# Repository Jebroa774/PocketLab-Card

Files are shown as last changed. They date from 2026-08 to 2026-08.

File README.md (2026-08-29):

# PocketLab Card V1

<p align="center">
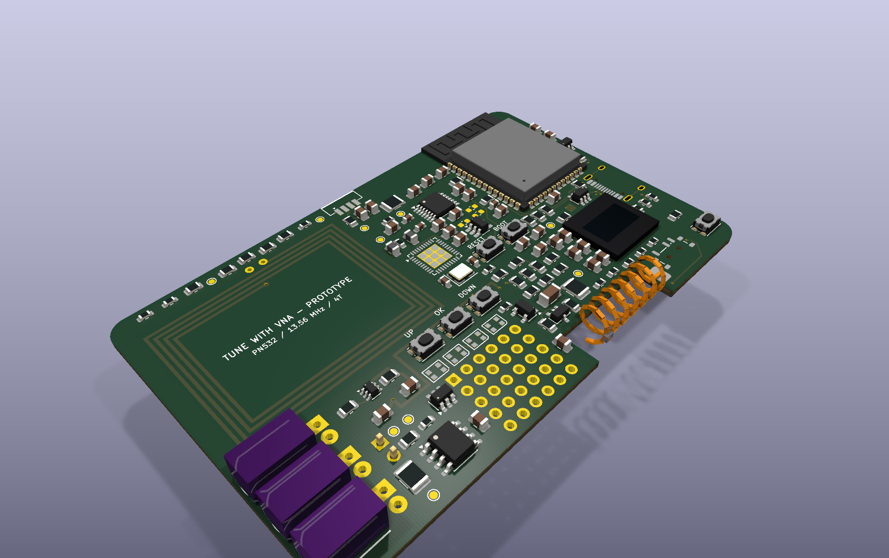
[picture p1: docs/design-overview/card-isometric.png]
PocketLab Card V1 current KiCad isometric view
  
</p>

PocketLab Card V1 is an original, credit-card-outline ESP32-S3 field tool with
Wi-Fi/BLE control, NFC, LF RFID, Sub-GHz, infrared, removable storage and a
small local user interface. The hardware is designed around a four-layer PCB,
a single-cell LiPo supply and parts that can be assembled by JLCPCB or fitted by
hand where practical.

> [!NOTE]
> **Proudly vibe-coded.** The project grows through hands-on experimentation,
> rapid idea-driven iteration and AI-assisted engineering. Here, vibe coding
> does not mean blindly trusting generated output: the hardware remains an
> engineering prototype until its schematic, PCB, DRC/DFM results and physical
> measurements have been independently checked.

> [!WARNING]
> **Engineering prototype — not ready to order.** Placement and electrical
> connectivity are complete: the current routing checkpoint has 0 open
> connection items. It still has 1,164 DRC findings in the saved median run,
> so DRC/DFM cleanup, RF/LF tuning, sourcing review and prototype measurements
> remain required before fabrication.

## Current hardware

| Area | V1 implementation |
|---|---|
| Controller | ESP32-S3-WROOM-1-N8R2 with native USB, Wi-Fi and BLE |
| 13.56 MHz NFC | PN532 with a project-local 35 x 27 mm four-turn PCB antenna |
| 125 kHz LF RFID | HTRC110 front end with a removable, measurable and tuneable coil |
| Sub-GHz | E07-900MM10S/CC1101 module, tuneable pi network and inboard 868 MHz spring antenna |
| Infrared | Three independent high-power 940 nm emitters plus a 38 kHz receiver |
| Storage and security | microSD, ATECC608C secure element and physical PAIR button |
| User interface | Four RGB LEDs, UP/SELECT/DOWN controls and a firmware-configurable AUX button |
| Sensors | Optional 6-axis IMU, barometer, RTC, fuel gauge and board-temperature monitor |
| Power | USB-C, 1-cell LiPo input, charging/power path, regulated 3.3 V and switchable 5 V |
| Expansion | Protected 2.54 mm breakout matrix with eleven direct expansion GPIOs |

The **ESP32-S3 remains the controller for V1**. The newer ESP32-S31 is being
kept as a possible V2 candidate, but its preliminary hardware ecosystem,
larger WROOM module and immature availability do not justify restarting this
layout.

## Current PCB views

The following images were generated from the current KiCad routing checkpoint.
The hand-fitted IR bodies and spring antenna use approximate preview models;
footprints, courtyards and the PCB outline remain the mechanical references.

<table>
  <tr>
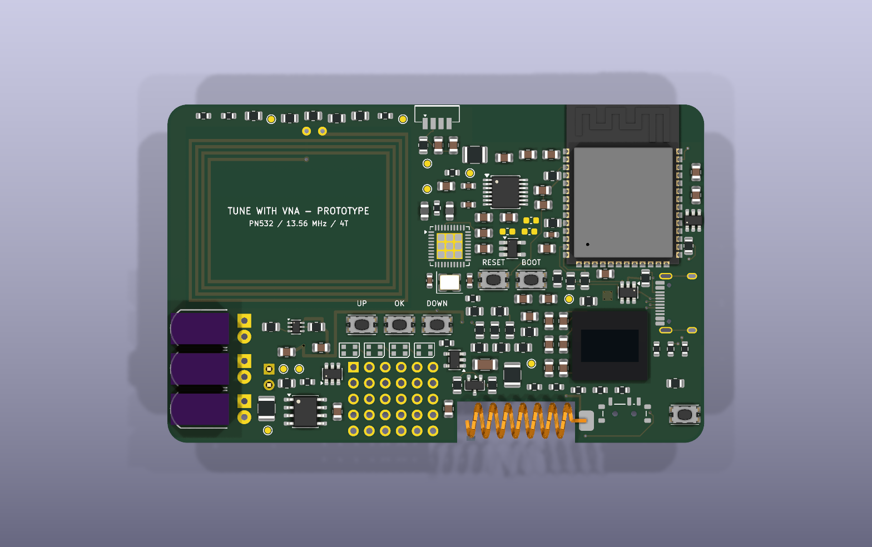
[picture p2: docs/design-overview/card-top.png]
Current PCB top view
    <td align="center"><br><strong>Top</strong></td>
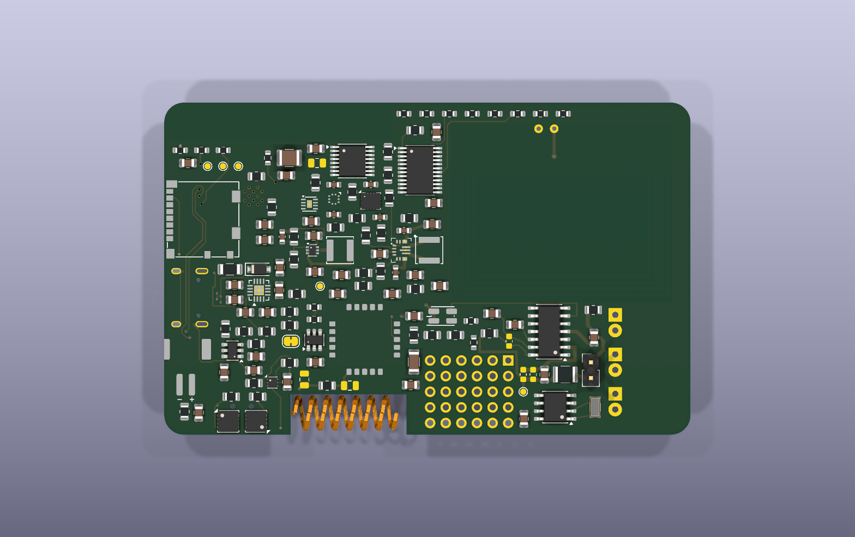
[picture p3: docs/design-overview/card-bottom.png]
Current PCB bottom view
    <td align="center"><br><strong>Bottom</strong></td>
  </tr>
</table>

More layout and enclosure notes are available in the
[design overview](docs/design-overview/README.md).

## Mechanical target

- 85.60 x 53.98 mm credit-card outline with rounded corners
- Four-layer, nominal 1.2 mm FR-4 using the JLC04121H-7628 stack target
- 1 oz outer and 0.5 oz inner copper with ENIG finish
- Components on both sides; approximately 8–9 mm provisional assembled height
- Three inboard edge-facing IR emitters and an inboard spring-antenna pocket
- Compact unpopulated 6 x 5 matrix of 30 holes on 2.54 mm pitch
- Initial bring-up quantity: five assembled prototype boards

This is a credit-card-shaped instrument, not a wallet-thickness card. The final
height and enclosure clearances must be verified against received components.

## Engineering status

| Check | Current result |
|---|---:|
| Schematic symbols | 274 |
| Assigned footprints | 267 |
| Named logical nets | 181 |
| Physical PCB nets | 231 |
| ERC | 0 errors / 0 warnings |
| Placed footprints | 267 / 267 |
| Routed checkpoint | 2843 track segments / 575 vias / 23 zones |
| Remaining connection items | 0 |
| DRC findings (median of three runs) | 1164 |
| Footprint-library comparison findings | 5 |

Completed design work includes the full schematic, mechanical placement,
four-layer stack definition, native USB pair, local converter routes, RTC
crystal routes, the provisional Sub-GHz feed/pi network and the via-free
back-side LF RFID analog island. All logical connection items are now closed;
the active work is reducing the remaining clearance, hole-clearance, short,
crossing, solder-mask and board-edge DRC findings.

### Before the first PCB order

- Confirm the live JLCPCB stack and recalculate USB/Sub-GHz geometry.
- Review the completed LF/NFC and digital routing against the schematic.
- Finish DRC cleanup, ground stitching and plane review.
- Re-run final KiCad DRC/parity checks from a clean checkout.
- Review every footprint, BOM and placement entry against current supplier data.
- Reconfirm PN532 availability because the part is NRND, and qualify an
  alternative before any production revision.
- Inspect the JLCPCB DFM, BOM and CPL previews and obtain an independent review.
- Tune NFC, LF RFID and Sub-GHz on the assembled prototypes with suitable test
  equipment before treating any RF values as production-ready.

The detailed hand-off state is maintained in the
[work checkpoint](docs/work-checkpoint.md).

## Repository layout

```text
PocketLab-Card/
|-- docs/           Architecture, constraints, checkpoints and current renders
|-- hardware/       KiCad source, local libraries, reports and layout helpers
|-- firmware/       ESP32-S3 firmware source and board configuration
`-- manufacturing/  Fabrication/assembly generation tools and future releases
```

Open `hardware/PocketLab-Card.kicad_pro` in KiCad 10 for the complete project.
The tracked `hardware/PocketLab-Card.kicad_pcb` is the current routing-in-progress
board, not a fabrication release.

## Responsible use

RF, RFID/NFC and infrared functions are intended only for devices, systems,
frequencies, antennas, output levels and duty cycles the operator is legally
permitted to use. Prototype RF performance, electromagnetic compatibility and
regulatory compliance have not yet been verified.

The project is original and does not copy SGP branding, artwork, PCB layout or
firmware.

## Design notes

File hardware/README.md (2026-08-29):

# Hardware design source

## Functional blocks

| Logical block | Contents |
|---|---|
| 00_ROOT | Power domains, buses and hierarchical connections |
| 01_USB_POWER | USB-C, ESD, charger, battery, 3.3 V and 5 V conversion |
| 02_MCU | ESP32-S3-WROOM-1 module, boot/reset and native USB |
| 03_NFC | PN532, clock, matching/RX networks and four-turn PCB loop |
| 04_SUBGHZ | E07-900MM10S CC1101 module, tuneable pi network and inboard spring antenna |
| 05_LF_RFID_SD | HTRC110, removable 125 kHz coil, level shifting, ATECC608C, PAIR and microSD |
| 06_IR_UI | IR transmitter/receiver, RGB LEDs and buttons |
| 07_SENSORS_IO | IMU, barometer, RTC, fuel gauge, U9/U18 and headers |

KiCad 10 is installed locally. `PocketLab-Card.kicad_pro` is the project entry
point and the PCB scaffold contains the exact credit-card outline. The current
generated schematic comprises 267 symbols and 176 named logical nets; the
OLED-free PCB candidate contains 260 footprints. `reports/erc-nooled-aux.rpt` reports zero
errors and zero warnings.

The schematic and its machine-readable net description are reproducible with
KiCad's bundled Python:

```powershell
& "$env:LOCALAPPDATA\Programs\KiCad\10.0\bin\python.exe" scripts/generate_schematic.py PocketLab-Card.kicad_sch --design-json design-netlist.json
```

The project-local footprint library includes the manufacturer-derived special
packages and `NFC_Loop_35x27mm_4T_TUNE`. The latter is a four-turn, 0.50/0.50
mm preliminary loop with a 35 x 27 mm copper envelope and a full 36 x 29 mm
all-copper-layer keep-out. Its matching is intentionally not a release value:
measure and tune the populated prototype with the final stack-up, enclosure and
battery using a VNA or suitable NFC fixture.

The tracked `PocketLab-Card.kicad_pcb` remains the authoritative design source.
`PocketLab-Card-routing-working.kicad_pcb` is the explicitly named active routing
checkpoint and is kept only so the verified zero-open state can be resumed without
promoting it prematurely. Other generated placement, plane, autorouter and
routing-progress boards are deliberately not versioned because the scripts below
recreate them from the schematic, mechanical template and current rules.

The current PCB contains the guarded digital autorouter fanout plus reviewed local U6/L6,
U7/L7, converter input/output, U7-feedback, RTC-crystal and complete native USB
data routes; L2 remains the uninterrupted ground plane and L3 retains the
power polygons plus explicitly reviewed low-speed signal crossings. R201/R202 are vertical side-by-side 0805
parts, the MCU-side pair stays via-free, and a staggered five-via bridge joins
J1's alternating A/B data pads. U16 is 0.55 mm farther inboard; front-side
0805 R102 now has its J1-B5 pull-down and local ground return routed. The CC2
protection branch to U16 pin 6 is also complete using two ordinary 0.50/0.30-mm
through vias and outer-layer tracks only. SW3/SW7/SW4 are compact, adjacent UP/OK/DOWN
controls; SELECT uses U9/P07 and the BMP390 remains available by I2C polling.
VSYS is now complete through the charger/converter island; an 0805 zero-ohm
SPI_MOSI crossover preserves the plane-only inner layers. Both J1 VBUS contacts
also reach F1 through reviewed local neckdowns and 0.50/0.60-mm B.Cu copper.
The provisional 868-MHz feed now runs through the correctly oriented pi network
and makes its sole signal-layer transition before the spring pocket; its F.Cu
section remains on the narrow PCB bridge outside the notch. The present
checkpoint has 1889 track segments, 343 vias and 23 zones. Both `+5V_RAW` and
`+5V_AUX` are complete on narrow L3 corridors, the requested 36 dense-plane
clusters are closed, and the reviewed U2.3 GND escape is routed. R405 is
oriented with pad 1 toward U3 and pad 2 toward the antenna. The microSD socket
is now 0.175 mm farther inboard, eliminating its ten copper-to-edge findings.
J5.25 now reaches the complete U25/R732 `SPI_SCK_HDR` protection tree through
a reviewed short L3 crossing. J5.23 reaches U24.1 on `I2C_SDA_HDR`; its separate
R730 branch remains in the ratsnest. A single reviewed `+5V_RAW` stitch via
keeps the power polygon connected around the SCK clearance slot, and L2 remains
ground-only.
The short PN532 `/NFC_TX2_F` matching branch from L302.2 to C309.1 is now
routed via-free on F.Cu through the reviewed 0.25-mm local corridor.
The microSD controller-side `/SD_CS_DEV` leg now reaches J2.2 through one local
via; the adjacent U19.2 GND escape was shifted toward the card edge without
changing its reviewed plane via.
The ESP32 `/SPI_MOSI` pad U1.19 now reaches the existing U21/R129 shared-bus
trunk through eight locked outer-layer segments and one 0.45/0.20-mm via.
R511.1 now joins that same trunk through six locked 0.15-mm L3 segments, one
short F.Cu escape and one 0.45/0.20-mm via. The route preserves the continuous
L2 ground plane and the connectivity of both protected L3 5-V polygons.
The USB-C `/USB_CC1` receptacle pad J1.A5 now reaches its back-side 5.1-kohm
pull-down R101 through one outer-layer transition. U16.4 now joins that same
group through nine locked 0.20-mm F.Cu segments, so the complete CC1 detection
and ESD branch is connected without another via.
The UP-button `/USER_BUTTON_A_N` contact SW3.1 now reaches pull-up R608.1
through one short reviewed L3 crossing and two 0.45/0.20-mm vias; U18.11
remains the explicit second group on that net.
The back-side `/CELL_POS` monitor input U8.3 now reaches local capacitor C120.1
through four short, via-free 0.15-mm B.Cu segments.
The back-side `/CELL_POS` sense input R104.1 now joins the charger/battery
branch through three locked 0.20-mm B.Cu segments, one 0.45/0.20-mm tented via
and five locked 0.20-mm F.Cu segments. The route uses the narrow reviewed gap
between C101 and C117 without cutting any inner-layer power polygon.
The protected `/GPIO43` output R718.2 now reaches expansion-header pad J5.11
through three locked 0.15-mm L3 segments and one 0.45/0.20-mm tented via.
The protected `/SPI_MISO_HDR` branch now joins resistor R734.2 to J5 ESD-array
channel U25.1 through eleven locked 0.15-mm segments, two 0.45/0.20-mm tented
vias and a reviewed L3 corridor; the dedicated L2 GND plane remains untouched.
The PN532 `/NFC_TX1` driver pad U2.4 now reaches matching inductor L301.1
through two short F.Cu escapes, three locked 0.20-mm L3 segments and two
0.45/0.20-mm tented vias. Small reviewed jogs in the neighboring LF clock/data
fanouts preserve their connectivity and keep the dedicated L2 GND plane clean.
The active routing checkpoint contains 2843 track segments, 575 ordinary through
vias and 23 zones. Three fresh KiCad DRC runs report zero open connections and
totals between 1162 and 1166 remaining violations (median 1164). The latest cleanup
reroutes EX4, EX5, CHG_TS_FIXED, GPIO8_MCU and SD_DETECT_N, reassigns CHARGER_CHG_N,
and rehomes the AUX5_FAULT_N and BAT_SENSE vias while preserving connectivity.
The earlier cleanup merges one
redundant same-net NFC_OSCOUT via pair, rehomes two crowded GND vias and eliminates
the remaining hole-to-hole findings (three to zero). A CHG_TS L3 detour reduces the
copper-to-edge findings from five to four. Small conventional-through-via rehomes
also improve CHG_ITERM, NFC_DVDD and IR_TX while preserving the long IR_TX inner
trace; no blind or microvias were introduced. The earlier cleanup removes the PWR
copper sliver and both GPIO8-to-rounded-corner edge findings without introducing a
keepout violation. It also merges redundant BAT_SENSE, NFC_SVDD and SD_SCK via
pairs and makes the local USB_CONN_P join via-free.
The remaining violations still require grouped cleanup; the board is therefore not
an order-ready fabrication release.
The matching machine-readable report is `reports/PocketLab-Card-drc.json`.

The latest PN532 cleanup connects U2.5/U2.8 with a short via-free DVDD escape
and replaces the old west-side U2.3 GND detour with a direct exposed-pad
connection. `scripts/route_nfc_dvdd_escape.py` reproduces that reviewed stage.

The LF_RFID_EN branch now reaches U22.1 through a reviewed L3 signal corridor.
The change reuses the former redundant +3V3 via site, reconnects R109 to the
retained +3V3 fanout and leaves L2 as a ground-only plane.
`scripts/route_lf_enable.py` reproduces and connectivity-checks this stage.

The dense U8/U11 sensor corridor is also reworked. U8 SCL reaches U1.6 through
two standard 0.45/0.20-mm through-vias and a short L3 crossing, while U8 SDA
reaches U11.4 directly on B.Cu. `FG_ALERT_N` and `SPI_MOSI` were rerouted
around the corridor, the local U11 ground branches were restored, and L2
remains ground-only. `scripts/route_i2c_sensor_corridor.py` reproduces and
connectivity-checks all six affected endpoint pairs.

The reproducible routing helpers are:

```powershell
# Regenerate the placement and inner-plane staging boards
& "$env:LOCALAPPDATA\Programs\KiCad\10.0\bin\python.exe" scripts/build_pcb.py
& "$env:LOCALAPPDATA\Programs\KiCad\10.0\bin\python.exe" scripts/add_planes.py

# Export the full routing DSN
& "$env:LOCALAPPDATA\Programs\KiCad\10.0\bin\python.exe" scripts/route_pcb.py --export-only --force

# After a reviewed FreeRouting import, apply the local critical-route checkpoint
& "$env:LOCALAPPDATA\Programs\KiCad\10.0\bin\python.exe" scripts/route_critical.py --force

# Reproduce the reviewed LF_RFID_EN endpoint stage on a candidate board
& "$env:LOCALAPPDATA\Programs\KiCad\10.0\bin\python.exe" scripts/route_lf_enable.py --input PocketLab-Card.kicad_pcb --output PocketLab-Card-lf-enable-candidate.kicad_pcb --force

# Reproduce the reviewed U8/U11 I2C sensor corridor on a candidate board
& "$env:LOCALAPPDATA\Programs\KiCad\10.0\bin\python.exe" scripts/route_i2c_sensor_corridor.py --input PocketLab-Card.kicad_pcb --output PocketLab-Card-i2c-sensor-candidate.kicad_pcb --force

# Reproduce the reviewed via-free PN532 TX2 matching branch
& "$env:LOCALAPPDATA\Programs\KiCad\10.0\bin\python.exe" scripts/route_nfc_tx2_matching.py --input PocketLab-Card.kicad_pcb --output PocketLab-Card-nfc-tx2-matching-candidate.kicad_pcb --force

# Reproduce the reviewed microSD CS socket leg and local U19 GND rehome
& "$env:LOCALAPPDATA\Programs\KiCad\10.0\bin\python.exe" scripts/route_sd_cs_socket.py --input PocketLab-Card.kicad_pcb --output PocketLab-Card-sd-cs-candidate.kicad_pcb --force

# Reproduce the reviewed ESP32-to-shared-trunk SPI-MOSI branch
& "$env:LOCALAPPDATA\Programs\KiCad\10.0\bin\python.exe" scripts/route_spi_mosi_mcu.py --input PocketLab-Card.kicad_pcb --output PocketLab-Card-spi-mosi-mcu-candidate.kicad_pcb --force

# Reproduce the reviewed shared-trunk-to-R511 SPI-MOSI branch
& "$env:LOCALAPPDATA\Programs\KiCad\10.0\bin\python.exe" scripts/route_spi_mosi_sd_resistor.py --input PocketLab-Card.kicad_pcb --output PocketLab-Card-spi-mosi-r511-candidate.kicad_pcb --force

# Reproduce the reviewed U8-to-C120 CELL_POS monitor branch
& "$env:LOCALAPPDATA\Programs\KiCad\10.0\bin\python.exe" scripts/route_cell_pos_monitor.py --input PocketLab-Card.kicad_pcb --output PocketLab-Card-cell-pos-monitor-candidate.kicad_pcb --force

# Reproduce the reviewed R104-to-main CELL_POS sense branch
& "$env:LOCALAPPDATA\Programs\KiCad\10.0\bin\python.exe" scripts/route_cell_pos_sense_branch.py --input PocketLab-Card.kicad_pcb --output PocketLab-Card-cell-pos-sense-candidate.kicad_pcb --force

# Reproduce the reviewed protected GPIO43-to-header branch
& "$env:LOCALAPPDATA\Programs\KiCad\10.0\bin\python.exe" scripts/route_gpio43_header.py --input PocketLab-Card.kicad_pcb --output PocketLab-Card-gpio43-header-candidate.kicad_pcb --force

# Reproduce the reviewed protected SPI-MISO resistor-to-ESD branch
& "$env:LOCALAPPDATA\Programs\KiCad\10.0\bin\python.exe" scripts/route_spi_miso_header_esd.py --input PocketLab-Card.kicad_pcb --output PocketLab-Card-spi-miso-header-esd-candidate.kicad_pcb --force

# Reproduce the reviewed PN532 TX1 driver-to-inductor branch
& "$env:LOCALAPPDATA\Programs\KiCad\10.0\bin\python.exe" scripts/route_nfc_tx1_driver.py --input PocketLab-Card.kicad_pcb --output PocketLab-Card-nfc-tx1-candidate.kicad_pcb --force

# Reproduce the reviewed USB-C CC1 receptacle-to-pull-down path
& "$env:LOCALAPPDATA\Programs\KiCad\10.0\bin\python.exe" scripts/route_usb_cc1_resistor.py --input PocketLab-Card.kicad_pcb --output PocketLab-Card-usb-cc1-resistor-candidate.kicad_pcb --force

# Reproduce the reviewed USB-C CC1 receptacle-to-U16 ESD branch
& "$env:LOCALAPPDATA\Programs\KiCad\10.0\bin\python.exe" scripts/route_usb_cc1_esd_branch.py --input PocketLab-Card.kicad_pcb --output PocketLab-Card-usb-cc1-esd-candidate.kicad_pcb --force

# Reproduce the reviewed UP-button contact-to-pull-up path
& "$env:LOCALAPPDATA\Programs\KiCad\10.0\bin\python.exe" scripts/route_user_button_a_pullup.py --input PocketLab-Card.kicad_pcb --output PocketLab-Card-user-button-a-candidate.kicad_pcb --force

# Reproduce the reviewed J5 SDA/SCK protection checkpoint as a candidate chain
& "$env:LOCALAPPDATA\Programs\KiCad\10.0\bin\python.exe" scripts/route_header_bus_protection.py --input PocketLab-Card.kicad_pcb --output PocketLab-Card-header-protection-candidate.kicad_pcb --force
& "$env:LOCALAPPDATA\Programs\KiCad\10.0\bin\python.exe" scripts/rehome_header_neck_fanouts.py --input PocketLab-Card-header-protection-candidate.kicad_pcb --output PocketLab-Card-header-neck-candidate.kicad_pcb --force
& "$env:LOCALAPPDATA\Programs\KiCad\10.0\bin\python.exe" scripts/route_header_sck_bridge.py --input PocketLab-Card-header-neck-candidate.kicad_pcb --output PocketLab-Card-header-sck-bridge-candidate.kicad_pcb --force
& "$env:LOCALAPPDATA\Programs\KiCad\10.0\bin\python.exe" scripts/bridge_header_sck_power_cut.py --input PocketLab-Card-header-sck-bridge-candidate.kicad_pcb --output PocketLab-Card-header-sck-power-candidate.kicad_pcb --force
```

`route_pcb.py` can also run FreeRouting 2.3 with `--jar` and `--java`. Its
separate autorouter DSN physically removes all 42 protected power, USB, RF,
LF and sensitive nets before routing and the SES importer verifies them again.
All files produced by this staging pipeline are ignored by Git; only a deliberately
reviewed result is promoted to `PocketLab-Card.kicad_pcb`.

## Required layout, sourcing and bring-up checks

- USB-C CC resistors and native USB differential pair protection
- Correct ESP32 boot straps and antenna keep-out
- BQ24074 input/current/thermal programming and LiPo polarity
- Stable 3.3 V and 5 V converter compensation/layout per reference designs
- 5 V header current limiting and output discharge
- PN532 DVDD-derived AVDD/TVDD supplies, RX network and measured antenna tuning
- E07-900MM10S pin map, short 50-ohm feed, tuneable pi network and measured 868 MHz spring match; the present lower-right digital corridors must be rearranged before that RF feed is committed
- 18.8 x 6.58 mm spring pocket, 0.6 mm PCB bridge to the sole electrical antenna pad, and a second nonconductive adhesive anchor at the free end
- HTRC110 5 V sequencing, protected short resonant loop and measured 125 kHz coil tuning
- ATECC608C wake/provisioning flow and physical PAIR-button ownership gate
- microSD pull-ups, 47 uF write-transient bulk capacitance and U19 ESD array
- U24/U25 shunt ESD arrays on all five exposed J5 I2C/SPI bus lines
- 100 ohm series protection on 11 direct GPIOs, the GPIO9 temperature probe,
  and the exposed I2C/SPI buses
- R736/RT701 10-kohm divider on GPIO9 for local power-zone temperature
- 220 ohm series protection on all eight expander GPIOs
- optional external 10-kohm NTC on J5 pins 28/30, selected by cutting SJ1
- SW8/KXT311LHS active-low AUX input on ESP32-S3 GPIO21; firmware enables the internal pull-up
- SW5 low-current main switch on the TPS63070 enable path
- three independent TSAL6200 current-limit branches and fully inboard formed leads/lenses
- VBUS_USB, VBUS_FUSED, VSYS, +3V3, +5V_RAW and +5V_AUX test points

See `docs/assembly-strategy.md` before selecting or placing any footprint.

## PCB stack target

Four-layer, nominal 1.2 mm FR-4, encoded for the JLC04121H-7628 target:

1. L1: components, RF and short high-speed signals
2. L2: uninterrupted ground plane
3. L3: power polygons and reviewed low-speed signal crossings
4. L4: components and low-speed routing

The encoded build uses 35-um outer copper, 15.2-um inner copper, two 0.2104-mm
7628 prepregs and a 0.665-mm core. USB and Sub-GHz impedance geometry remains
provisional; the LF resonant network must be measured with the actual external
coil and final enclosure before its capacitor values are released.

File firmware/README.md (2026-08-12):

# PocketLab Card firmware

Buildable ESP32-S3 bring-up firmware for hardware revision 1. It targets the
ESP32-S3-WROOM-1-N8R2 with Arduino-ESP32 3.x and PlatformIO.

## Implemented baseline

- WPA2 Wi-Fi SoftAP, REST API, read-only WebSocket status and mobile web UI
- microSD mount, listing, download, upload, deletion and remount
- safe boot states for CC1101, microSD, IR, RGB, LF RFID and exposed GPIOs
- read-only CC1101 identity, PN532 presence and both I/O-expander probes
- HTRC110 5 V power sequencing, three-wire command transport, configuration
  readback, phase/sampling setup and antenna-failure diagnosis
- ATECC608C wake/presence probe without changing or locking its configuration
- physical PAIR-button gate for a 60-second pairing window
- bounded NEC IR transmission through the three emitters
- 16-sample GPIO9 board-NTC measurement, web status and 80-degree-C thermal
  shutdown of charging and 5-V loads with 70-degree-C release hysteresis

Tag protocol framing/decoding, secure-element provisioning, persistent owner
keys, the phone app, PN532 transactions, CC1101 receive/decoding, IR decoding,
sensor drivers and battery telemetry remain separate follow-up work. In
particular, an open pairing window is not yet an owner lock.

## Build

```powershell
pio run
pio run -t upload
pio device monitor
```

The 2026-08-11 validation used Arduino-ESP32 3.3.8 and WebSockets 2.7.3. The
release build used 49,568 bytes RAM and 1,113,399 bytes application flash.

At boot, USB CDC prints the generated prototype access point credentials and
`http://192.168.4.1/`. The per-device password and boot-session HTTP token are
for local bring-up; they are not a substitute for the later ATECC-backed app
authentication protocol.

## Safety policy

`platformio.ini` enables only bounded IR transmission. Sub-GHz transmission
and arbitrary GPIO outputs stay compiled out. LF RFID powers up only on an
authenticated local request: the 5 V boost is enabled first, then the HTRC110
rail; shutdown happens in the reverse order. HTRC tag writing is not exposed.
The internal NTC blocks new LF/boost/IR requests at 80 degrees C, disables
charging and existing 5-V loads, and releases only the charger below 70 degrees
C. Loads remain off until the app explicitly requests them again.
An open or shorted divider is treated fail-safe like an overtemperature event.

## HTTP interface

Read-only endpoints include `/healthz`, `/api/config`, `/api/status`,
`/api/hardware`, `/api/gpio`, `/api/files` and `/api/file`.

Mutations require the current `X-PocketLab-Token` header:

| Method | Path | Purpose |
|---|---|---|
| `POST` | `/api/lf/power?enabled=1` | Sequence LF 5 V and run the HTRC self-test |
| `POST` | `/api/lf/diagnose` | Repeat configuration, phase and antenna checks |
| `POST` | `/api/security/pairing-window` | Open 60 s only while PAIR is held and ATECC is present |
| `POST` | `/api/ir/tx?address=0&command=0&repeats=0` | Send one bounded NEC frame |
| `POST` | `/api/sd/remount` | Remount microSD |
| `POST` | `/api/upload?path=/uploads/name` | Upload a file |
| `DELETE` | `/api/file?path=/uploads/name` | Delete a file or empty directory |

## First-board checks

- U9/TCA9535 at `0x20`, U18/TCA9534 at `0x21`, PN532 at `0x24`
- ATECC608C-SSHDA default address `0x60`; keep it unprovisioned until the app
  key format, recovery process and production lock manifest are reviewed
- U18 P4 is `LF_RFID_EN`; boot latch keeps LF 5 V and boost off
- LF pins: GPIO18 SCLK, GPIO21 DOUT, GPIO35 DIN; GPIO38 is active-low PAIR
- GPIO9 is the internal board-temperature ADC and J5 pin 7 is probe-only
- HTRC110 page readback, `ANTFAIL`, measured phase and tuned external coil
- CC1101 identity and shared-SPI chip-select idle levels

`include/board_pins.h` mirrors `docs/pinout.md`.

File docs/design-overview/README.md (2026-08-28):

# PocketLab Card design overview

These KiCad renders show the placement of the current design, not the final
fabrication appearance. Placement is complete, but 138 connection items remain
open. The IR bodies and spring antenna use approximate mechanical preview
models; the footprint courtyards and board outline remain the manufacturing
references. RF stitching, several sensitive routes and final enclosure
clearances are still open.

## Current views

Current isometric view

| Top | Bottom |
|---|---|
| Current top view | Current bottom view |

The ESP32-S3-WROOM-1-N8R2 shown here remains the V1 controller. ESP32-S31 is a
future V2 candidate and is not part of this PCB revision.

## Visible front-side areas

| Area | Current contents | Enclosure / artwork guidance |
|---|---|---|
| Upper-left | 35 x 27 mm NFC loop | Good visual focus for a printed logo or non-metallic graphic. Do not add metal foil, magnets, conductive paint, screws or a battery over the loop. |
| Upper-right | ESP32-S3 module and PCB antenna | Plastic and ordinary non-conductive ink only around the antenna end. No metal bezel, shield, battery or cable directly over it. |
| Top edge | Side-view 38 kHz IR receiver | Keep a small dark IR-transparent window over its optical face. The body and pads remain inside the card outline. |
| Lower-right | AUX/PAIR buttons, main switch and USB area | Provide switch openings and USB access. The battery connector is on the back; the removed OLED area is routing and enclosure reserve. |
| Lower-middle | Four 2-mm RGB LEDs, compact UP/OK/DOWN buttons, and adjacent labeled RESET/BOOT service buttons | Use four small windows or one frosted light bar. A three-position membrane can cover the navigation row; keep RESET/BOOT accessible through small service holes. |
| Left short edge | Three flat TSAL6200 IR emitters | All optical faces sit 0.5 mm inside the edge and the lowest body clears the rounded corner. Each vertical 2.54-mm pad pair gives both leads one common 90-degree bend line. Provide one clear opening across the three lenses. |
| Lower edge | Compact 6 x 5 Dupont hole matrix | All 30 connections retain 2.54 mm pitch. Individual Dupont leads and breakaway strips fit; one monolithic 2 x 15 housing does not. |
| Lower-right pocket | 868 MHz helical spring antenna | The 17.3 mm cylindrical spring lies inside an 18.8 x 6.58 mm recess. Its right end is the only electrical solder point; a small nonconductive epoxy or neutral-cure silicone bridge anchors the free left end to the upper FR4 pocket wall. Never solder or ground that free end. Neither spring nor pad exceeds the original card envelope. |

## Back side

The back carries power conversion, protection, sensors, RTC, I/O expanders,
the two-part board-temperature divider beside the 5-V converter,
the removable 125 kHz coil connector, the via-free HTRC110 analog island and
the Sub-GHz module. It is not a flat cosmetic surface. The large apparently
empty region opposite the NFC loop must also remain free of metal and major
components; it is an RF keepout, not spare battery space.

## Practical styling directions

1. **Exposed technical card:** black solder mask, white silkscreen, visible NFC
   loop and translucent RGB light bar.
2. **Thin two-piece shell:** solid front graphic with windows only for buttons,
   RGB, IR and connectors; the PCB remains serviceable from the back.
3. **Instrument style:** label the four RGB/button positions as modes, use the
   NFC loop as a framed graphic field and use RGB patterns for compact status.

The bare PCB is 85.60 x 53.98 x 1.2 mm. The final assembly is not wallet-flat:
without the optional Dupont header, allow roughly 8-9 mm overall until exact
received-part and enclosure measurements replace this provisional envelope.

## Verification status

The current placement and retained routing pass the scripted component/keepout
audit. Schematic parity and ERC are clean. KiCad DRC reports 16 documented
non-release findings covering native fine-pitch clearances, one J4 edge-mounted
copper item, footprint-library checks and one copper-sliver warning. The 138 unconnected
items are the explicit routing blocker, so this revision
must not be sent to fabrication yet.

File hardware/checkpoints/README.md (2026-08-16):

# Reviewed work-in-progress checkpoints

This directory stores deliberate pause/review snapshots only.  The main
`hardware/PocketLab-Card.kicad_pcb` remains authoritative until a checkpoint
has passed the documented parity, DRC, mechanical and manufacturing reviews.

`PocketLab-Card-pcba-routing-wip.kicad_pcb` is the 2026-08-17 direct-assembly
and routing checkpoint.  Its accompanying JSON report records the last full
project-context DRC result: 46 findings and 158 open connection items.  It is
not order-ready.

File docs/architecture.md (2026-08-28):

# Hardware architecture

## System block diagram

```mermaid
flowchart LR
    USB[USB-C 5 V + USB 2.0] --> CHG[BQ24074 charger and power path]
    BAT[External protected 1S LiPo] <--> CHG
    CHG --> SYS[VSYS 3.0-4.4 V]
    SYS --> REG33[TPS63070 3.3 V buck-boost]
    SYS --> REG5[TPS61023 switchable 5 V boost]

    REG33 --> MCU[ESP32-S3-WROOM-1-N8R2]
    REG33 --> NFC[PN532 + NFC loop]
    REG33 --> SUB[E07-900MM10S CC1101 module + spring antenna]
    REG33 --> SEC[ATECC608C + PAIR button]
    REG33 --> SD[microSD]
    REG33 --> SENS[IMU + barometer + RTC + fuel gauge]
    REG33 --> TEMP[10-k NTC board-temperature divider]
    REG33 --> IOX[TCA9535 status/expansion I/O]
    REG33 --> CTL[TCA9534 internal control I/O]

    REG5 --> RAW[+5V_RAW]
    RAW --> IR[940 nm IR driver]
    RAW --> RGB[RGB LEDs via AHCT data buffer]
    RAW --> LIM[TPS2553 current-limited switch]
    RAW --> LFSW[TPS22919 switched LF_5V]
    LFSW --> LF[HTRC110 + removable 125 kHz coil]
    LIM --> AUX[+5V_AUX expansion output]

    MCU <-->|I2C| NFC
    MCU <-->|I2C| SENS
    MCU <-->|I2C| IOX
    MCU <-->|I2C| CTL
    TEMP -->|GPIO9 ADC| MCU
    AUXBTN[Firmware-configurable AUX button] -->|GPIO21 active low| MCU
    MCU <-->|Shared SPI| SUB
    MCU <-->|Shared SPI| SD
    MCU <-->|3-wire level shifted| LF
    MCU --> WEB[Local Wi-Fi web interface]
```

## Power domains

| Domain | Nominal voltage | Source | Main loads |
|---|---:|---|---|
| VBUS | 5 V | USB-C | Charger input only |
| VBAT | 3.0-4.2 V | External 1S LiPo | Charger/power path |
| VSYS | 3.0-4.4 V | BQ24074 power path | DC/DC inputs |
| +3V3 | 3.3 V | TPS63070 | MCU, radios, storage, sensors |
| +5V_RAW | 5.0 V switchable | TPS61023 | IR driver, RGB LEDs and TPS2553 input |
| +5V_AUX | 5.0 V protected | TPS2553 from +5V_RAW | J5 pin 29 only |
| LF_5V | 5.0 V switched | TPS22919 from +5V_RAW | HTRC110, oscillator and AHCT level shifter |

The 5 V converter is disabled by default. Firmware enables it only for IR,
RGB illumination or an explicitly requested auxiliary load. IR and the RGB
LED supply are connected directly to `+5V_RAW`; only the external `+5V_AUX`
header pin is downstream of the TPS2553
current-limited switch and targeted at 500 mA maximum. Firmware must arbitrate
the combined boost load, while the hardware header current limit remains
independent of firmware.

`RGB_DATA` passes through a 5-V SN74AHCT1G126 before the first LED. The
buffer's active-high output enable is tied to `BOOST5_EN`; the output is
high-impedance whenever the boost is off, avoiding back-power through the LED
data input.

SW5 is the main user power switch, but it does not carry battery or USB charge
current. It switches the TPS63070 enable node between `PWR_SW_ON` and GND;
R735 holds that node low while off. The BQ24074 charger, protection circuit and
USB power path therefore remain available for safe charging while the 3.3-V
system rail and all dependent functions are off.

## Digital buses

| Bus | Devices | Notes |
|---|---|---|
| I2C | PN532, TCA9535, TCA9534, optional BMI270/BMP390, PCF8563, MAX17048 | 3.3 V, one 3.3-kohm pull-up pair, 400 kHz target |
| SPI | E07 CC1101 module, microSD | Shared SCK/MOSI/MISO, dedicated chip selects |
| LF three-wire | HTRC110 | Shared SPI SCK/MOSI/MISO through partial-power-down level shifters; firmware arbitrates LF access |
| USB | ESP32-S3 native USB | Firmware upload, CDC and optional HID |

## RF floorplan rules

1. Put the ESP32 module antenna at a short board edge and respect its
   all-layer keep-out.
2. Keep the HTRC110 resonant bridge, current limiter, RX divider and coil
   connector in one short outer-layer loop; keep switch nodes away from RX.
3. Keep the E07-900MM10S module close to the lower-edge matching network. Pin 6
   feeds the C403/R405/C404 pi network and the hand-soldered T3-868M spring;
   the complete spring lies inside the milled pocket and card envelope.
4. Use a smaller NFC loop around the opposite half of the card instead of a
   full-board loop, avoiding the Wi-Fi and Sub-GHz antenna zones.
5. Provide an NFC matching-network population option on the first prototype.
   The 35 x 27 mm, four-turn loop and its 36 x 29 mm keep-out are preliminary;
   tune the assembled board with a VNA. The E07 module contains its own CC1101
   crystal and internal module-level network, while the external pi remains a
   board/antenna tuning provision.
6. The selected E07-900MM10S is populated for the EU 868 MHz build. A different
   regional variant is a separately reviewed assembly choice, not an automatic
   substitution; antenna, firmware limits and local rules must match it.

## 125 kHz LF antenna configuration

J3 accepts a removable nominal 400-uH coil. C505 isolates the external coil
path, R502 limits fault/current stress, C506 is the 3.9-nF starting resonance
value and C507/C508 are DNP trim sites. R503 provides the protected return and
R504 divides the antenna tap for HTRC110 RX. These values are a bring-up
starting point only: measure actual inductance, Q, phase, coil current and tap
voltage before fitting final values or attempting tag write modes.

## Firmware power arbitration

The following high-load combinations must be limited:

- High-power IR dims the RGB LEDs and blocks concurrent NFC field operation.
- The protected 5 V header is disabled or load-limited by policy while an IR
  burst uses the shared +5V_RAW boost capacity.
- microSD writes are buffered during IR bursts.
- Low-battery mode disables high-power IR and reduces Wi-Fi transmit power.

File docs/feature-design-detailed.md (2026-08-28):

# Detailed feature design baseline

This document is the schematic and layout baseline for the non-power feature
blocks. It is deliberately more specific than the architecture notes, but it
is **not** a fabrication release: NFC tuning, controlled-impedance geometry,
antenna selection, ERC/DRC, and a first-article review remain mandatory.

The current dense layout plan uses two-sided JLCPCB PCBA. Parts with hidden
pads, LGA, fine-pitch FPC, and the microSD connector are factory-only. General passives
remain 0805; 0603 is used only where RF performance or package geometry
requires it.

## Board-wide interface rules

- `+3V3` is the logic rail. No ESP32, TCA9535, sensor, SD, or radio I/O is
  5 V tolerant.
- Fit one shared I2C pull-up pair only. Use 3.3 kOhm to `+3V3` as the default
  because the PN532 reference design uses 3.3 kOhm at 3.3 V. A 4.7 kOhm
  alternative is allowed only if measured SDA/SCL rise time remains below
  300 ns at 400 kHz with the assembled board and expansion header unloaded.
- The shared SPI bus is limited to 8 MHz in the first firmware because the E07
  module is specified to 10 MHz and the microSD branch increases bus loading.
  The captured Sub-GHz and microSD branches use 22-ohm damping resistors.
- Every J5 digital net has a populated series stage: 100 ohm on the 11 direct
  GPIOs, the GPIO9 board-temperature probe and exposed I2C/SPI buses; 220 ohm
  on EX0-EX7. U24/U25 add shunt ESD
  protection to the five shared I2C/SPI header nets. The remaining direct and
  expander GPIO resistors do not replace a connector-side protection device if
  the deployment requires full-port ESD or overvoltage tolerance.
- All RF values below are initial values, not promises of a tuned antenna.
  C0G/NP0 capacitors and high-Q RF inductors are required.

GPIO9/ADC1_CH8 is reserved for R736/RT701, a 10-kohm/10-kohm board-temperature
divider located beside the 5-V converter area. J5 pin 7 reaches the same node
through R714 as a measurement point only; external circuitry must remain
high-impedance and must never drive this pin.

## U2 PN532 NFC controller

The PN532 is retained because it matches the requested feature set and has a
known software ecosystem. NXP marks it **not recommended for new designs** and
recommends PN7160 for new products. Keep the NFC sheet sufficiently isolated
that a future controller revision is possible.

The PN532 I2C address is 0x24 in 7-bit notation (0x48 as the write address byte
used in older NXP documentation).

Official references:

- [PN532/C1 data sheet](https://www.nxp.com/docs/en/nxp/data-sheets/PN532_C1.pdf)
- [PN532 C106 application note](https://www.nxp.com/docs/en/nxp/application-notes/153710.pdf)
- [NXP NFC antenna design hub](https://www.nxp.com/products/rfid-nfc/nfc-hf/nfc-readers/nfc-antenna-design-hub%3ANFC-ANTENNA-DESIGN-TOOL)

### PN532 pin-to-net table (I2C mode)

| Pin | Name | Connection |
|---:|---|---|
| 1 | DVSS | GND |
| 2 | LOADMOD | NC; test pad only if card-emulation experiments require it |
| 3, 7 | TVSS1, TVSS2 | GND with short, separate returns into the local ground area |
| 4, 6 | TX1, TX2 | Symmetrical antenna matching network, then the PCB loop |
| 5 | TVDD | `DVDD`; 4.7 uF + 100 nF locally |
| 8 | AVDD | `DVDD`; 100 nF locally |
| 9 | VMID | C301 100 nF to GND |
| 10 | RX | C318 1 nF from `NFC_RX_AC`; R306 1 kOhm from VMID to RX |
| 11 | AVSS | GND; join local ground at exposed-pad region |
| 12, 13 | AUX1, AUX2 | NC/test pads only |
| 14, 15 | OSCIN, OSCOUT | 27.12 MHz crystal, two 22 pF load footprints; verify actual crystal CL |
| 16 | I0 | `DVDD` (selects I2C together with I1 low) |
| 17 | I1 | GND |
| 18 | TESTEN | GND |
| 19 | P35 | NC; quasi-bidirectional default is high, no external resistor required |
| 20, 21, 22 | NC | NC |
| 23 | PVDD | `+3V3`; 100 nF at pin |
| 24 | P30/UART_RX | NC |
| 25 | P70_IRQ | `NFC_IRQ_N` / ESP GPIO7; optional DNP 10 kOhm pull-up |
| 26 | RSTOUT_N | Test pad, otherwise NC |
| 27 | P50_SCL | `I2C_SCL` |
| 28 | SDA | `I2C_SDA` |
| 29, 30 | MISO/P71, SCK/P72 | NC in I2C mode |
| 31-36 | P31, P32, P33, P34, SIGOUT, SIGIN | NC |
| 37 | SVDD | 100 nF to GND; no external load |
| 38 | RSTPD_N | `NFC_RESET_N` from U18/TCA9534 P3; R302 10 kOhm pulldown |
| 39 | DVDD | Internal LDO output; **do not connect to +3V3**; 10 uF + 100 nF |
| 40 | VBAT | `+3V3`; 4.7 uF + 100 nF |
| EP | exposed pad | GND, paste-windowed, thermal vias into local ground |

`DVDD` is generated by the PN532 internal LDO. In the captured schematic pins
5/TVDD, 8/AVDD and 39/DVDD are directly on `NFC_DVDD`, with separate local
decoupling: C313/C304 at DVDD, C314/C315 at TVDD and C302 at AVDD. DVDD must
never be tied to the external +3V3 input. The two 560 nH inductors are the
TX1/TX2 EMC filter inductors, **not** supply inductors.

The implemented receive branch follows the NXP application diagram topology:
`NFC_LOOP_A -> R305 2.7 kOhm -> NFC_RX_AC -> C318 1 nF -> RX`, while R306
1 kOhm biases RX from VMID. C301 100 nF decouples VMID to GND. These parts must stay
close to U2 and the matching network.

### Antenna and matching implementation

Use the symmetrical NXP starting topology on both TX paths:

- `TX1/TX2 -> L0 -> matching network -> loop`, with `L0 = 560 nH` and
  `C0 = 220 pF` on each side as the initial EMC-filter values.
- R303/R304 are removable 0-ohm links between the EMC network and the loop.
  C310 (differential) and C311/C312 (each side to GND) are DNP C0G tuning
  positions. Their eventual values must be derived from measurements, not from
  the placeholder schematic.
- AE1 pads 1/2 and the removable links provide access for bare-loop and network
  measurements during prototype tuning.

PCB-loop prototype geometry inside the reserved NFC area:

| Parameter | Initial value |
|---|---:|
| Copper envelope | 35.0 x 27.0 mm |
| Full foreign-copper/footprint keep-out | 36.0 x 29.0 mm |
| Turns | 4 |
| Track width | 0.50 mm |
| Gap | 0.50 mm |
| Resulting inner opening | about 28.0 x 20.0 mm |
| Main winding | F.Cu, with one short B.Cu crossover through plated pads |

The project-local `PocketLab_Custom:NFC_Loop_35x27mm_4T_TUNE` footprint embeds
the 36 x 29 mm keep-out for foreign tracks, vias, pads, pours and footprints on
F.Cu, B.Cu, In1.Cu and In2.Cu, with only small relief for its own terminals and
crossover. Do not route planes, switch-node copper, USB, SPI or another RF path
through it. Keep the matching network immediately beside the loop terminals
and use symmetrical, equal-length connections.

Before release, measure loop inductance and Q with the final stackup and
enclosure, tune the complete differential network at 13.56 MHz with a VNA or
NFC tuning fixture, then verify field strength, load modulation, detuning by a
card/phone, and PN532 TVDD current below its 150 mA maximum.

## U3 E07-900MM10S Sub-GHz module

Official references:

- [E07-900MM10S product page](https://www.ebyte.com/product/1959.html)

The module is 10 x 10 mm, uses 1.27 mm castellated-pad pitch, operates from
2.5 V to 3.6 V, and contains the CC1101 crystal and internal RF network.

| Pin(s) | Function | Connection |
|---:|---|---|
| 1 | VCC | `+3V3`; local 4.7 uF + 100 nF |
| 2, 7, 16 | GND | GND with short stitching vias |
| 3-5, 8-11, 17, 19 | NC | Leave unconnected as specified |
| 6 | ANT | `SUBGHZ_RF_MOD` into C403/R405/C404 and A1 |
| 12 | MISO/GDO1 | `SUB_MISO`, then R403 22 ohm to `SPI_MISO` |
| 13 | MOSI | `SPI_MOSI` through R129 0 ohm crossover and R402 22 ohm |
| 14 | CSN | `SUB_CS_N`; R404 22 ohm and R406 100-kohm pull-up |
| 15 | SCK | `SPI_SCK` through R401 22 ohm |
| 18 | GDO0 | `SUBGHZ_GDO0` / GPIO15 |
| 20 | GDO2 | `SUBGHZ_GDO2` / GPIO16 |

Pin 6 reaches the antenna through a tuneable pi network: C403 and C404 are DNP
shunt sites and R405 is the initial 0-ohm series element. A1 is a hand-soldered
T3-868M spring. Its 17.3-mm body lies in an 18.8 x 6.58 mm open-bottom pocket;
a 0.6-mm PCB bridge provides the required copper-to-edge clearance before the
adjacent pad. That right-hand pad is the only electrical connection. After
soldering and inspection, bond the free left end to the upper FR4 pocket wall
with a small amount of nonconductive epoxy or neutral-cure silicone. This gives
two-point mechanical support without shorting the monopole or deliberately
adding a capacitive second copper pad. Perform final S11 tuning after the bond
has cured and with the enclosure and battery fitted.

Keep a solid GND reference below the module and up to the controlled RF launch,
then keep copper, vias, fast digital routes, switch nodes, the battery and
enclosure metal out of the spring volume. The external match is a prototype
starting point: measure S11 with the final PCB stack, enclosure and battery,
then populate C403/R405/C404 from measured evidence.
Frequency, power, antenna, and duty cycle must be configured for the legal regional band;
the 868 MHz build is not a universal-frequency transmitter, and successful
prototype operation is not proof of regulatory compliance.

## U4 HTRC110 125 kHz LF-RFID and secure pairing

Official references:

- [NXP HTRC110 data sheet](https://www.nxp.com/docs/en/data-sheet/037031.pdf)
- [NXP AN98080 HTRC110 application note](https://www.nxp.com/docs/en/application-note/AN98080.pdf)
- [Microchip ATECC608C product page](https://www.microchip.com/en-us/product/atecc608c)

U4 is powered from switched `LF_5V`; U17/TPS22919 is enabled by U18 P4 only
after the 5-V boost is stable. Y501 supplies the permitted 4-MHz CMOS clock.
GPIO18 SCLK and GPIO35 DIN pass through U21/SN74AHCT125 for valid 5-V logic;
U4 DOUT returns through U22/SN74LVC1G126 to the shared SPI MISO line. MODE is grounded for the
normal short local serial interface.

### Resonant path

J3 is a 2.54-mm two-pin connector for a removable nominal 400-uH coil. C505
provides coil-path isolation, R502 is a 47-ohm pulse-rated starting current
limit and C506 is the fitted 3.9-nF C0G starting resonance value. C507/C508 are
100-pF/220-pF C0G DNP trim pads. R503 provides a 1-kohm protected return and
R504 is the 150-kohm RX divider; C509 is an optional DNP RX EMI trim.

Route `LF_TX1`, `LF_TX2`, `LF_ANT_A`, `LF_ANT_B` and `LF_TAP` as one short,
wide, via-free outer-layer loop. Keep `LF_RX`, `LF_QGND` and `LF_CEXT` short
and away from switching nodes. The 3.9-nF/400-uH combination is not an order
value: measure coil inductance and Q, phase, peak current, tap voltage and
HTRC110 `ANTFAIL` on the assembled prototype before final capacitor selection.

### Secure element and PAIR button

U23 is the hand-reworkable SOIC-8 ATECC608C-SSHDA-T on the shared I2C bus.
SW6 pulls `PAIR_N`/GPIO38 low. Development boards ship with the secure element
unprovisioned; locking its zones and enabling ESP32 secure-boot/flash-encryption
eFuses are irreversible production steps requiring a reviewed key manifest,
recovery procedure and app protocol. Firmware may open a short pairing window
only while SW6 is physically held, but this alone is not persistent ownership.

## J2 microSD (Molex 104031-0811)

Official references:

- [Molex 104031 series](https://www.molex.com/en-us/products/series-chart/104031)
- [SD Association simplified specifications](https://www.sdcard.org/downloads/pls/)

The selected connector is the Molex 104031-0811 push-pull, 1.42 mm-high socket
with card-detect switch. It occupies about 11.91 x 11.4 mm; the KiCad official
footprint courtyard is approximately 13.68 x 13.05 mm. Preserve a clear card
insertion/removal corridor to the board edge.

| microSD pin | Native name | SPI-mode connection |
|---:|---|---|
| 1 | DAT2 | 47 kOhm pull-up to +3V3, otherwise unused |
| 2 | CD/DAT3 | `SD_CS_N` / GPIO17 through R510 22 ohm; R515 47-kohm pull-up |
| 3 | CMD | `SPI_MOSI` through R511 22 ohm; R516 47-kohm pull-up |
| 4 | VDD | `+3V3`; 100 nF + 10 uF + 47 uF low-ESR near socket |
| 5 | CLK | `SPI_SCK` through R512 22 ohm |
| 6 | VSS | GND |
| 7 | DAT0 | `SPI_MISO` through R513 22 ohm; R517 47-kohm pull-up |
| 8 | DAT1 | 47 kOhm pull-up, otherwise unused |
| 9/10 | detect switch | One side GND, other `SD_DETECT_N` + 10 kOhm pull-up |
| shell | shield | GND with multiple short vias |

The detect switch is isolated and its two contacts are electrically
interchangeable, but pad numbering still has to match the Molex drawing and
official KiCad footprint. U19 (`SRV05-4MR6T1G`) clamps CS, MOSI, SCK and MISO;
place it at the socket side of R510-R513. C510 100 nF, C511 10 uF and C512
47 uF/6.3 V low-ESR provide local write-transient decoupling. Keep the SD
branch short and star-connected; do not daisy-chain through the E07 module.

## Infrared transmit and receive

Official references:

- [TSOP753..W receiver data sheet](https://www.vishay.com/docs/82497/tsop753w.pdf)
- [TSAL6200 emitter data sheet](https://www.vishay.com/docs/81010/tsal6200.pdf)

### U13 TSOP75338WTR receiver

| Pin | Function | Connection |
|---:|---|---|
| 1, 4 | GND | GND |
| 2 | VS | `+3V3` through 100 Ohm; 100 nF + 4.7 uF at receiver |
| 3 | OUT | `IR_RX` / GPIO37; optional DNP 10 kOhm pull-up to +3V3 |

The official W package is 6.8 mm wide, 3.0 mm high, and 2.35 mm deep. Put its
optical face at the PCB edge. Keep the +/-75 degree field of view clear and
shield it optically from D1 with enclosure plastic, an opaque divider, or
placement on a different edge. Supply filtering and physical separation from
the boost converter are more important than a short GPIO trace.

### D1 TSAL6200 transmitter

Use the 5 mm THT emitter at the edge so the difficult SMT parts remain factory
assembled and the user can hand-fit/bend the LED after bring-up:

`+5V_RAW -> 39 Ohm / 1 W (2512) -> TSAL6200 anode; cathode -> AO3400A drain;
AO3400A source -> GND; gate <- GPIO36 through 100 Ohm; 100 kOhm gate pulldown`.

The 39 Ohm default limits the worst-case current to about 100 mA at a high 5 V
rail and low LED forward voltage. This is already a strong narrow-beam remote
signal; Vishay specifies 16 m typical receiver range with only 50 mA in its
TSOP test circuit. A lower resistor is a controlled prototype option only
after checking the emitter pulse-current derating graph, actual protocol burst
length, resistor pulse rating, and optical safety.

One TSAL6200 must **never** be driven at the old 800 mA project-budget value.
Its 200 mA rating applies only to short, low-duty pulses under the data-sheet
condition, not arbitrary IR protocol bursts. Firmware must keep the 5 V boost
off by default, enforce burst/envelope duty limits, prevent a stuck-on output,
and block simultaneous unrestricted 5 V header load. Perform an IEC 62471
optical safety review and do not view the emitter directly at close range.

SW3, SW7 and SW4 are the adjacent `UP`, `OK` and `DOWN` navigation controls.
All three use the same C&K KMR221GLFS footprint as the RESET/BOOT service
buttons. R608, R607 and R609 provide the respective 10-kohm pull-ups. SELECT
uses U9/P07; it does not share the dedicated PAIR security input.

SW8 is a compact C&K KXT311LHS AUX input on ESP32-S3 GPIO21. It is active low
to GND and deliberately has no external pull-up; firmware must enable GPIO21's
internal pull-up before using it. Its action is intentionally left configurable.

## U9/U18 I/O expanders

Official references: [TI TCA9535 data sheet](https://www.ti.com/lit/ds/symlink/tca9535.pdf)
and [TI TCA9534 data sheet](https://www.ti.com/lit/ds/symlink/tca9534.pdf).

The design separates monitoring/expansion from internal control. Both devices
share `IOEXP_INT_N` and the I2C bus. R703 is the 10-kohm interrupt pull-up, and
R701/R702 are the only board-wide 3.3-kohm SDA/SCL pull-ups. Neither expander
has internal GPIO pull resistors; all ports power up as inputs.

U9 is a TCA9535PWR at 7-bit address `0x20` (A0/A1/A2 low):

| Port | Connection |
|---|---|
| P00 | `SD_DETECT_N` |
| P01 | `CHARGER_CHG_N` |
| P02 | `CHARGER_PGOOD_N` |
| P03 | `AUX5_FAULT_N` |
| P04 | `FG_ALERT_N` |
| P05 | `BMI_INT1` |
| P06 | `BMI_INT2` |
| P07 | `USER_BUTTON_SELECT_N`, active-low OK/SELECT input |
| P10-P17 | `EX0_INT`-`EX7_INT`; R722-R729 220 ohm to J5 EX0-EX7 |

U18 is a TCA9534PWR at 7-bit address `0x21` (A0 high, A1/A2 low):

| Port | Connection / role |
|---|---|
| P0 | `BQ_EN1`, charger input-mode control |
| P1 | `CHG_DISABLE`, active-high charge disable |
| P2 | `AUX5_EN`, protected header-output enable |
| P3 | `NFC_RESET_N` |
| P4 | `LF_RFID_EN` |
| P5 | `BOOST5_EN` |
| P6 | `USER_BUTTON_A_N`, active-low UP input |
| P7 | `USER_BUTTON_B_N`, active-low DOWN input |

External pull resistors hold charger, LF RFID, NFC and 5-V controls in their safe
states until firmware has discovered and configured U18. Firmware must never
assume the expanders retained their direction/output registers across a reset.

## Optional motion and pressure sensors

### U10 BMI270

Official reference: [Bosch BMI270 data sheet](https://www.bosch-sensortec.com/media/boschsensortec/downloads/datasheets/bst-bmi270-ds000.pdf)

| Pin | Name | I2C configuration |
|---:|---|---|
| 1 | SDO/SA0 | GND for address 0x68; +3V3 would select 0x69 |
| 2 | ASDX | NC (VDDIO also allowed; never GND) |
| 3 | ASCX | NC (VDDIO also allowed; never GND) |
| 4 | INT1 | `BMI_INT1` to U9/P05 |
| 5 | VDDIO | +3V3, 100 nF at pin |
| 6 | GNDIO | GND |
| 7 | GND | GND |
| 8 | VDD | +3V3, 100 nF at pin |
| 9 | INT2 | `BMI_INT2` to U9/P06 |
| 10 | OCSB | NC |
| 11 | OSDO | NC |
| 12 | CSB | +3V3 directly or through 0 Ohm |
| 13 | SCX | `I2C_SCL` |
| 14 | SDX | `I2C_SDA` |

Place the IMU in a mechanically quiet region near the card center, away from
mounting holes, edge connectors, switch openings, and board-flex hotspots. Add a
clear X/Y axis marker to silkscreen. It is factory-assembled only.

### U11 BMP390

Official reference: [Bosch BMP390 data sheet](https://www.bosch-sensortec.com/media/boschsensortec/downloads/datasheets/bst-bmp390-ds002.pdf)

| Pin | Name | I2C configuration |
|---:|---|---|
| 1 | VDDIO | +3V3, 100 nF at pin |
| 2 | SCK | `I2C_SCL` |
| 3, 8, 9 | VSS | GND |
| 4 | SDI | `I2C_SDA` |
| 5 | SDO/SA0 | GND for address 0x76; +3V3 selects 0x77; never float |
| 6 | CSB | +3V3/0 Ohm; optional 10 kOhm pull-up footprint |
| 7 | INT | NC; pressure is read by I2C polling so U9/P07 can serve SELECT |
| 10 | VDD | +3V3, 100 nF at pin |

Do not put copper, via holes, paste, adhesive, conformal coating, or cleaning
residue under the central pressure port. Keep it away from heat sources,
boost/buck inductors, direct airflow, switch openings, and flexible edges. The
enclosure needs a protected pressure vent and at least 0.1 mm lid clearance.
This LGA is factory-assembled only.

## U12 PCF8563 RTC

Official reference: [NXP PCF8563 data sheet](https://www.nxp.com/docs/en/data-sheet/PCF8563.pdf)

| Pin | Name | Connection |
|---:|---|---|
| 1, 2 | OSCI, OSCO | Y701 32.768 kHz, CL = 7 pF, Rs <= 100 kOhm |
| 3 | INT | NC/test pad; open-drain if later used |
| 4 | VSS | GND |
| 5, 6 | SDA, SCL | Shared I2C |
| 7 | CLKOUT | Test pad; open-drain, disabled by firmware when unused |
| 8 | VDD | `+3V3` or an explicitly defined always-on 3.3 V rail; 100 nF |

The 7-bit address is 0x51. Y701 is a non-polar 3215 two-pad crystal with CL = 7 pF
and preferably Rs below 70 kOhm. No two external load capacitors are required
because PCF8563 integrates its oscillator capacitor; retain only the data-sheet
Ctrim position (5 pF to 25 pF on OSCI) as DNP if calibration is planned. Keep
crystal traces extremely short, symmetric, and free of test pads; no fast
traces or copper pours directly below them. CLKOUT starts enabled at 32.768 kHz,
so firmware should disable it early when unused. If the RTC remains powered
while the ESP/I2C rail is off, pull SDA/SCL to the same always-on domain or add
isolation so the bus cannot back-power other devices.

## Project-local package footprints and exact geometry

All non-stock packages used by the schematic are in
`hardware/PocketLab_Custom.pretty` and are registered by `fp-lib-table`.
This includes BMP390, TSOP75338WTR, TPS63070, both power inductors, the E07
module and the NFC loop. These land patterns still require independent drawing,
pin-one and assembler-preview review before release.

BMP390 footprint geometry follows the Bosch bottom view/landing-pattern rule:

- Body 2.00 x 2.00 mm, typical height 0.75 mm.
- Side pads (3, 4, 5, 8, 9, 10): 0.275 x 0.250 mm at x = +/-0.7625 mm and
  y = -0.50, 0, +0.50 mm.
- Top/bottom pads (1, 2, 6, 7): 0.250 x 0.275 mm at x = +/-0.25 mm and
  y = +/-0.7625 mm.
- Coordinates in the supplied manufacturer-top-view orientation are:
  P1 `(0.25,-0.7625)`, P2 `(-0.25,-0.7625)`, P3..P5 on x `-0.7625`,
  P6 `(-0.25,0.7625)`, P7 `(0.25,0.7625)`, and P8..P10 on x `+0.7625`.
  Pin 1 is therefore in the top-right quadrant exactly as in the Bosch top
  view; rotate the complete footprint on the PCB rather than mirroring it.
- The central pressure port is marked on fabrication/user layers. No via or
  copper is allowed under the body except the ten land pads.

TSOP75338WTR footprint geometry follows Vishay's proposed component-side pad
layout:

- Body 6.8 x 2.35 mm, height 3.0 mm.
- Four pads 0.8 x 1.8 mm on 1.27 mm pitch (3 x 1.27 = 3.81 mm span).
- In the supplied footprint, body center is `(0,0)`, the optical face is the
  long edge at y `-1.175`, and rear lead-land centers are at y `+1.55` with
  x = `-1.905, -0.635, +0.635, +1.905` for pins 1 through 4.
- Optical-face direction, pin 1, and the edge-facing installation direction
  are explicitly marked.

The E07 custom footprint already present in `PocketLab_Custom.pretty` uses the
official 20 x 14 mm body, 1.27 mm pitch, and 0.8 x 1.8 mm castellated lands.
HTRC110 and ATECC608C deliberately use standard SOIC packages so both remain
inspectable and hand-reworkable after factory assembly.

AE1 uses `NFC_Loop_35x27mm_4T_TUNE`: 35 x 27 mm copper, four turns,
0.50/0.50 mm track/spacing, and a short plated B.Cu crossover. The footprint is
excluded from BOM/CPL and embeds the 36 x 29 mm all-layer keep-out. Its roughly
1.0-1.4 uH first-order estimate is only a placement aid, never a measured value.

## Prototype and release blockers

Before exporting an engineering-prototype Gerber/BOM/CPL set:

1. Independently review all project-local and stock footprints, pin-one
   orientation, polarity and JLC/LCSC component previews.
2. Finish physical placement and routing, preserving ESP32, NFC, LF RFID and
   Sub-GHz keep-outs and return paths; close DRC with no unexplained items.
3. Calculate 90-ohm USB and 50-ohm Sub-GHz geometry from the actually ordered
   stack-up; validate LF coil resonance, current, voltage and DNP tune sites.
4. Confirm microSD connector and U19 availability plus exact 104031-0811
   pad/detect orientation before BOM lock.
5. Verify the approximately 100-mA IR design and fitted 39-ohm/1-W part, enforce
   firmware duty limits and complete the optical-safety review.
6. Repeat ERC/DRC and perform schematic, footprint, polarity,
   antenna-clearance, both-side assembly and manufacturing-output peer review.

The first cards remain engineering prototypes. Before any volume release,
measure loop inductance/Q and tune the complete NFC match on the assembled card
with a VNA or NFC fixture. Also verify LF resonance/range, Sub-GHz radiated
behavior, power/thermal margins and applicable RF/regulatory limits using the
actual antennas, enclosure and battery.

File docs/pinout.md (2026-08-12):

# ESP32-S3 pin allocation

This is the schematic-capture baseline. Changes must be reflected here and in
`firmware/include/board_pins.h`.

## Dedicated and reserved pins

| GPIO | Net / function | Direction | Notes |
|---:|---|---|---|
| 0 | BOOT_N | Input | Boot strap and physical boot button; not on expansion header |
| 3 | JTAG_STRAP_TP | Reserved | Test pad only; boot/JTAG strap |
| 5 | I2C_SDA | Bidirectional | Shared system I2C and expansion header |
| 6 | I2C_SCL | Bidirectional | Shared system I2C and expansion header |
| 7 | NFC_IRQ_N | Input | PN532 interrupt |
| 9 | BOARD_TEMP_ADC | Analog input | Internal R736/RT701 divider; J5 pin 7 is probe-only |
| 10 | RGB_DATA | Output | Four chained addressable LEDs |
| 11 | SPI_MOSI | Output | CC1101, microSD and expansion header |
| 12 | SPI_SCK | Output | CC1101, microSD and expansion header |
| 13 | SPI_MISO | Input | CC1101, microSD and expansion header |
| 14 | SUBGHZ_CS_N | Output | CC1101 chip select |
| 15 | SUBGHZ_GDO0 | Bidirectional | CC1101 packet/timing signal |
| 16 | SUBGHZ_GDO2 | Bidirectional | CC1101 carrier/timing signal |
| 17 | SD_CS_N | Output | microSD chip select |
| 18 | LF_SCLK_3V3 | Output | HTRC110 serial clock through AHCT level shifter |
| 19 | USB_D_N | USB | Native USB; never use as expansion GPIO |
| 20 | USB_D_P | USB | Native USB; never use as expansion GPIO |
| 21 | LF_DOUT_3V3 | Input | HTRC110 data output through 5-V-tolerant LVC buffer |
| 35 | LF_DIN_3V3 | Output | HTRC110 serial/data input through AHCT level shifter |
| 36 | IR_TX | Output | RMT carrier to IR MOSFET driver |
| 37 | IR_RX | Input | Demodulated IR receiver output |
| 38 | PAIR_N | Input | Dedicated active-low physical app-pairing button; not exposed on J5 |
| 39 | IOEXP_INT_N | Input | Shared U9/U18 open-drain interrupt |
| 45 | STRAP_VDD_SPI | Reserved | Test pad only; boot strap |
| 46 | STRAP_BOOT | Reserved | Test pad only; boot strap |

## Direct free GPIOs

Eleven free pins reach J5 through fixed 100-ohm series resistors. R714 is the
twelfth branch but carries the reserved GPIO9 board-temperature node to a
probe-only header pad. GPIO38 is reserved for the dedicated PAIR button through
R606. GPIO43/44 can be used
as a normal UART pair; native USB CDC is
the default debug console.

| GPIO | Useful hardware capability |
|---:|---|
| 1 | ADC1 channel 0, touch, digital, PWM |
| 2 | ADC1 channel 1, touch, digital, PWM |
| 4 | ADC1 channel 3, touch, digital, PWM |
| 8 | ADC1 channel 7, touch, digital, PWM |
| 40 | Digital, PWM, interrupt |
| 41 | Digital, PWM, interrupt |
| 42 | Digital, PWM, interrupt |
| 43 | Digital, PWM, UART TX candidate |
| 44 | Digital, PWM, UART RX candidate |
| 47 | Digital, PWM, interrupt |
| 48 | Digital, PWM, interrupt |

All direct GPIOs are 3.3 V only and are not 5 V tolerant. The series resistors
limit edge rate and fault current but do not add level shifting or full ESD/
overvoltage protection. U24/U25 protect the five exposed I2C/SPI header nets;
the direct GPIO and EX0-EX7 pins remain series-protected only.

## U9 TCA9535 status and expansion allocation

U9 uses address `0x20` (A0/A1/A2 low). Its first eight ports monitor on-board
status/interrupt signals. Its second eight ports feed EX0-EX7 through 220-ohm
resistors R722-R729. All ports power up as inputs and U9 has no internal GPIO
pull resistors.

| Expander pin | Function |
|---|---|
| P00 | `SD_DETECT_N` |
| P01 | `CHARGER_CHG_N` |
| P02 | `CHARGER_PGOOD_N` |
| P03 | `AUX5_FAULT_N` |
| P04 | `FG_ALERT_N` |
| P05 | `BMI_INT1` |
| P06 | `BMI_INT2` |
| P07 | `USER_BUTTON_SELECT_N` (OK/SELECT) |
| P10-P17 | `EX0_INT`-`EX7_INT`, then 220 ohm to EX0-EX7 on J5 |

## U18 TCA9534 internal control allocation

U18 uses address `0x21` (A0 high, A1/A2 low). Its interrupt output shares
`IOEXP_INT_N` with U9. Hardware pull resistors define safe states before the
firmware configures the ports.

| Expander pin | Function |
|---|---|
| P0 | `BQ_EN1` |
| P1 | `CHG_DISABLE` |
| P2 | `AUX5_EN` |
| P3 | `NFC_RESET_N` |
| P4 | `LF_RFID_EN` |
| P5 | `BOOST5_EN` |
| P6 | `USER_BUTTON_A_N` (UP) |
| P7 | `USER_BUTTON_B_N` (DOWN) |

EX0-EX7 are 3.3 V digital I/O intended for switches, enables and other
low-speed signals. They do not provide ADC, accurate PWM, RMT or high-speed
protocol timing.

## J5: 6 x 5, 2.54 mm Dupont matrix

Use 1.0 mm finished plated holes. The matrix ships unpopulated and accepts
individual Dupont leads or short breakaway strips. A monolithic 2 x 15 housing
does not fit. Pad numbering is row-major as viewed from the front:

| Physical row | Pads and nets from left to right |
|---:|---|
| 1 | 1 `+3V3`, 2 `GND`, 3 `GPIO1/ADC`, 4 `GPIO2/ADC`, 5 `GPIO4/ADC`, 6 `GPIO8/ADC` |
| 2 | 7 `BOARD_TEMP probe`, 8 `GPIO40`, 9 `GPIO41`, 10 `GPIO42`, 11 `GPIO43/UART TX`, 12 `GPIO44/UART RX` |
| 3 | 13 `GPIO47`, 14 `GPIO48`, 15 `EX0`, 16 `EX1`, 17 `EX2`, 18 `EX3` |
| 4 | 19 `EX4`, 20 `EX5`, 21 `EX6`, 22 `EX7`, 23 `I2C_SDA`, 24 `I2C_SCL` |
| 5 | 25 `SPI_SCK`, 26 `SPI_MOSI`, 27 `SPI_MISO`, 28 `CHG_TS`, 29 `+5V_AUX`, 30 `GND` |

Any direct free GPIO may be used as chip select for an external SPI device.
J5 pin 7 is not a free GPIO: it is connected through R714 to the internal NTC
divider and must only be measured with a high-impedance 3.3-V-safe input.
External I2C and SPI wiring shares the buses with onboard devices. R730/R731
add 100 ohm in series to the exposed I2C header pair, and R732-R734 do the same
for SPI SCK/MOSI/MISO. U24 and U25 add 3.3-V-referenced shunt ESD protection on
the connector side of those five resistors. The single board-wide I2C pull-up
pair is 3.3 kohm.
For an external 10-kohm battery NTC, cut SJ1 and connect the NTC between J5
pins 28 and 30. Do not connect a raw cell directly to pin 28.

## Connector labeling

Silkscreen must clearly distinguish:

- `LF COIL` beside J3 and `868 ANT` beside the spring pad
- `BAT +` and `BAT -` with explicit battery polarity
- `3V3 ONLY` beside direct GPIOs
- `5V AUX 500mA MAX` beside J5 pin 29
- `PAIR` beside SW6

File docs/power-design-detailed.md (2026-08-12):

# Detaillierter Entwurf: USB-C, Akku und Stromversorgung

Stand: 2026-08-09. Dieses Dokument erklärt Auslegung und Prüfkriterien für den
Power-Block. Für Referenzbezeichner, Netznamen und tatsächlich bestückte
Optionen ist der aktuell erzeugte KiCad-Schaltplan maßgeblich. Es ist noch
**kein Freigabenachweis für ein Serienprodukt**. LiPo-Sicherheit, thermische
Grenzen, USB-Konformität und alle Stromgrenzen müssen am ersten Prototyp
verifiziert werden.

## 1. Festgelegte Architektur

```text
USB-C VBUS
  -> F1 1206L075/13.2
  -> VBUS_FUSED (TVS + 4.7 uF)
  -> BQ24074 IN

2-pin 1S LiPo
  CELL_POS -------------------------> BQ24074 BAT
  CELL_NEG -> BQ29700 + 2x MOSFET --> GND/PACK_NEG

BQ24074 OUT = VSYS (normal ca. 2.9 ... 4.5 V; nahe Akku-Cutoff ggf. tiefer)
  -> TPS63070 -> +3V3
  -> TPS61023 -> +5V_RAW
                    -> IR-Stufe
                    -> TPS2553 -> +5V_AUX

MAX17048 misst CELL_POS gegen System-GND.
```

Die Netzbezeichnungen sind absichtlich eindeutig:

| Netz | Bedeutung |
|---|---|
| `VBUS_USB` | USB-VBUS direkt am Stecker, vor F1 |
| `VBUS_FUSED` | Geschützter USB-Eingang nach F1 |
| `CELL_POS` | Akku-Plus und BQ24074-BAT |
| `CELL_NEG` | Akku-Minus vor den Schutz-MOSFETs; kein System-GND |
| `BAT_FET_MID` | Gemeinsame Drains der Schutz-MOSFETs |
| `GND` | `PACK_NEG`, Systemmasse nach den Schutz-MOSFETs |
| `VSYS` | BQ24074-OUT, Eingang der beiden DC/DC-Wandler |
| `+3V3` | Dauerhafte digitale 3,3-V-Schiene |
| `+5V_RAW` | Schaltbare 5-V-Schiene direkt vom TPS61023 |
| `+5V_AUX` | Separat strombegrenzte 5-V-Schiene am Header |

Die beiden Wandler-Nennwerte dürfen nicht gleichzeitig als Dauerlast
ausgenutzt werden. Schon `3.3 V * 1.5 A + 5 V * 1.0 A = 9.95 W` Ausgangsleistung
erfordern bei je 90 % Wirkungsgrad rund 11.1 W beziehungsweise 3.35 A aus
einem auf 3.3 V abgesunkenen Akku. Das überschreitet das 2-A-Dauerziel und
das 3-A-Pulsziel. Firmware muss IR, Header, NFC, RGB und Funklasten weiterhin
gegeneinander verriegeln. Bei USB500 ohne Akku stehen insgesamt höchstens
etwa 2.5 W vor Verlusten zur Verfügung; hohe Lasten benötigen den Akku als
Puffer.

## 2. USB-C-Sink und USB 2.0

### 2.1 Stecker J1

Bauteil: HRO `TYPE-C-31-M-12`, KiCad-Footprint
`Connector_USB:USB_C_Receptacle_HRO_TYPE-C-31-M-12`.

| Kontakt(e) | Netz / Beschaltung |
|---|---|
| A4, A9, B4, B9 | gemeinsam `VBUS_USB` |
| A1, A12, B1, B12 | `GND` |
| A6, B6 | gemeinsam `USB_CONN_P` |
| A7, B7 | gemeinsam `USB_CONN_N` |
| A5 / CC1 | `USB_CC1`; eigener 5.1-kOhm-Widerstand nach GND |
| B5 / CC2 | `USB_CC2`; eigener 5.1-kOhm-Widerstand nach GND |
| A8 / SBU1, B8 / SBU2 | unbeschaltet |
| Shield-Pads | gemeinsam `USB_SHIELD`; R103 1 MOhm und C101 4.7 nF parallel nach GND |

CC1 und CC2 dürfen **nicht** miteinander verbunden werden. Je ein
`5.1 kOhm, 1 %, 0805` nach GND kennzeichnet das Board als reinen 5-V-Sink.
Es gibt kein USB-PD und ohne CC-Controller auch keine Auswertung einer
1.5-A-/3-A-Ankündigung. Die Schaltung bleibt deshalb bei höchstens USB-500.

Der Steckerschirm ist in diesem Prototyp nicht direkt mit System-GND
kurzgeschlossen. Seine Pads bilden eine kurze, zusammenhängende
`USB_SHIELD`-Kupferinsel; R103/C101 koppeln diese Insel DC-/HF-definiert an
GND. Ob für das reale Gehäuse und die EMV-Prüfung stattdessen eine direkte
Verbindung erforderlich ist, muss gemessen und dann als eigene Revision
festgelegt werden.

### 2.2 VBUS-Schutz

| Ref | Wert / Teil | Footprint | Verbindung |
|---|---|---|---|
| F1 | Littelfuse `1206L075/13.2`, 0.75 A hold, 1.5 A trip | `Fuse:Fuse_1206_3216Metric` | `VBUS_USB` -> `VBUS_FUSED` |
| D101 | Littelfuse `SMF5.0A`, unidirektional | `Diode_SMD:D_SOD-123F` | Kathode `VBUS_FUSED`, Anode GND |
| C103 | 4.7 uF, 16 V, X7R, 0805 | 0805 | `VBUS_FUSED` nach GND; zugleich U5-IN-Bypass |
| C106 | 100 nF, 16 V, X7R, 0805 | 0805 | `VBUS_FUSED` nach GND; zugleich U5-IN-Bypass |

Der 1206L075 hat bei 20 Grad C 0.75 A Haltestrom, 1.5 A Auslösestrom und
bis zu 0.35 Ohm nach Auslösung/Rückstellung laut Herstellerdaten. Bei hoher
Umgebungstemperatur ist der Haltestrom reduziert; F1 daher nicht direkt neben
dem Lade-IC platzieren. Die gesamte direkt an VBUS sichtbare Kapazität bleibt
mit 4.8 uF nominal unter 10 uF. Diese Kondensatoren dürfen an U5 nicht ein
zweites Mal bestückt werden. Die große Systemkapazität liegt hinter dem
strombegrenzenden BQ24074-Power-Path.

### 2.3 ESD und Datenleitungen

U16: ST `USBLC6-4SC6Y`, SOT-23-6L / JEDEC MO-178AB,
KiCad `Package_TO_SOT_SMD:SOT-23-6`.

| Pin | Funktion | Netz |
|---:|---|---|
| 1 | I/O1 | `USB_CONN_P` |
| 2 | GND | GND |
| 3 | I/O2 | `USB_CONN_N` |
| 4 | I/O3 | `USB_CC1` |
| 5 | VBUS | `VBUS_FUSED` |
| 6 | I/O4 | `USB_CC2` |

Das ESD-Array ist eine Abzweigklemme, kein serielles Durchgangsbauteil. Es
muss direkt hinter dem Stecker mit extrem kurzen Leitungen nach GND und
`VBUS_FUSED` sitzen. Danach folgen je `22 Ohm, 1 %, 0805` seriell in D+ und D-
zu `USB_D_P` beziehungsweise `USB_D_N` am ESP32-S3. D+ und D- werden als
90-Ohm-Differenzpaar mit durchgehender Referenzfläche, gleicher Via-Anzahl und
ohne bestückte Shunt-Kondensatoren geführt.

## 3. BQ24074 Ladegerät und Power-Path

U5: Texas Instruments `BQ24074RGTR`, RGT0016B, VQFN-16 mit Exposed Pad,
3.0 x 3.0 mm, 0.5-mm-Pitch. Verifizierter KiCad-10-Footprint:
`Package_DFN_QFN:VQFN-16-1EP_3x3mm_P0.5mm_EP1.6x1.6mm_ThermalVias`.
Das Exposed Pad ist in KiCad Pad 17 und muss an GND liegen.

### 3.1 Pin-zu-Netz-Tabelle

| Pin | Name | Netz / Bauteil |
|---:|---|---|
| 1 | TS | `CHG_TS`; 10.0 kOhm nach GND oder externer 10-k-NTC |
| 2, 3 | BAT | `CELL_POS`; 22 uF + 100 nF nach GND |
| 4 | CE | `CHG_DISABLE`; 100 kOhm Pulldown nach GND; High sperrt Laden |
| 5 | EN2 | `BQ_EN2`; 100 kOhm Pulldown nach GND |
| 6 | EN1 | `BQ_EN1`; 100 kOhm Pulldown nach GND, MCU darf auf High schalten |
| 7 | PGOOD | `CHARGER_PGOOD_N`; 100 kOhm Pull-up nach +3V3 |
| 8 | VSS | GND |
| 9 | CHG | `CHARGER_CHG_N`; 100 kOhm Pull-up nach +3V3 |
| 10, 11 | OUT | `VSYS`; 4.7 uF + 100 nF unmittelbar nach GND |
| 12 | ILIM | 3.48 kOhm, 1 %, nach GND |
| 13 | IN | `VBUS_FUSED`; gemeinsamer C103 4.7 uF + C106 100 nF nach GND |
| 14 | TMR | 68.1 kOhm, 1 %, nach GND |
| 15 | ITERM | 3.01 kOhm, 1 %, nach GND |
| 16 | ISET | 1.78 kOhm, 1 %, nach GND |
| EP / 17 | Thermal pad | GND mit Thermal-Vias |

`PGOOD` und `CHG` sind Open-Drain-Ausgänge. Die 100-kOhm-Pull-ups sparen
Ruhestrom; falls lange Leitungen oder hohe Störlast Probleme machen, dürfen
sie ohne Schaltungsänderung auf 47 kOhm reduziert werden.

Die BQ24074-Empfehlung für die gesamte an OUT sichtbare Keramikkapazität ist
4.7 bis 47 uF. Daher werden direkt an U5 nur 4.7 uF bestückt. Am
TPS63070-Eingang werden standardmäßig nur `C108` und `C123` mit je
10 uF bestückt; `C109` bleibt DNP. Zusammen mit 10 uF am
TPS61023-Eingang entstehen damit etwa 34.7 uF nominal auf `VSYS`. Das gibt
Reserve für positive Bauteiltoleranzen und weitere unvermeidbare
Abblockkondensatoren. `C109` darf erst nach einem Stabilitäts- und
Lastsprungtest bestückt werden; dann liegen 44.7 uF nominal an `VSYS` und die
47-uF-Grenze muss einschließlich Toleranzen erneut bewertet werden.

### 3.2 Einstellwerte und Rechnungen

Ladestrom, typischer TI-Faktor `K_ISET = 890 A*Ohm`:

```text
I_CHG = K_ISET / R_ISET
      = 890 / 1780
      = 0.500 A typisch
```

Der Datenblattfaktor streut von 797 bis 975 A*Ohm. Der USB-Eingangslimiter
begrenzt den realen Ladestrom zusätzlich; 500 mA ist trotzdem nur für Zellen
zulässig, deren Hersteller mindestens diesen Ladestrom erlaubt.

Terminierungsstrom im USB500- oder ISET-Modus:

```text
I_TERM = K_ITERM * R_ITERM / R_ISET
       = 0.030 A * 3010 / 1780
       = 50.7 mA typisch
```

Safety Timer:

```text
t_MAXCHG = 10 * R_TMR * K_TMR
         = 10 * 68.1 kOhm * 48 s/kOhm
         = 32,688 s = 9.08 h typisch
```

Der Timer kann wegen `K_TMR = 36 ... 60 s/kOhm` etwa 6.81 bis 11.35 h
betragen. Die Vorladedauer ist ein Zehntel davon, typisch rund 54.5 min.
Diese längere Einstellung ist bewusst gewählt: Ein 2000-mAh-Pack benötigt
bei 500 mA bereits mindestens vier Stunden Konstantstrom plus CV-Taper; ein
6-h-Timer könnte am unteren Toleranzrand zu früh auslösen.

Der programmierbare ILIM-Ersatzmodus wird konservativ dimensioniert:

```text
R_ILIM = 3.48 kOhm, 1 %
I_LIM_typ = 1525 / 3480 = 438 mA
I_LIM_max = 1720 / (3480 * 0.99) = 499 mA
```

Damit überschreitet auch der optionale Widerstandsmodus rechnerisch 500 mA
nicht. Im normalen USB-Betrieb bestimmt jedoch EN1/EN2 den Eingangsstrom.

### 3.3 Verbindliche EN-Logik

| EN2 | EN1 | Zustand |
|---:|---:|---|
| 0 | 0 | USB100; Default nach Reset |
| 0 | 1 | USB500; erst nach erfolgreicher USB-Enumeration |
| 1 | 0 | Widerstandsmodus, hier max. ca. 499 mA |
| 1 | 1 | Standby |

Produktionsdefault ist `EN2=0`, `EN1=0`. Die aktuelle sichere Firmware lässt
EN1 dauerhaft Low und bleibt damit im USB100-Modus; eine spätere Umschaltung
auf USB500 ist nur nach einer verlässlichen Erkennung der zulässigen
Quellenstromstärke erlaubt. Im 100-mA-Startzustand müssen PN532, 5-V-Boost,
LF-RFID-Versorgung, RGB-LEDs und externe Lasten sicher ausgeschaltet
bleiben. Falls der ESP32 unter 100 mA nicht zuverlässig startet, ist für den
Prototyp ein Akku erforderlich.

### 3.4 Akku-Temperatur

Der gewählte 2-polige JST-Stecker hat keinen Temperaturkontakt. Daher:

- R108 (`10 kOhm TS fixed`, 0805) und den gebrückten Lötjumper SJ1
  standardmäßig bestücken.
- J5 stellt an Pin 28 `CHG_TS` und an Pin 30 GND im 2.54-mm-Raster für einen
  optionalen externen NTC bereit.
- Bei Verwendung eines echten 10-kOhm-NTC SJ1 auftrennen. Dadurch wird R108
  von `CHG_TS` getrennt; R108 muss nicht ausgelötet werden.

Ein Festwiderstand hält TS elektrisch im gültigen Bereich, misst aber **keine
Zellentemperatur**. Für ein endgültiges Produkt ist ein Akku mit drittem
NTC-Kontakt die bevorzugte Lösung. Nur Standard-LiPo/Li-Ion mit 4.20-V-
Ladeschlussspannung verwenden, keine 4.35-V-LiHV-Zelle.

#### 3.4.1 Interne Platinentemperatur

R736 (10 kOhm, 1 %) liegt von +3V3 nach `BOARD_TEMP_ADC`; RT701 (10-kOhm-NTC,
B3950) liegt vom Messknoten nach GND. GPIO9/ADC1_CH8 misst dadurch bei 25 Grad C
ungefähr 1.65 V. Der NTC sitzt auf der Rückseite neben der 5-V-Leistungszone und
ist ein Schutz-/Diagnosewert, kein Ersatz für einen NTC direkt an der Zelle.
J5 Pin 7 erreicht denselben Knoten nur über R714 und darf ausschließlich
hochohmig gemessen werden.

Die Bring-up-Firmware mittelt 16 ADC-Messungen. Ab 80 Grad C sperrt sie neue
IR/LF/Boost-Anforderungen und schaltet Ladefreigabe sowie vorhandene 5-V-Lasten
ab. Unter 70 Grad C wird nur die Ladefreigabe automatisch zurückgenommen; die
Lasten bleiben aus, bis die App sie erneut einschaltet. Diese Schwellen müssen
am bestückten Prototyp gegen eine externe Temperaturmessung kalibriert werden.
Ein offener oder kurzgeschlossener Teiler wird ausfallsicher wie Übertemperatur
behandelt.

### 3.5 Verlustleistung

Ungünstiger linearer Ladefall bei 5 V Eingang, etwa 3 V Akku und 0.5 A:

```text
P_U5 ~= (5.0 - 3.0) * 0.5 = 1.0 W
Delta_T ~= 1.0 W * 44.5 K/W = 44.5 K
```

Das ist nur eine JEDEC-Abschätzung. Der BQ24074 beginnt typischerweise bei
125 Grad C Sperrschichttemperatur thermisch zurückzuregeln. EP, Ground-Pour
und Vias sind deshalb funktional nötig. Im Prototyp Ladestrom und Temperatur
bei leerem Akku und gleichzeitigem Systembetrieb messen.

## 4. 1S-LiPo-Schutz

Dieser Schutz ergänzt einen geschützten Akku, ersetzt aber keine geprüfte
Schutzschaltung im Pack. Er schützt nicht gegen einen verpolten Akkustecker.
Die Kabelpolarität muss vor dem ersten Einstecken geprüft und auf dem
Silkscreen groß markiert werden.

### 4.1 Stecker

J4: JST `S2B-PH-SM4-TB`, PH-Serie, 2.0-mm-Raster, Side-Entry. Pin 1 wird
im Projekt als `CELL_POS`, Pin 2 als `CELL_NEG` festgelegt. Das ist eine
Boarddefinition; fertig konfektionierte JST-Akkukabel haben keine universell
garantierte Polarität.

J4 wird auf der Rückseite bestückt und gegenüber der früheren Vorderansicht um
90 Grad nach links gedreht. Der Kabelabgang sowie `BAT +`/`BAT -` müssen in der
Unterseitenansicht des Bestückers geprüft werden.

### 4.2 Schutz-IC U14

U14: TI `BQ29700DSER`, DSE WSON-6, 1.5 x 1.5 x 0.75 mm, 0.5-mm-Pitch.
KiCad: `Package_SON:WSON-6_1.5x1.5mm_P0.5mm`. JLCPCB-Bestückung zwingend.

| Pin | Name | Netz / Beschaltung |
|---:|---|---|
| 1 | NC | wirklich unverbunden |
| 2 | COUT | Gate Q3; zusätzlich R107 5.1 MOhm Gate-Source |
| 3 | DOUT | Gate Q2; zusätzlich R106 5.1 MOhm Gate-Source |
| 4 | VSS | `CELL_NEG` |
| 5 | BAT | über 330 Ohm von `CELL_POS`; 100 nF von Pin 5 nach `CELL_NEG` |
| 6 | V- | über 2.2 kOhm von GND / `PACK_NEG` |

Fest programmierte Schwellen des BQ29700:

| Schutz | Schwelle | Verzögerung |
|---|---:|---:|
| Überspannung | 4.275 V | 1.25 s |
| Unterspannung | 2.800 V | 144 ms |
| Lade-Überstrom | -100 mV | 8 ms |
| Entlade-Überstrom | +100 mV | 20 ms |
| Kurzschluss | +500 mV | 250 us |

### 4.3 Schutz-MOSFETs

Q2 und Q3: je TI `CSD16406Q3`, DQG / VSON-CLIP,
3.3 x 3.3 mm, 0.65-mm-Pitch. KiCad:
`Package_SON:VSON-8_3.3x3.3mm_P0.65mm_NexFET`.

Physische Anschlüsse laut TI:

| Physischer Pin | Funktion |
|---:|---|
| 1, 2, 3 | Source |
| 4 | Gate |
| 5, 6, 7, 8 | Drain |

Der KiCad-Footprint fasst die physische Drainfläche 5 bis 8 absichtlich als
einen großen Pad mit Nummer 5 zusammen. Symbol und Footprint müssen deshalb
gezielt aufeinander geprüft werden; ein generisches SO-8-MOSFET-Footprint ist
falsch.

Back-to-back, Common-Drain:

| FET | Source | Drain | Gate | Gate-Source-Widerstand |
|---|---|---|---|---|
| Q2 (discharge) | `CELL_NEG` | `BAT_FET_MID` | U14 DOUT | R106 5.1 MOhm nach `CELL_NEG` |
| Q3 (charge) | GND / `PACK_NEG` | `BAT_FET_MID` | U14 COUT | R107 5.1 MOhm nach GND |

Das maximale RDS(on) eines FETs beträgt laut TI 7.4 mOhm bei VGS=4.5 V.
Nur als grobe Raumtemperatur-Abschätzung:

```text
R_pair,max ~= 2 * 7.4 mOhm = 14.8 mOhm
P_pair at 2 A ~= 2^2 * 14.8 mOhm = 59 mW
I_OCD,approx ~= 100 mV / 14.8 mOhm = 6.8 A
```

Bei niedrigem Zellpegel und hoher Temperatur steigt RDS(on) deutlich. Der
Schutz ist damit ein Fehler-/Kurzschlussschutz und **keine präzise 2-A-
Strombegrenzung**. 2 A dauerhaft und 3 A kurz müssen mit realem Pack,
Leiterbahnen, Steckverbinder und Temperatur geprüft werden. Der JST-PH-
Stecker ist mit 2 A der offensichtliche Dauerstrom-Flaschenhals. Insbesondere
kann ein längerer Fehlerstrom von etwa 3 bis 5 A unterhalb der BQ29700-
Auslöseschwelle liegen und den Stecker trotzdem überlasten. Falls nicht
bereits der gewählte Akku-Pack nachweislich in diesem Bereich abschaltet,
muss vor Serienfreigabe eine zusätzliche Sicherung oder passend ausgelegte
Hardware-Strombegrenzung in den Akkupfad aufgenommen werden.

Testpunkte TP101 (`CELL_POS`), TP102 (`CELL_NEG`), TP103 (`BAT_FET_MID`) und
TP104 (`GND`) sind
zwingend. `CELL_NEG` darf nicht auf normalen Erweiterungssteckern erscheinen,
weil das die Schutz-FETs umgehen würde. Nach Schutzabschaltung kann zum
Aufwecken das Anlegen des Ladegeräts erforderlich sein.

## 5. MAX17048 Fuel Gauge

U8: Analog Devices / Maxim `MAX17048G+T10`, TDFN-8-EP, 2.0 x 2.0 mm,
0.5-mm-Pitch. KiCad:
`Package_DFN_QFN:TDFN-8-1EP_2x2mm_P0.5mm_EP0.8x1.2mm`; EP ist Pad 9.

| Pin | Name | Netz / Beschaltung |
|---:|---|---|
| 1 | CTG | GND |
| 2 | CELL | NC; beim MAX17048 intern nicht verbunden |
| 3 | VDD | `CELL_POS`; 100 nF direkt nach GND |
| 4 | GND | GND |
| 5 | ALRT | `FG_ALERT_N`; 10 kOhm Pull-up nach +3V3 |
| 6 | QSTRT | GND, weil Hardware-Quickstart unbenutzt |
| 7 | SCL | `I2C_SCL` |
| 8 | SDA | `I2C_SDA` |
| EP / 9 | EP | GND |

Die zentralen I2C-Pull-ups R701/R702 sind einmalig `3.3 kOhm` nach +3V3. Keine zweiten
Pull-ups auf diesem Blatt bestücken. Adresse: `0x36` (7 Bit), Bus bis 400 kHz.

Die Masse des Gauge liegt auf der Systemseite der Schutz-FETs. Dadurch
überbrückt U8 die Schutzschaltung nicht; bei geöffneten FETs verliert der
Gauge seinen Rückleiter. Typische Stromaufnahme: 23 uA aktiv, 3 uA Hibernate.
Für gute SOC-Genauigkeit muss die Firmware RCOMP mit einer gemessenen
Temperatur korrigieren; ohne Akku-NTC ist die Boardtemperatur nur ein Ersatz.

## 6. +3V3 mit TPS63070

U6: TI `TPS63070RNMR`, RNM0015A, VQFN-HR-15, nominal 3.0 x 2.5 mm,
maximal 1.0 mm hoch. Das Gehäuse besitzt ein asymmetrisches Power-Landpattern.
Es darf **kein generisches QFN** verwendet werden. Projekt-Footprint:
`PocketLab_Custom:TPS63070_RNM0015A`.

### 6.1 Pin-zu-Netz-Tabelle

| Pin | Name | Netz / Beschaltung |
|---:|---|---|
| 1 | PS/SYNC | gemeinsam mit EN hinter 10 kOhm nach `VSYS`; Power-Save/PFM aktiv |
| 2 | PG | `PWR_3V3_PG`; 10 kOhm Pull-up nach +3V3 |
| 3 | VAUX | nur 100 nF nach GND; keine externe Last |
| 4 | GND | ruhige Signalmasse |
| 5 | FB | Mittelpunkt 470 kOhm / 150 kOhm |
| 6 | FB2 | offen; laut TI alternativ GND zulässig |
| 7, 8 | VOUT | `+3V3` |
| 9 | L2 | L6 Anschluss 2 |
| 10 | PGND | Leistungsmassenfläche |
| 11 | L1 | L6 Anschluss 1 |
| 12, 13 | VIN | `VSYS` |
| 14 | EN | gemeinsam mit PS/SYNC auf `U6_PS_SYNC`, hinter R116 10 kOhm nach `VSYS` |
| 15 | VSEL | GND |

Feedback:

```text
V_OUT = 0.8 * (1 + 470k / 150k)
      = 3.3067 V
```

Das ist zugleich die von TI angegebene Standardkombination für 3.3 V.

### 6.2 Leistungsteile

| Ref | Hersteller / Teil | Wert / Eckdaten | Package |
|---|---|---|---|
| L6 | Coilcraft `XFL4020-152MEC` | 1.5 uH, Isat 4.6 A bei 30 % Abfall, DCR typ. 14.4 mOhm | 4.0 x 4.0 x 2.1 mm |
| C108 | Murata `GRM21BC71E106ME11L` | 10 uF, 25 V, X7S | 0805 |
| C109 | Murata `GRM21BC71E106ME11L` | 10 uF, 25 V, X7S; **DNP ab Werk** | 0805 |
| C123 | Taiyo Yuden `TMK107BBJ106MA-T` | 10 uF, 25 V, X5R; direkt an VIN/PGND | 0603 |
| C110/C111/C112 | Murata `GRM21BC81C226ME44L` | je 22 uF, 16 V, X6S | 0805 |
| C124 | Taiyo Yuden `TMK107BBJ106MA-T` | 10 uF, 25 V, X5R; direkt an VOUT/PGND | 0603 |
| C107 | beliebig qualifiziert | 100 nF, X7R | 0805 |
| R117 | 470 kOhm, 1 % | +3V3 nach FB | 0805 |
| R118 | 150 kOhm, 1 % | FB nach GND | 0805 |

Die Kondensator-MPNs sind aus der TI-Typapplikation. Die beiden 0603-Bypässe
gehören direkt an die IC-Pins und reduzieren die Schaltspitzen. Alternativen sind nur
nach Prüfung der **effektiven** Kapazität bei DC-Bias zulässig. Für den
einstellbaren TPS63070 fordert TI `COUT_eff [uF] >= 10 * L_eff [uH]`; bei
1.5 uH sind das mindestens 15 uF effektiv. Die 3 x 22 uF plus 10 uF nominal
geben Reserve für Bias, Toleranz und schnelle ESP32-Lastsprünge.

Konservative Boost-Abschätzung bei `VIN=3.0 V`, `VOUT=3.3 V`, `IOUT=2 A`,
`eta=90 %`, `f=2.4 MHz`, `L=1.5 uH`:

```text
I_IN,avg = 3.3 * 2 / (3.0 * 0.90) = 2.44 A
D ~= 1 - (3.0 * 0.90 / 3.3) = 0.182
Delta_I ~= VIN * D / (L * f) = 0.152 A_pp
I_peak ~= 2.44 + 0.152/2 = 2.52 A
```

Der TPS63070 spezifiziert ein **durchschnittliches** positives
Eingangsstromlimit von mindestens 3.05 A. Der korrekte Vergleich ist daher
`I_IN,avg = 2.44 A < 3.05 A`; `I_peak = 2.52 A` dient hier nur zur Prüfung
von Induktor und Schaltstromform. Das ist kein thermischer Nachweis. 1.5 A
ist der Dauerzielwert, 2.0 A ein kurzer Peak.

Beim Kaltstart gilt eine zusätzliche Grenze: Solange VOUT noch unter 3.0 V
liegt, garantiert TI den Start erst ab `VIN = 3.0 V`. Nach erfolgreichem
Start darf der Wandler bis 2.0 V weiterarbeiten. Ein nur 2.8 bis 3.0 V starker
Akku kann die Karte deshalb nach Einstecken eventuell nicht starten; USB
hebt `VSYS` zum Wiederanlauf an. Dieses Verhalten muss im Prototyp gezielt
getestet werden und ist als dokumentierte Unterspannungs-Wake-Bedingung zu
behandeln.

### 6.3 RNM0015A-Footprint

Verbindliche Quelle ist TI Package Drawing `MPQF446A`, Drawing 4222000 Rev. B.
Die TI-Landpattern-Seite nennt unter anderem:

- acht NSMD-Randpads 1 bis 6, 14 und 15 mit je 0.25 x 0.60 mm;
- die SMD-Powerpads 7 bis 13 sind zusammengesetzte Kupferformen, unter
  anderem mit vier 0.25-x-0.60-mm-Randfingern sowie 0.25-, 0.525-, 0.75- und
  1.35-mm-Abmessungen gemäß Zeichnung;
- 0.5-mm-Pitch; die Referenzmaße 2.8, 1.7, 1.15 und 0.6 mm müssen in ihrer
  gezeichneten Achse übernommen und dürfen nicht als Bounding-Box gelesen werden;
- Pads 1 bis 6, 14 und 15 non-solder-mask-defined;
- Pads 7 bis 13 solder-mask-defined;
- 0.125-mm-Schablone und 85 % Paste-Coverage für die exponierten Pads 9 bis 11.

Der Custom-Footprint muss vollständig gegen Seite 2 und 3 dieser Zeichnung
geprüft werden. Automatische Erzeugung als gleichförmiges 15-Pad-QFN ist
verboten. Vor Bestellung sind 1:1-PDF, Courtyard, Paste, Mask und Pin-1-
Kennzeichnung manuell zu kontrollieren.

Layout: L6 direkt zwischen L1 und L2, Eingangskondensatoren unmittelbar an
VIN/PGND, Ausgangskondensatoren unmittelbar an VOUT/PGND. FB-Teiler an Pin 5,
weit weg von L1/L2 und Induktor; GND-Seite des Teilers an ruhige GND-Zone.
TI fordert außerdem einen Serienwiderstand, wenn EN oder PS/SYNC fest an VIN
gebunden werden. R116 ist deshalb der gemeinsame 10-kOhm-Widerstand für beide
Pins; eine direkte beziehungsweise 0-Ohm-Verbindung von EN nach VSYS ist nicht
zulässig.

## 7. Schaltbare +5V mit TPS61023

U7: TI `TPS61023DRLR`, DRL / SOT-563-6. KiCad:
`Package_TO_SOT_SMD:SOT-563`. JLCPCB-Bestückung zwingend.

| Pin | Name | Netz / Beschaltung |
|---:|---|---|
| 1 | FB | Mittelpunkt 732 kOhm / 100 kOhm |
| 2 | EN | `BOOST5_EN`; 100 kOhm Pulldown, Steuerung über U18/P5 |
| 3 | VIN | `VSYS` |
| 4 | GND | GND |
| 5 | SW | L7 Anschluss 2 |
| 6 | VOUT | `+5V_RAW` |

| Ref | Teil / Wert | Package |
|---|---|---|
| L7 | Cyntec `HBME042A-1R0MS-99`, 1.0 uH, DCR 11.5 mOhm, Isat 7 A | 4.1 x 4.1 x 2.1 mm |
| C114 | 10 uF, >=10 V, X5R/X7R | 0805 |
| C115/C116 | je 22 uF, >=10 V, X5R/X7R | 0805 |
| R120 | 732 kOhm, 1 % | 0805 |
| R121 | 100 kOhm, 1 % | 0805 |
| C113 | 220 pF, C0G, parallel zu R120 | 0603 oder 0805 |

```text
V_OUT,typ = 0.595 * (1 + 732k / 100k) = 4.950 V
f_zero = 1 / (2*pi*732k*220pF) = 989 Hz
```

TI empfiehlt den Feed-forward-Kondensator bei mehr als 40 uF nominaler
Ausgangskapazität. Die 44 uF nominal müssen unter 5-V-DC-Bias noch genügend
effektive Kapazität liefern.

Worst-case-Abschätzung bei `VIN=3.0 V`, `VOUT=5.0 V`, `IOUT=1.5 A`,
`eta=90 %`, `f=1 MHz`, `L=1 uH`:

```text
I_IN,avg = 5.0 * 1.5 / (3.0 * 0.90) = 2.78 A
D ~= 1 - (3.0 * 0.90 / 5.0) = 0.46
Delta_I ~= 3.0 * 0.46 / (1uH * 1MHz) = 1.38 A_pp
I_valley ~= 2.78 - 1.38/2 = 2.09 A
I_peak ~= 2.78 + 1.38/2 = 3.47 A
```

Der TPS61023 begrenzt den **Valley-Strom**; `I_valley = 2.09 A` liegt unter
dem garantierten Mindestlimit von 2.7 A. `I_peak` ist dagegen gegen die
Induktorsättigung zu prüfen. Der 7-A-Induktor hat ausreichend Reserve. Der
reale Dauerzielwert der gesamten 5-V-Schiene ist 1.0 A, 1.5 A nur kurz. Die
Schiene ist nach Reset aus. `+5V_RAW` versorgt IR und den Eingang des
Header-Load-Switch; Firmware muss beide Lasten gemeinsam budgetieren.

Zur Regelschleife gehören nicht nur die beiden 22-uF-Kondensatoren direkt an
U7: Auch 10 uF + 100 nF am Eingang von U15 liegen permanent an `+5V_RAW`.
Damit sind bereits rund 54.1 uF nominal angeschlossen, zuzüglich lokaler
IR-Abblockung. Diese Gesamtkapazität bleibt weit innerhalb des von TI
erlaubten Bereichs von 4 bis 1000 uF effektiv, muss aber beim Enable-Start,
Lastsprungtest und bei der Feed-forward-Kompensation gemeinsam betrachtet
werden.

Optionaler Diagnose-ADC: 100 kOhm von `+5V_RAW` auf `ADC_5V_MON`, 33 kOhm von
dort nach GND und 10 nF nach GND. Bei 5 V entstehen ca. 1.24 V.

Die IR-Stufe erhält zusätzlich direkt am lokalen Pulsstromkreis C607 mit
22 uF/10 V X5R im handfreundlichen 1206-Gehäuse und C608 mit 100 nF im
0805-Gehäuse. Beide liegen von `+5V_RAW` nach GND und gehören räumlich zu
R601/D1/Q1, nicht zum entfernten U7-Ausgangskondensatorbank.

## 8. 500-mA-Load-Switch für den Header

U15: TI `TPS2553DBVR`, ausdrücklich **ohne `-1`**. DBV / SOT-23-6,
KiCad `Package_TO_SOT_SMD:SOT-23-6`. TPS2553 ist active-high und bleibt bei
Überlast zunächst im Konstantstrombetrieb; bei zu hoher Verlustleistung
kann er thermisch aus- und wieder einschalten. Nach Entfernen der Überlast
kehrt er selbstständig zum Normalbetrieb zurück. Die `-1`-Variante würde
dagegen verriegeln.

| Pin | Name | Netz / Beschaltung |
|---:|---|---|
| 1 | IN | `+5V_RAW`; 100 nF + 10 uF nach GND |
| 2 | GND | GND |
| 3 | EN | `AUX5_EN`; 100 kOhm Pulldown nach GND |
| 4 | FAULT | `AUX5_FAULT_N`; 100 kOhm Pull-up nach +3V3 |
| 5 | ILIM | 60.4 kOhm, 1 %, nach GND |
| 6 | OUT | `+5V_AUX`; 100 nF + 10 uF nach GND |

Mit den TI-Grenzgleichungen:

```text
R_nom = 60.4 kOhm, R_low = 59.796 kOhm, R_high = 61.004 kOhm
I_OS,max = 22980 / R_low^0.94 = 491 mA
I_OS,nom = 23950 / R_nom^0.977 = 436 mA
I_OS,min = 25230 / R_high^1.016 = 387 mA
```

Diese Dimensionierung garantiert rechnerisch weniger als 500 mA, liefert
aber typisch nur rund 436 mA. Falls stattdessen "500 mA nominal" gewünscht
wird, wären etwa 52.3 kOhm nötig; dann kann die obere Stromgrenze ungefähr
562 mA erreichen. Für den als 500-mA-Maximum beschrifteten Header bleibt
60.4 kOhm die festgelegte Variante.

Die +5-V-Ausgabe liegt nur auf einem Header-Pin. Daneben mindestens zwei
GND-Pins vorsehen. Auf dem Silkscreen: `5V OUT, <=0.5A, NOT INPUT`.

## 9. Fertigungs- und Footprint-Matrix

| Ref | Bestellteil | Gehäuse | KiCad / Footprint-Quelle | Bestückung |
|---|---|---|---|---|
| J1 | HRO TYPE-C-31-M-12 | Hybrid SMD/THT | stock HRO footprint | JLC oder Hand |
| U16 | USBLC6-4SC6Y | SOT-23-6L | SOT-23-6 | JLC, Hand-Rework möglich |
| U5 | BQ24074RGTR | RGT VQFN-16-EP 3x3 P0.5 | stock ThermalVias footprint | JLC only |
| U14 | BQ29700DSER | DSE WSON-6 1.5x1.5 P0.5 | stock WSON-6 | JLC only |
| Q2/Q3 | CSD16406Q3 | DQG VSON-CLIP 3.3x3.3 | stock NexFET footprint | JLC only |
| U8 | MAX17048G+T10 | TDFN-8-EP 2x2 P0.5 | stock TDFN footprint | JLC only |
| U6 | TPS63070RNMR | RNM VQFN-HR-15 3x2.5 | **custom nach MPQF446A** | JLC only |
| U7 | TPS61023DRLR | DRL SOT-563-6 | stock SOT-563 | JLC only |
| U15 | TPS2553DBVR | DBV SOT-23-6 | stock SOT-23-6 | JLC, Hand-Rework möglich |
| L6 | XFL4020-152MEC | 4.0x4.0x2.1 | `PocketLab_Custom:Coilcraft_XFL4020` | JLC |
| L7 | HBME042A-1R0MS-99 | 4.1x4.1x2.1 | `PocketLab_Custom:Cyntec_HBME042A` | JLC |

Allgemeine Widerstände und Kondensatoren bleiben 0805. Nur die beiden von TI
vorgesehenen TPS63070-HF-Bypässe C123/C124 und C113 dürfen 0603 sein; C113 kann auch
0805 werden, wenn ein geeignetes C0G-Teil verfügbar ist. Polaritätsmarkierungen für D101, J4, U5, U6, U7, U8 und U14 müssen
auf Fab und Silkscreen sichtbar sein. Der Akku-Plus-Pin erhält zusätzlich ein
großes `+` im Silkscreen.

## 10. Layoutregeln

1. Power-Pfad `CELL_POS -> BQ24074 BAT` und `CELL_NEG -> FETs -> GND` breit
   und kurz führen; keine Thermals an den Hochstrompads.
2. BQ29700, RC-Filter und beide MOSFETs bilden eine kompakte Insel direkt am
   Akkustecker. V- als Kelvin-Sense nach `PACK_NEG` führen.
3. Die vier Schaltknoten L1/L2 des TPS63070 und SW des TPS61023 so klein wie
   möglich halten; keine Signale oder Kupferflächen direkt darunter.
4. Beide Wandler erhalten eigene lokale Eingangskeramiken und eine kurze,
   niederinduktive PGND-Rückführung.
5. FB-Leitungen nicht unter Induktoren oder an Schaltknoten entlangführen.
6. BQ24074-EP an zusammenhängende GND-Fläche mit Thermal-Vias; keine
   Plane-Splits unter dem IC.
7. U16 und D101 direkt am Stecker platzieren. ESD-Rückweg darf
   nicht durch die digitale Masseinsel laufen.
8. Bestückte Testpunkte: TP101 `CELL_POS`, TP102 `CELL_NEG`, TP103
   `BAT_FET_MID`, TP104 GND, TP105 `VBUS_USB`, TP106 `VBUS_FUSED`, TP107
   `VSYS`, TP108 `+3V3`, TP109 `+5V_RAW` und TP110 `+5V_AUX`.
9. TP104 ist der gemeinsame GND-Testpunkt; lokale Masse-Probe-Pads dürfen beim
   Layout nahe kritischer Rails ergänzt werden, sofern der Platz reicht.
10. Schaltwandler und Induktoren maximal weit vom LF-RX-Eingang,
    NFC-Matching und Sub-GHz-RF-Pfad entfernt platzieren.

## 11. Bring-up und Abnahmekriterien

Vor Anschluss eines LiPos zuerst mit strombegrenztem Netzteil prüfen.
Der Zellensimulator muss gegenüber USB und Oszilloskopmasse potentialfrei
sein. Ein geerdeter Tastkopf gleichzeitig an `CELL_NEG` und System-GND würde
die Schutz-MOSFETs überbrücken und den Test ungültig beziehungsweise gefährlich
machen.

1. Widerstands-/Diodentest bei unbestücktem Akku: kein Kurzschluss zwischen
   `CELL_POS`, GND, 3V3 und 5V.
2. Labornetzteil als Zelle, 3.7 V und 100 mA Limit: korrekte Polarität,
   Ruhestrom und `VSYS` prüfen.
3. Unterspannungsabschaltung langsam durch 2.8 V fahren; Schutzereignis und
   Wiederanlauf dokumentieren. TPS63070-Kaltstart getrennt bei 2.8, 2.9 und
   3.0 V testen; unter 3.0 V ist der Start nicht garantiert.
4. USB bei abgestecktem Akku: Default USB100 messen. Per Firmware erst danach
   USB500 aktivieren.
5. Ladekennlinie bei 3.0-V-Zellensimulator prüfen: Vorladung, 500-mA-Ziel,
   CV-Regelung, etwa 51-mA-Terminierung und Timer.
6. U5-Thermografie im ungünstigsten linearen Ladefall durchführen.
7. 3V3 mit 0, 0.5, 1.0, 1.5 A sowie 2-A-Puls testen; Ripple, Start und
   Übergang bei VSYS 2.9 bis 4.5 V messen.
8. 5V mit 0, 0.5, 1.0 A sowie 1.5-A-Puls testen; Start/Stop und Überschwingen
   prüfen.
9. Headerlast langsam erhöhen: Mit 60.4 kOhm muss TPS2553 ungefähr zwischen
   0.387 und 0.491 A limitieren und `AUX5_FAULT_N` Low melden. Eine Messung
   außerhalb dieses Fensters deutet auf Bestückungs- oder Layoutfehler.
10. USB-Daten mit HS-Eye/Packet-Fehlerrate soweit verfügbar prüfen; mindestens
    Flash, CDC und längerer Datentransfer mit beiden Steckerorientierungen.
11. RF-Rauschvergleich mit allen Wandlerzuständen durchführen, besonders
    LF-RFID-Reichweite/Phase, Sub-GHz-Empfang und NFC-Lesereichweite.
12. Erst nach diesen Tests einen realen, geschützten 4.2-V-LiPo anschließen.

## 12. Offizielle Quellen

- TI BQ24074 Datenblatt: <https://www.ti.com/lit/ds/symlink/bq24074.pdf>
- TI TPS63070 Datenblatt: <https://www.ti.com/lit/ds/symlink/tps63070.pdf>
- TI RNM0015A Package Drawing: <https://www.ti.com/lit/ml/mpqf446a/mpqf446a.pdf>
- TI TPS61023 Datenblatt: <https://www.ti.com/lit/ds/symlink/tps61023.pdf>
- TI TPS61023EVM-052 User Guide: <https://www.ti.com/lit/ug/slvubp5/slvubp5.pdf>
- TI TPS2553 Datenblatt: <https://www.ti.com/lit/ds/symlink/tps2553.pdf>
- TI BQ2970-Familie: <https://www.ti.com/lit/ds/symlink/bq2970.pdf>
- TI BQ29700 EVM: <https://www.ti.com/lit/ug/sluuaz3/sluuaz3.pdf>
- TI CSD16406Q3 Datenblatt: <https://www.ti.com/lit/ds/symlink/csd16406q3.pdf>
- Analog Devices MAX17048/MAX17049: <https://www.analog.com/media/en/technical-documentation/data-sheets/max17048-max17049.pdf>
- ST USBLC6-4SC6Y: <https://www.st.com/resource/en/datasheet/usblc6-4sc6y.pdf>
- TI USB Type-C Engineer's Guide: <https://www.ti.com/lit/eb/slyy228/slyy228.pdf>
- USB-IF Type-C Cable and Connector Specification: <https://www.usb.org/usb-type-cr-cable-and-connector-specification>
- Littelfuse 1206L-Serie: <https://www.littelfuse.com/assetdocs/littelfuse-ptc-1206l-datasheet>
- Littelfuse SMF-Serie: <https://www.littelfuse.com/~/media/electronics/datasheets/tvs_diodes/littelfuse_tvs_diode_smf_datasheet.pdf.pdf>
- HRO TYPE-C-31-M-12: <https://en.krhro.com/Product-Details/726.html>
- JST PH-Serie: <https://www.jst.com/wp-content/uploads/2025/06/ePH.pdf>
- Espressif ESP32-S3 Hardware Design Guidelines: <https://docs.espressif.com/projects/esp-hardware-design-guidelines/en/latest/esp32s3/schematic-checklist.html>
- Coilcraft XFL4020 Datenblatt: <https://www.coilcraft.com/getmedia/50632d43-da1b-4cdb-8ab4-3029cab51df3/xfl4020.pdf>

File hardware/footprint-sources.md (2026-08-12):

# Footprint sources and status

The generated board uses stock KiCad 10 footprints where the exact package is
available. Every schematic symbol with a footprint is loaded and pad-audited by
`scripts/build_pcb.py`; the build stops if a required pin is absent or an
unexpected electrical pad is present.

Project-local footprints:

| Footprint | Basis | Release note |
|---|---|---|
| `PocketLab_Card:ESP32-S3-WROOM-1_PhysicalCourtyard` | KiCad 10 `RF_Module:ESP32-S3-WROOM-1`; only the oversized antenna-inclusive courtyard was replaced by an 18.70 x 26.10 mm physical-body courtyard, 0.25 mm beyond the stock F.Fab body outline | The stock 48 x 21 mm multilayer antenna keepout, pads, Fab, Silk and 3D model remain unchanged; U1 is assigned this variant by the schematic generator |
| `E07-900MM10S` | Ebyte's official 10 x 10 mm, 20-pad mechanical drawing and pin table | Verify the received castellated module, pin-1 orientation and pin-6 antenna escape before assembly |
| `T3-868M_Edge_Solder` | DreamLNK T3-868M 17 x 5.5 mm cylindrical spring envelope plus one electrical feed pad and a marked nonconductive free-end anchor | Hand fit only; never solder the free end, tune with the final board/enclosure, and keep the 18.8 x 6.58 mm pocket free of copper and enclosure metal |
| `TSAL6200_LayFlat_Inboard` | Vishay TSAL6200 body envelope with project-defined 90-degree formed leads | Use a forming jig; confirm polarity and keep all three optical bodies inside the rounded card outline |
| `Dupont_Grid_6x5_P2.54mm` | Project-defined row-major 30-pad matrix using 1.0 mm drills | Individual leads/short strips only; compare pad numbering with `docs/pinout.md` before wiring |
| `TPS63070_RNM0015A` | TI MPQF446A / drawing 4222000 Rev. B | Asymmetric power lands and split paste require 1:1 fabrication review |
| `BMP390_LGA-10_2x2mm` | Bosch BST-BMP390-DS002-07 | Manufacturer bottom view was mirrored to the component-side land pattern; inspect pin 1 in the assembler viewer |
| `TSOP75338WTR_HeimdallW_SideView` | Vishay drawing 6.550-5300.01-4 | Keep the optical face at the board edge and verify reel orientation |
| `Coilcraft_XFL4020` | Coilcraft XFL4020 drawing 745-3 | Used by L6; verify selected inductor suffix and height |
| `Cyntec_HBME042A-1R0MS` | TI part callout plus Cyntec HBLE042A official land drawing | Used by L7; verify the orderable suffix and received geometry |
| `NFC_Loop_35x27mm_4T_TUNE` | Original four-turn 0.50/0.50-mm PCB geometry | Prototype only; final matching must be measured on the assembled card with a VNA |
| `CSD16406Q3_VSON-8_3.3x3.3mm_P0.65mm_JLC` | KiCad 10 NexFET VSON footprint and TI CSD16406Q3 DQG package; signal lands 1-4 narrowed by 0.01 mm | Keeps the minimum different-net pad gap at JLCPCB's 0.15 mm limit; verify the exact DQG land/stencil pattern in the assembler viewer |
| `EastRising_ER-OLED0.42-1W_SolderFPC` | EastRising ER-OLED0.42-1 mechanical drawing: 12 x 11 mm glass and 16 contacts at 0.65 mm pitch; local WRL is only a dimensioned 3D preview | Manual fine-pitch operation: solder the FPC first, inspect every joint, then fold and bond the glass; verify pin 1 and contact side against the received panel before assembly |

Primary source links are embedded in each `.kicad_mod` description so they
remain visible in KiCad's footprint properties. The NFC footprint also embeds
a 36 x 29 mm all-copper-layer foreign-copper and component keepout, including
its inner opening. None of these files is a substitute for the final 1:1 PDF,
paste/mask, pin-1 and JLCPCB assembly-viewer sign-off before ordering.

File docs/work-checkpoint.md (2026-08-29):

# Work checkpoint — 2026-08-30

## Routing/DRC continuation — 2026-08-30

- The active board is `hardware/PocketLab-Card-routing-working.kicad_pcb`.
  It contains 2,843 track segments, 575 conventional through-vias and 23
  zones. KiCad connectivity reports 0 open connection items.
- This continuation reassigned ten reviewed long signal segments between the
  two inner copper layers. Every accepted change was tested separately and in
  combination; no track coordinates, footprints, vias or net assignments were
  changed.
- One additional USER_BUTTON_A_N diagonal was replaced by a four-segment,
  obstacle-aware path on the same inner layer. This reduced its local median
  from 20 to 18 findings without adding a via or an open connection.
- The latest continuation rerouted EX4, EX5, CHG_TS_FIXED, GPIO8_MCU and
  SD_DETECT_N, moved AUX5_FAULT_N and BAT_SENSE vias with layer-matched
  fanouts, and reassigned CHARGER_CHG_N from L2 to L3. All accepted edits
  retain 0 open connection items and use only conventional through-vias.
- Three final full-board DRC runs reported 1,162, 1,164 and 1,166 findings.
  The saved median report has 502 clearance, 4 copper-edge, 201 hole-clearance,
  199 shorting, 106 solder-mask bridge and 147 crossing findings. Crossing
  counts are not fully deterministic between
  otherwise identical KiCad CLI runs, so local repeated checks are used when
  accepting a routing-layer change.
- The stale AE1 NFC-loop library rule now matches the intentional board
  keepout and no longer causes a footprint mismatch. The remaining comparison
  findings include project-specific board geometry on U1/U3 plus current
  KiCad standard-library differences; they are documented rather than
  overwritten blindly.
- This is a saved engineering checkpoint, not an order-ready fabrication
  release.

## Active PCB routing state — 2026-08-21

- Work has resumed on the PCB only; firmware and app work remain deferred.
- The 2026-08-16 continuation corrected the physical internal-contact
  semantics of the six KMR2 switches and the continuous J1/J2 shell contacts.
  This removed one false ratsnest item without adding copper. J2 was also
  shifted 0.175 mm inward; all ten microSD copper-to-edge findings are gone
  while the adjacent B.Cu ground track retains exactly 0.20 mm clearance.
- U2.5 and U2.8 now share a short, via-free 0.15-mm NFC_DVDD escape on F.Cu.
  The former long U2.3 ground branch was folded directly into the exposed GND
  pad, one redundant west-side GND via was removed, and the retained plane via
  moved 0.20 mm right / 0.10 mm up into a clearance-clean site. U2.3, U2.7 and U2.41 remain
  explicitly connectivity-checked to GND.
- Current local checkpoint saved on 2026-08-21 Europe/Berlin; the
  authoritative PCB, DRC/ERC reports and progress documentation are in sync.
  No commit or remote push was requested in this continuation.
- LF RFID shares the existing SPI SCK/MOSI/MISO bus. U21 remains the
  partial-power-down-safe SN74LV125ATPWR (LCSC C2675655), and U22 remains the
  LF_RFID_EN-controlled SN74LVC1G126DBVR (LCSC C7834). U21 channels 2 and 4
  translate SCK and MOSI; the unused channel input/OE pairs are grounded and
  their outputs are NC. This avoids back-powering or driving an unpowered LF
  domain while giving all seven U21 GND pads short inner-plane connections.
- Six global LF/shared-SPI data paths are routed and connectivity-checked:
  SPI_SCK, SPI_MOSI, SPI_MISO, LF_SCLK_5V, LF_DIN_5V and LF_DOUT_5V.
  The LF_RFID_EN U22 enable endpoint is now complete. A redundant +3V3 fanout
  via in the dense PN532/U22 field was removed, R109 now joins the retained
  +3V3 branch directly, and U22.1 reaches the existing LF-enable trunk through
  a 0.45/0.20-mm via and a reviewed 0.20-mm L3 route. L2 remains plane-only;
  `scripts/route_lf_enable.py` reproduces and connectivity-checks this stage.
  The low-current LF_5V branch from the existing distribution via C515 to U21
  is also complete, with a reviewed 0.39-mm TSSOP neckdown.
- The dense U8/U11 sensor corridor is now reworked. U8 SCL reaches U1.6
  through two standard 0.45/0.20-mm through-vias and a short L3 crossing;
  U8 SDA reaches U11.4 directly on B.Cu. `FG_ALERT_N` and `SPI_MOSI` were
  rerouted around the corridor, and the local U11.3/U11.5 ground branches were
  restored. `scripts/route_i2c_sensor_corridor.py` reproduces and checks all
  six affected endpoint pairs while L2 remains ground-only.
- The dense-plane cleanup is complete. All GND and +3V3 islands are now
  closed, including the difficult U2.40, C704 and microSD J2.4 fanouts. U2.40
  uses a reviewed local reroute of LF_SCLK_5V/LF_DIN_5V; C704 is connected on
  B.Cu without a via below U21, and J2.4 reaches the L3 +3V3 plane through a
  clearance-checked 0.45/0.20-mm via.
- The accepted charger and battery-protection power stages are complete.
  VBUS_FUSED now joins F1, D101,
  C106, C103, U5.13 and U16.5 with 0.50/0.60-mm copper and one ordinary
  0.80/0.40-mm via. Both U5 CELL_POS pins join C121/C104 through short local
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

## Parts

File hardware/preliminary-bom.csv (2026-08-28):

Ref | Manufacturer | MPN | LCSC_or_gap | Package_or_footprint | Function | Assembly_class | Status_or_note
U1 | Espressif | ESP32-S3-WROOM-1-N8R2 | C2913204 | RF_Module:ESP32-S3-WROOM-1 | Wi-Fi/BLE MCU | PCBA_FACTORY | Selected; preserve module antenna keepout
U2 | NXP | PN5321A3HN/C106 | C880904 | HVQFN-40-EP_6x6mm | NFC controller | PCBA_FACTORY | Selected NRND part; prototype and sourcing review required
AE1 | PCB | etched_loop | N/A | PocketLab_Custom:NFC_Loop_35x27mm_4T_TUNE | NFC antenna | PCB_FEATURE | VNA tuning mandatory on fabricated board
U3 | Ebyte | E07-900MM10S | C5844212 | PocketLab_Custom:E07-900MM10S | 855-925MHz CC1101 module with direct 50ohm antenna pad | PCBA_FACTORY | Selected 10x10mm module; 3.3V only; EU 868MHz configuration required
A1 | DreamLNK | T3-868M | C381193 | PocketLab_Custom:T3-868M_Edge_Solder | 868MHz 50ohm spring antenna | MANUAL_EDGE_SOLDER | Hand-solder horizontally into the 18.8x6.58mm inboard pocket across the 0.6mm PCB bridge to the adjacent pad and add nonconductive strain relief; complete antenna remains inside card outline
U4 | NXP | HTRC11001T/03EE,11 | C501317 | SOIC-14_3.9x8.7mm_P1.27mm | 125kHz LF-RFID analogue front end | PCBA_FACTORY_OR_HAND | Use current /03EE revision; tune only with the actual external coil
U5 | Texas Instruments | BQ24074RGTR | C54313 | VQFN-16-EP_3x3mm | 1-cell charger and power path | PCBA_FACTORY | Selected; thermal-pad placement
U6 | Texas Instruments | TPS63070RNMR | C109322 | PocketLab_Custom:TPS63070_RNM0015A | 3.3V buck-boost | PCBA_FACTORY | Selected; custom asymmetric power footprint
U7 | Texas Instruments | TPS61023DRLR | C919459 | SOT-563 | Switchable 5V boost | PCBA_FACTORY | Selected; factory placement only
U8 | Analog Devices | MAX17048G+T10 | C2682616 | TDFN-8-EP_2x2mm | LiPo fuel gauge | PCBA_FACTORY | Selected
U9 | Texas Instruments | TCA9535PWR | C130204 | TSSOP-24 | Header GPIO expander | PCBA_FACTORY | Selected
U10 | Bosch | BMI270 | C2836813 | LGA-14_3x2.5mm | 6-axis IMU | PCBA_FACTORY | Full prototype variant
U11 | Bosch | BMP390 | C5124834 | PocketLab_Custom:BMP390_LGA-10_2x2mm | Barometric sensor | PCBA_FACTORY | Full prototype variant
U12 | NXP | PCF8563T/5,518 | C7440 | SOIC-8 | Low-power RTC | PCBA_FACTORY | Selected hand-reworkable package
U13 | Vishay | TSOP75338WTR | PROCUREMENT_GAP | PocketLab_Custom:TSOP75338WTR_HeimdallW_SideView | 38kHz IR receiver | PCBA_FACTORY | Exact optical orientation must be reviewed
U14 | Texas Instruments | BQ29700DSER | PROCUREMENT_GAP | WSON-6_1.5x1.5mm | 1-cell protection controller | PCBA_FACTORY | Selected; complements but does not replace protected pack
Q2/Q3 | Texas Instruments | CSD16406Q3 | PROCUREMENT_GAP | VSON-8_3.3x3.3mm_NexFET | Back-to-back battery protection FETs | PCBA_FACTORY | Common-drain orientation must be visually checked
U15 | Texas Instruments | TPS2553DBVR | PROCUREMENT_GAP | SOT-23-6 | 500mA auxiliary output limiter | PCBA_FACTORY | Selected non-latching variant
U16 | STMicroelectronics | USBLC6-4SC6Y | PROCUREMENT_GAP | SOT-23-6 | USB and CC ESD array | PCBA_FACTORY | Place directly at J1
U17 | Texas Instruments | TPS22919DCKR | C2149796 | SC-70-6 | LF 5V load switch | PCBA_FACTORY | Selected; controlled by U18 P4
U18 | Texas Instruments | TCA9534PWR | PROCUREMENT_GAP | TSSOP-16 | Internal control expander | PCBA_FACTORY | Selected
U19/U24/U25 | onsemi | SRV05-4MR6T1G | PROCUREMENT_GAP | SOT-23-6 | microSD plus J5 I2C/SPI ESD arrays | PCBA_FACTORY | Selected; U24/U25 protect only the five shared header bus lines
U20 | Texas Instruments | SN74AHCT1G126DBVR | C163712 | SOT-23-5 | 3.3V-to-5V RGB data buffer | PCBA_FACTORY_OR_HAND | Active-high OE follows BOOST5_EN; output is high-impedance while 5V is off
C601/C603-C606/C609 | Yageo | CC0805KRX7R9BB104 | C49678 | 0805 | 100nF local IR/RGB decoupling | PCBA_FACTORY_OR_HAND | Hand-reworkable X7R source; C609 must sit directly at U20
C602 | Samsung Electro-Mechanics | CL21A475KAQNNNE | C1779 | 0805 | 4.7uF IR receiver supply filter | PCBA_FACTORY_OR_HAND | Hand-reworkable X5R source
R604 | Yageo | RC0805FR-07100RL | C105577 | 0805 | IR receiver supply filter resistor | PCBA_FACTORY_OR_HAND | 100R 1 percent
R605 | Yageo | RC0603FR-0768RL | PROCUREMENT_GAP | 0603 | RGB data source termination | PCBA_FACTORY_OR_HAND | 68R 1 percent; place at U20 pin 4
D101 | Littelfuse | SMF5.0A | PROCUREMENT_GAP | SOD-123F | USB VBUS TVS | PCBA_FACTORY | Unidirectional polarity is critical
F1 | Littelfuse | 1206L075/13.2 | PROCUREMENT_GAP | 1206 | USB resettable fuse | PCBA_FACTORY | Exact voltage and hold-current grade
L6 | Coilcraft | XFL4020-152MEC | PROCUREMENT_GAP | PocketLab_Custom:Coilcraft_XFL4020 | TPS63070 inductor | PCBA_FACTORY | Footprint and height review required
L7 | Cyntec | HBME042A-1R0MS-99 | PROCUREMENT_GAP | PocketLab_Custom:Cyntec_HBME042A-1R0MS | TPS61023 inductor | PCBA_FACTORY | Footprint and height review required
Y301 | TBD | 27.12MHz_CL7pF | PROCUREMENT_GAP | Crystal_SMD_3225-4Pin | NFC crystal | PCBA_FACTORY | Exact load capacitance and ESR must be frozen
Y701 | Abracon | ABS07-32.768KHZ-7-T | PROCUREMENT_GAP | Crystal_SMD_3215-2Pin | RTC crystal | PCBA_FACTORY | Selected CL=7pF
J1 | HRO | TYPE-C-31-M-12 | C165948 | USB_C_Hybrid_THT | USB-C data and power | PCBA_FACTORY_OR_HAND | Through-hole shell adds mechanical strength
J2 | Molex | 104031-0811 | PROCUREMENT_GAP | Connector_Card:microSD_HC_Molex_104031-0811 | microSD socket | PCBA_FACTORY | Exact connector footprint selected
J3 | Generic | 1x02_P2.54mm | N/A | PinHeader_1x02_P2.54mm_Vertical | Removable 400uH LF antenna coil | MANUAL_THT | Fit only after measuring coil inductance and selecting C506/C507/C508
J4 | JST | S2B-PH-SM4-TB | PROCUREMENT_GAP | JST_PH_side_entry | Protected 1S LiPo connector | PCBA_FACTORY_OR_HAND | Back-side mounted and rotated 90deg left from prior front view; verify cable exit and polarity before connection
J5 | Generic | 30pin_6x5_P2.54mm | N/A | PocketLab_Custom:Dupont_Grid_6x5_P2.54mm | Dupont expansion and optional NTC on pins 28/30 | MANUAL_THT | Ships unpopulated; accepts individual Dupont leads or breakaway strips but not one monolithic 2x15 housing; cut SJ1 before external NTC use
U21 | Texas Instruments | SN74AHCT125PWR | C36365 | TSSOP-14 | LF SCLK and DIN 3.3V-to-5V translation | PCBA_FACTORY | Two unused channels disabled
U22 | Texas Instruments | SN74LVC1G17DBVR | C7836 | SOT-23-5_HandSoldering | LF DOUT 5V-to-3.3V Schmitt buffer | PCBA_FACTORY_OR_HAND | 5.5V-tolerant input
U23 | Microchip | ATECC608C-SSHDA-T | C28975195 | SOIC-8_3.9x4.9mm_P1.27mm | Secure identity and future owner keys | PCBA_FACTORY_OR_HAND | Ship unprovisioned; zone locking is a separate irreversible release step
RT701 | KUU | KNTC0603/10KF3950 | C2892547 | 0603 | 10k B3950 board-temperature NTC | PCBA_FACTORY_OR_HAND | Selected 1 percent B3950 part; place beside 5V converter area
R736 | UNI-ROYAL | 0603WAF1002T5E | C25804 | 0603 | Board-temperature divider bias | PCBA_FACTORY_OR_HAND | 10k 1 percent; pair with RT701
Y501 | YXC | 4MHz_5V_CMOS | C42448900 | Oscillator_SMD_3.2x2.5mm | HTRC110 external clock | PCBA_FACTORY | Verify 40-60 percent duty cycle
SW6 | C&K | KMR221GLFS | C72443 | SW_Push_1P1T_NO_CK_KMR2 | Dedicated physical PAIR button | PCBA_FACTORY | Active low on GPIO38
SW3/SW4/SW7 | C&K | KMR221GLFS | C72443 | SW_Push_1P1T_NO_CK_KMR2 | UP DOWN and SELECT navigation buttons | PCBA_FACTORY | Three adjacent labeled 4.6x2.8mm switches; SELECT uses U9 P07 and does not share PAIR
SW8 | C&K | KXT311LHS | PROCUREMENT_GAP | Button_Switch_SMD:SW_SPST_CK_KXT3 | Firmware-configurable AUX button on GPIO21 | PCBA_FACTORY | Active low; firmware must enable the ESP32-S3 GPIO21 internal pull-up
C503/C504 | Qualified_sources | 100nF_X7R | PROCUREMENT_GAP | 0805 | HTRC CEXT and QGND bypass | PCBA_FACTORY_OR_HAND | Keep local to U4
C505-C508 | Qualified_sources | C0G_LF_tuning | PROCUREMENT_GAP | 0805_plus_0603 | Protected LF resonance network | PCBA_FACTORY_OR_HAND | C506 3.9nF starting value; C507/C508 DNP until measured tuning
R502 | Qualified_sources | 47R_0.5W_pulse | PROCUREMENT_GAP | 1210 | LF antenna current limiter | PCBA_FACTORY_OR_HAND | Validate current and temperature with final coil
R503/R504 | Qualified_sources | 1k_plus_150k_1percent | PROCUREMENT_GAP | 0805 | LF EMI return and protected RX divider | PCBA_FACTORY_OR_HAND | Keep inside the short resonant loop
SW1/SW2 | C&K | KMR221GLFS | C72443 | SW_Push_1P1T_NO_CK_KMR2 | Reset and boot service buttons | PCBA_FACTORY | Adjacent labeled 4.6x2.8mm service switches; keep separate from navigation row
SW5 | SHOUHAN | MSK12C02 | C431540 | SW_SPDT_Shouhan_MSK12C02 | Low-current main power enable switch | PCBA_FACTORY_OR_HAND | Switches TPS63070 EN only; does not interrupt charger or full battery current
D1-D3 | Vishay | TSAL6200 | C55528 | PocketLab_Custom:TSAL6200_LayFlat_Inboard | Three 940nm IR emitters | MANUAL_THT | Use one forming jig across each transverse 2.54mm lead pair; bend both pins 90 degrees on the same line and lay the body flat with its optical face 0.5mm inside the short edge
R601/R610/R611 | Qualified_sources | 39R_0.5W_1percent | PROCUREMENT_GAP | 1210 | Independent IR LED current limit resistors | PCBA_FACTORY_OR_HAND | One resistor per emitter; hand-solderable 1210 size is pulse-rated for the bounded IR burst duty; do not bridge or replace with one shared resistor
C607/C617/C608 | Qualified_sources | 2x22uF_10V_X5R_plus_100nF | PROCUREMENT_GAP | 1206_plus_0805 | Local 5V IR pulse buffer | PCBA_FACTORY_OR_HAND | Place directly at the three LED branches and Q1 hot loop; verify effective capacitance at 5V
LED1-LED4 | Worldsemi | WS2812B-2020 | C965555 | LED_2020 | Compact 5V addressable RGB LEDs | PCBA_FACTORY | 2.0mm package is not intended for routine hand placement; pin-1 and JLC assembly-view review required
R/C_general | Qualified_sources | 1percent_X7R_X5R | PROCUREMENT_GAP | 0805 | General passives | PCBA_FACTORY | Exact MPN and LCSC population remains release-gated
RF_passives | Qualified_sources | C0G_high_Q | PROCUREMENT_GAP | 0603 | NFC and RF matching | PCBA_FACTORY | C310-C312 remain DNP until measurement

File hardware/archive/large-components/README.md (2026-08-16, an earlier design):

# PocketLab Card – Großbauteil-Layout

Dieser Ordner bewahrt den bisherigen PCB-Stand mit den größeren und teilweise
manuell zu montierenden Bauteilen. Er wurde am 17. August 2026 vor einer
möglichen späteren Ablösung des Hauptlayouts archiviert.

Enthalten sind:

- `PocketLab-Card-large-components.kicad_pcb` – unveränderte Kopie des
  bisherigen Hauptboards aus `hardware/PocketLab-Card.kicad_pcb`
- `PocketLab-Card-large-components.kicad_pro` – zugehörige KiCad-Projekteinstellungen
- `PocketLab-Card-large-components.kicad_dru` – zugehörige Designregeln
- `PocketLab-Card-large-components-drc.json` – Prüfstand mit 16 DRC-Meldungen
  und 159 noch offenen Verbindungen

Kennzeichnend für diese Variante sind unter anderem die drei liegenden
TSAL6200-THT-IR-LEDs, KMR2-Taster sowie größere 0805-, 1206- und
1210-Bauteile. Das Layout ist ein Routing-Zwischenstand und nicht
produktionsfertig.

Die Schaltplandatei wurde nicht dupliziert, weil ihr aktueller Stand bereits
von diesem archivierten PCB-Zwischenstand abweichen kann. Für eine Fortsetzung
dieser Variante sollte zuerst die Netzlisten-/Schaltplanparität geprüft werden.

Archivquelle: Commit `644adf24fc94ed19b25fa6ac94114e8d47135f6a`.

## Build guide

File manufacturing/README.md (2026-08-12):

# PocketLab Card manufacturing handoff

This directory contains the reproducible KiCad 10 export pipeline. Generated
files are intentionally ignored by Git; reviewed release archives are created
as `manufacturing/PocketLab-Card-<release>.zip`.

> **Current status:** `hardware/PocketLab-Card.kicad_pcb` is still marked as a
> placement/routing draft. It is not order-ready. The exporter runs ERC and DRC
> and will currently stop before creating Gerbers. Do not upload the old board
> merely because KiCad can display it.

## Run the checks and export

Run from the repository root with KiCad 10 installed:

```powershell
# Reports and release gates only
powershell -ExecutionPolicy Bypass -File .\manufacturing\scripts\export_release.ps1 `
  -ReleaseName v1-proto -ChecksOnly -Force

# Complete fabrication handoff after every release gate passes
powershell -ExecutionPolicy Bypass -File .\manufacturing\scripts\export_release.ps1 `
  -ReleaseName v1-proto -Force

# PCBA handoff: additionally require Manufacturer, MPN and LCSC for every CPL row
powershell -ExecutionPolicy Bypass -File .\manufacturing\scripts\export_release.ps1 `
  -ReleaseName v1-proto -RequireCompleteProcurement -Force
```

If `kicad-cli` is not on `PATH`, the script finds the normal KiCad 10 Windows
installation. A nonstandard installation can be supplied with
`-KiCadCli 'C:\path\to\kicad-cli.exe'`. Releases must be made from a clean Git
working tree. `-AllowDirty` exists only for local draft checks and must not be
used for an ordered revision.

The pipeline performs these steps in order:

1. KiCad ERC, including all severities in `reports/erc.json`.
2. KiCad DRC with zone refill in memory and schematic/PCB parity checking.
3. A release gate that rejects ERC/DRC errors, every schematic-parity mismatch,
   a dirty source tree, and the explicit placement-draft marker.
4. Master and JLCPCB BOMs, JLCPCB-format CPL, manual-assembly list and a separate
   procurement-gap report.
5. Four copper Gerbers, masks, paste, silkscreen and `Edge.Cuts`; separate PTH/
   NPTH Excellon drills and a drill map.
6. IPC-D-356 netlist, board statistics, source snapshots, SHA-256 manifest and a
   release ZIP plus its checksum.

Warnings remain visible in the JSON reports but do not automatically disappear
or become approvals. Review every warning before ordering. PCB/schematic parity
is deliberately stricter: any mismatch blocks the archive even if KiCad labels
it a warning.

## DNP and assembly data

The exporter builds one effective do-not-populate list from every truthy `DNP`
field in the raw KiCad schematic BOM plus a safety-default list. Truthy values
include `true`, `yes`, `1`, `dnp` and `x`. It enforces the resulting list
independently of PCB-footprint DNP flags, so a missing board flag cannot put an
optional part back into either the JLC BOM or CPL.

The safety defaults are:

- `C109`: optional VSYS bulk capacitor; populate only after a stability and
  transient test shows it is required and safe.
- `C310`, `C311`, `C312`: NFC matching options; leave open until the real PCB
  antenna has been measured and matching values have been selected.
- `C403`, `C404`: Sub-GHz pi-match shunt options; leave open until the assembled
  RF path and spring antenna have been measured.
- `C507`, `C508`, `C509`: LF resonance/RX trim options; leave open until the
  actual external coil has been measured and the receive path checked.

They are marked in `bom-master.csv` and removed from both `bom-jlcpcb.csv` and
`cpl-jlcpcb.csv`. Any additional schematic part carrying a truthy `DNP` field is
handled the same way. The effective list is recorded in `release-check.txt` and
`release-info.json`. The master BOM always contains the columns `Manufacturer`,
`MPN` and `LCSC`; empty fields are not silently invented. For an assembled order,
use `-RequireCompleteProcurement`; the command blocks while any CPL part lacks
one of those three identifiers.

`bom-jlcpcb.csv` contains only designators also present in the generated SMT
position file. Through-hole, mixed-pad and explicitly manual parts are listed in
`bom-manual-or-review.csv`. The file `hardware/assembly-variants.csv` is a design
planning aid, not yet a complete variant definition for every dependent passive.
Do not create a cost-down variant simply by deleting its main IC from the BOM.

JLCPCB rotations are not universal library data. Review **every** pin-1,
polarized, connector, LED, diode, QFN/LGA and module orientation in JLCPCB's 2D
assembly viewer against KiCad before accepting the order. The generated CPL is a
coordinate export, not that visual sign-off.

## Suggested JLCPCB prototype settings

These are ordering targets, not a substitute for matching the final KiCad board
stack-up and design rules:

| Setting | Prototype target |
| --- | --- |
| Base material | FR-4 |
| Layer count | 4 |
| Board thickness | 1.2 mm |
| Finished outline | 85.60 x 53.98 mm, including the specified corner radii |
| Copper weight | JLC04121H-7628 target: 1 oz outer, 0.5 oz inner |
| Surface finish | ENIG recommended for the fine-pitch/QFN/LGA prototype |
| Solder mask | Both sides; color is optional |
| Silkscreen | Both sides if present in the reviewed Gerbers |
| Via treatment | Tented by default; explicitly review RF, thermal and test vias |
| Impedance | Do not select a generic value blindly; use the chosen JLC 4-layer stack-up and recalculate RF traces |
| Assembly side | Two-sided PCBA required by the dense card layout; review both CPL sides and the added setup cost |
| Quantity | Five boards is a sensible first characterization batch |

Select the exact `JLC04121H-7628` structure in the quote, then compare
JLCPCB's live stack-up table with the board file before the
final RF routing. Enter its dielectric heights and copper thicknesses in KiCad,
then recalculate the 50-ohm Sub-GHz feed geometry. The
E07-900MM10S pin-6 antenna path uses a tuneable pi network and the inboard
T3-868M spring; both require measurement with the assembled mechanical stack.
If the final stack-up is
not represented in the board file, the fabrication ZIP must not be released.

Keep the credit-card outline free of factory tooling holes. If panel rails,
fiducials or tooling holes are needed, request them on removable rails and check
USB, optical and antenna edge clearances in the DFM viewer. Do not allow an
automatic outline change without comparing the returned production file.

## Mandatory prototype validation

Passing ERC/DRC only proves consistency against the encoded rules. It does not
prove electrical, RF, thermal or battery safety. Before a larger build:

- Power the first board from a current-limited supply without a LiPo. Validate
  shorts, USB inrush, charger/power-path behavior, 3.3 V stability, 5 V enable/
  disable and load transients. Fit `C109` only from measured evidence.
- Verify LiPo polarity, protection cutoffs, charge current, temperature behavior
  and no back-powering through USB, headers or peripherals before unattended
  charging.
- Characterize the NFC loop on the finished board with suitable RF/VNA or NFC
  measurement equipment. Select `C310`-`C312` and the main matching network from
  measurements, then re-run ERC/DRC and issue a new revision.
- Validate the Sub-GHz antenna/feed/connector with the enclosure and intended
  antenna. Regulatory limits, permitted bands and transmit power depend on the
  country and use case.
- Validate the external LF coil only after measuring its inductance and fitting
  reviewed values for `C506`-`C509`. Check HTRC phase, current, resonant voltage,
  ANTFAIL behavior and read range before extended operation.
- Inspect all fine-pitch and exposed-pad devices, then exercise USB, microSD,
  LF RFID, IR, NFC, sensors and every expansion voltage under load.

Only after those results are recorded should the project lose its
`prototype_only` status. The exporter intentionally writes
`production_approved: false` and `rf_and_nfc_tuning_required: true` into every
release metadata file; a ZIP by itself is never approval to mass-produce.

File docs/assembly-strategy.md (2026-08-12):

# Assembly and footprint strategy

V1 is a hybrid build. JLCPCB places the small or thermally critical SMT parts;
the owner installs the mechanically large or configurable parts after delivery.
The goal is easy repair and experimentation without compromising power, RF or
LiPo safety.

## Footprint rules

- Default resistors and capacitors: 0805, non-polar where possible.
- RF/NFC matching and dense low-power GPIO/data protection only: 0603. No
  0402 or 0201 parts in V1.
- No BGA or WLCSP packages.
- QFN, DFN, LGA, SOT-563 and microSD are always
  factory assembled.
- Prefer SOIC, TSSOP, SOT-23 and castellated modules for all replaceable parts.
- The current dense placement is deliberately two-sided. Keep hand-reworkable
  parts accessible and verify bottom-side height, reflow and PCBA cost during
  DFM; do not infer side assignment from this document before placement lock.
- Keep ordinary component bodies at least 2.5 mm from the final board edge.
  Edge connectors need process rails and explicit assembler DFM approval.
- Provide 1.0 mm finished holes for the 2.54 mm Dupont-compatible header.
- Use enlarged 0805 hand pads where the layout permits; keep RF reference pads
  compliant with the component datasheet.

## Assembly classes

| Class | Parts | Who installs them |
|---|---|---|
| `JLC_ONLY` | PN532, charger, DC/DCs, fuel gauge and microSD | JLCPCB |
| `JLC_SMT` | IR receiver/driver, USB-C, battery connector and small level shifters | JLCPCB preferred, side set by final placement |
| `JLC_OR_HAND` | ESP32 module, HTRC110, ATECC608C, TSSOP expanders and SOIC RTC | JLCPCB or careful hand rework |
| `HAND_OR_JLC_SOURCE` | Ebyte Sub-GHz module | Hand install by default |
| `HAND_THT` | 2.54 mm headers and 5 mm IR LED | Owner after delivery |
| `JLC_STANDARD_OPTION` | BMI270 and BMP390 | JLCPCB FULL variant only |

`CORE-ECO` omits U10/U11; `FULL` populates them. Because current placement uses
both PCB sides, neither variant is assumed to qualify for a top-only Economic
PCBA service. Their empty sensor footprints do not make the core board unusable:
LF RFID, NFC, Sub-GHz, IR and microSD remain available.

## Orientation safeguards

- Pin 1 receives both a large silkscreen dot and a copper/fabrication marker.
- Diodes, LEDs, polarized capacitors and battery pins receive `+`, `-`, `A` and
  `K` labels as appropriate; never rely on a footprint outline alone.
- Module outlines include the antenna/keep-out end and the readable part name.
- J3 is labeled `LF COIL`. U3 pin 6 reaches the lower-edge spring through the
  pi network; the adjacent right-hand pad labeled `868 ANT`
  is the spring's only electrical connection. After soldering and inspection,
  bond the free left end to the upper FR4 pocket wall with a small
  nonconductive epoxy or neutral-cure silicone bridge. Do not solder, ground,
  or add copper at that second mechanical anchor. Perform the final RF tuning
  only after the adhesive has cured and with the enclosure and battery fitted.
- The battery connector is labeled from the wire side as well as the PCB side.
- JLCPCB CPL rotations must be checked visually in its 2D assembly viewer.

## Ordering workflow

1. Recheck every JLC/LCSC part number and stock immediately before ordering.
2. Generate Gerber/drill, BOM and CPL from the tagged KiCad release.
3. Add break-off process rails so tooling holes/fiducials are not drilled into
   the finished card outline.
4. Review both-side BOM/CPL placement in the assembler viewer, then order five
   boards with all `HAND_*` parts DNP.
5. Inspect USB power, 3.3 V, charger and shorts before connecting a LiPo.
6. Install headers and IR LED only after the assembled board passes bring-up.

JLCPCB's library status and assembly class can change. Supplier identifiers in
the preliminary BOM are selection aids, not permission to skip the final BOM
and footprint audit.

Useful current supplier rules:

- [JLCPCB assembly capabilities](https://jlcpcb.com/capabilities/pcb-assembly-capabilities)
- [JLCPCB assembly terms and 2.5 mm edge rule](https://jlcpcb.com/help/article/terms-and-conditions-of-jlcpcb-assembly-service)
- [JLCPCB tooling-hole guidance](https://jlcpcb.com/help/article/how-to-add-tooling-holes-for-pcb-assembly-order)

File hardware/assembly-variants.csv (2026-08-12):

Variant | U1_ESP32 | U2_PN532 | U3_SUBGHZ | U4_LF_RFID | U23_SECURE | U8_FUEL | U10_IMU | U11_BARO | U12_RTC | D1_D3_IR | J3_LF_COIL | J5_EXT | C109 | C310_C312 | C507_C509 | PCBA
FULL-PROTOTYPE | Fit | Fit | Fit | Fit | Fit_unprovisioned | Fit | Fit | Fit | Fit | Hand_after | Hand_after_tuning | Hand_after | DNP | DNP | DNP | Two_sided_standard_review
CORE-NOSENSORS | Fit | Fit | Fit | Fit | Fit_unprovisioned | Fit | DNP | DNP | Fit | Hand_after | Hand_after_tuning | Hand_after | DNP | DNP | DNP | Two_sided_standard_review
CORE-NORADIO | Fit | Fit | DNP | Fit | Fit_unprovisioned | Fit | DNP | DNP | Fit | Hand_after | Hand_after_tuning | Hand_after | DNP | DNP | DNP | Two_sided_standard_review

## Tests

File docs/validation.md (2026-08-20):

# Design validation log

## Architecture checks

- ESP32-S3-WROOM-1-N8R2; no duplicate dedicated GPIO allocations.
- Eleven direct J5 GPIOs remain: 1, 2, 4, 8, 40, 41, 42, 43, 44, 47, 48.
- GPIO9 is reserved for the internal board NTC; J5 pin 7 is a protected
  high-impedance measurement point, not a general-purpose output.
- GPIO38 is dedicated to active-low PAIR. U9 adds eight low-speed EX inputs;
  U18 controls charger, AUX 5 V, NFC reset, LF 5 V and the 5-V boost.
- J5 contains 30 plated positions at 2.54-mm pitch.
- LF serial logic is translated in both directions; HTRC110 and its clock use
  switched 5 V, while the ESP32 and ATECC608C remain on 3.3 V.
- ATECC608C is present in SOIC-8 but intentionally unprovisioned.

## 2026-08-17 generated design

- KiCad 10 schematic: 274 symbols, 267 footprints, 181 logical/231 PCB nets.
- ERC: 0 errors, 0 warnings.
- Placement builder: 131 front and 136 back footprints; scripted courtyard, board,
  NFC, ESP and spring-pocket keepout audit passes.
- The authoritative routed checkpoint contains 130 front and 137 back
  footprints. Its one-part-per-side difference from the regenerated donor is
  limited to a generic unrouted packing slot; all 267 references remain present.
- Inner-plane staging regenerates with L2 GND and L3 +3V3 plus switcher cutouts.
- Stack-up audit: nominal 1.2-mm `JLC04121H-7628`, four copper layers,
  0.665-mm core, two 0.2104-mm 7628 prepregs and ENIG are serialized in the
  template and authoritative main board. The placement builder repeats this
  audit whenever the untracked staging boards are regenerated.
- Routing checkpoint: guarded digital fanout plus DRC-clean U6_L1, U6_L2,
  U7_SW, RTC_OSCI/RTC_OSCO, U6/U7 local power and U7 feedback routes. The two
  U7 power-pin neckdowns and the 5-V Kelvin branch are confined by named rule
  areas. R405 orientation was corrected before RF routing. The provisional
  Sub-GHz feed is now retained DRC-clean: C404 is perpendicular to the line,
  the module-side section stays on B.Cu, and one 0.60/0.30-mm via moves the
  antenna-side section to F.Cu outside the spring-notch edge clearance.
- The HTRC110 analog island is now coherent on B.Cu. All nine sensitive LF
  nets (`LF_TX1`, `LF_TX2`, `LF_ANT_A`, `LF_ANT_B`, `LF_TAP`, `LF_RX`,
  `LF_CEXT`, `LF_QGND`, `LF_CLK_4M`) are completely routed without a via.
  The straight C506/C507/C508 tuning bank preserves two DNP tuning sites.
- U17 and the LF support parts form a separate front-side island. The local
  `LF_5V` route to U4, Y501 and C513 uses three standard tented vias and a
  named, package-local 0.20-mm SOT-23 escape rule. A generator-owned reserve
  protects this routing corridor during future placement regeneration.
- PN532 pins U2.5/U2.8 now share a short via-free F.Cu DVDD escape. The U2.3
  GND branch terminates directly in the exposed pad, while the retained
  0.45/0.20-mm west GND via keeps U2.3/U2.7/U2.41 tied to the solid plane.
- R201/R202 were moved to a validated vertical side-by-side placement. Native
  D+/D- is complete from the ESP32 through the two series resistors and U16 to
  all four J1 data pads. The MCU side has no vias. A staggered five-via J1
  bridge passes pad, hole, copper and filled-plane DRC; its 0.15-mm clearance
  rule is limited to the fine-pitch connector bridge area.
- U16 is 0.55 mm farther inboard. R102 is fixed as a front-side 0805; its J1-B5
  pull-down path, ground return and U16 pin-6 protection branch are complete.
  CC2 uses two standard 0.50/0.30-mm through vias, outer-layer tracks only and
  a local 0.20-mm clearance rule limited to its C103/C104 centre-gap escape.
  R101 is fixed on B.
- VSYS is complete between U5, both converters and the local bulk capacitors.
  R129 is a hand-friendly 0805 zero-ohm series crossover that keeps SPI_MOSI
  on outer copper while VSYS passes through the constrained charger corridor.
  The two J1 VBUS contacts now join F1 using 0.30-mm front escapes around the
  connector holes, two 0.70/0.35-mm vias and a short reviewed 0.20-mm B.Cu
  shield-corridor neck that widens immediately to 0.50/0.60 mm.
- Three compact KMR221GLFS switches now provide UP/OK/DOWN. SELECT uses
  U9/P07 with R607; BMP390 pin 7 is NC and the sensor remains usable by I2C.
  RESET, BOOT and PAIR retain their dedicated functions.
- Conflicting SPI_SCK/SPI_MOSI/SPI_MISO, I2C_SCL, GPIO44_MCU, NFC_DVDD,
  user-button, IR_LED_A1, IR_LED_K, GPIO43, NFC_LOADMOD, NFC_RESET_N,
  I2C_SDA, PAIR_N, SPI_MOSI_HDR, SPI_SCK_HDR, LF_DOUT_5V and OLED_VCC autorouter copper
  was removed as complete nets, avoiding dangling stubs while those nets wait
  for reviewed routes around USB, the new button strip and the LF island.
- `+5V_RAW` and `+5V_AUX` are fully connected through two narrow L3
  distribution corridors while L2 remains the continuous GND plane. The 36
  requested GND/+3V3 clusters and the reviewed U2.3 GND escape are complete.
- The U8/U11 sensor corridor now carries I2C_SCL from U1.6 to U8.7 through a
  short L3 crossing and I2C_SDA from U8.8 to U11.4 directly on B.Cu. The
  displaced `FG_ALERT_N` and `SPI_MOSI` paths and both local U11 ground
  branches were restored and explicitly connectivity-checked; L2 still has
  no non-GND signal tracks.
- The J5 protection checkpoint connects J5.25 to the complete U25/R732
  `SPI_SCK_HDR` tree and J5.23 to U24.1 on `I2C_SDA_HDR`; the separate R730 SDA
  clamp branch remains open. The two reviewed low-speed L3 crossings preserve
  the ground-only L2 plane. One added `+5V_RAW` stitch via restores the power
  polygon across the SCK clearance slot, and explicit endpoint checks pass for
  both header routes and the two locally rehomed fanouts.
- The PN532 `/NFC_TX2_F` branch now connects L302.2 to C309.1 with five locked
  0.15-mm F.Cu segments, no via and the full reviewed 0.25-mm local clearance.
- The microSD `/SD_CS_DEV` branch now connects U19.1 to J2.2 through one local
  0.45/0.20-mm via. U19.2 retains a complete GND connection through its
  existing plane via after the front escape was shifted toward the card edge.
- The ESP32 `/SPI_MOSI` branch now joins U1.19 to the routed U21/R129 bus group
  with eight locked 0.15-mm outer-layer segments and one 0.45/0.20-mm via.
- The microSD resistor-side `/SPI_MOSI` branch now joins R511.1 to that bus
  group through six locked 0.15-mm L3 segments, one short F.Cu escape and one
  0.45/0.20-mm via. L2 remains ground-only and all critical power groups remain
  connected after the L3 plane refill.
- The USB-C `/USB_CC1` path now joins J1.A5 to 5.1-kohm pull-down R101.1 with
  ten locked outer-layer segments and one 0.45/0.20-mm via. Nine additional
  locked 0.20-mm F.Cu segments join U16.4 to J1.A5 without another via, so all
  three CC1 pads form one connected group.
- The UP-button `/USER_BUTTON_A_N` path now joins SW3.1 to pull-up R608.1
  with ten locked 0.15-mm segments and two 0.45/0.20-mm vias. Its short L3
  crossing clears the dense LF/RGB fanouts; U18.11 remains the second group.
- The back-side `/CELL_POS` monitor branch now joins U8.3 to C120.1 with four
  locked 0.15-mm B.Cu segments and no via.
- The protected `/GPIO43` output R718.2 now reaches expansion-header pad J5.11
  through three locked 0.15-mm L3 segments and one 0.45/0.20-mm tented via.
- The protected `/SPI_MISO_HDR` branch now joins R734.2 to J5 ESD-array pad
  U25.1 with eleven locked 0.15-mm segments, two 0.45/0.20-mm tented vias and
  a reviewed L3 corridor. L2 remains ground-only.
- The PN532 `/NFC_TX1` driver output U2.4 now joins matching inductor L301.1
  through two F.Cu escapes, three locked 0.20-mm L3 segments and two ordinary
  0.45/0.20-mm vias. Reviewed local LF clock/data jogs free the via corridor
  without changing either neighboring net's connectivity; L2 remains GND-only.
- The OLED `/OLED_VCC` supply now joins C615/C616 to J8.16 through one
  0.45/0.20-mm via and a short reviewed L3 crossing. `/OLED_C1P` remains
  connected at the 0.15-mm project minimum, and the local `+5V_AUX` L3 bridge
  retains a single five-pad power group.
- The board currently contains 1881 track segments, 342 vias and 23 zones.
- J2 is 0.175 mm farther inboard than the prior checkpoint. Its signal and
  shell pads now meet the configured 0.50-mm board-edge clearance without
  reducing the adjacent B.Cu ground-track clearance below 0.20 mm.
- DRC: 16 documented non-release findings remain, with no track-width, via,
  drill, short, dangling-track or new routing-clearance finding. Schematic
  parity and ERC are clean; 142 unconnected items remain. GND, +3V3,
  +5V_RAW and +5V_AUX are fully connected.
- The PCB is therefore not order-ready.

## Firmware checkpoint

The three-button PCB change is intentionally hardware-only for now; the
firmware below is the preceding two-button checkpoint and has not been changed.

- PlatformIO/Arduino-ESP32 3.3.8 build succeeds for ESP32-S3 N8R2.
- RAM: 49,568 / 327,680 bytes; application flash: 1,113,399 / 3,342,336 bytes.
- LF power sequencing, HTRC configuration/phase/ANTFAIL diagnosis, ATECC wake
  probe, physical pairing window, web UI, microSD, bounded NEC IR and the
  board-temperature safety policy compile.
- Tag decoding, app authentication, ATECC provisioning and owner recovery are
  not implemented or claimed.

## Outstanding before an order

1. Route the remaining 142 signal connection items, especially the PN532
   supply/matching network and the dense MCU, sensor and microSD corridors.
   Refill planes after each batch and close DRC with no unexplained item.
2. Independently review every footprint, polarity and custom land pattern.
3. Recheck live JLC/LCSC stock, assembly side/class, BOM and CPL rotations.
4. Measure/tune the NFC loop and Sub-GHz network on assembled prototypes.
5. Measure the actual LF coil and select resonance values from phase, current,
   voltage, temperature and range data.
6. Current-limit first power-up and verify charger, protection and all rails
   before connecting an unprotected cell or external equipment.
7. Define and review the phone-app key protocol, reset/recovery flow and ATECC
   slot/lock manifest before irreversible provisioning.

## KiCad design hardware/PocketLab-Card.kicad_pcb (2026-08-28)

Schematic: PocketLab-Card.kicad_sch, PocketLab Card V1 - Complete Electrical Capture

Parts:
A1: T3-868M SPRING ANTENNA; T3-868M_Edge_Solder; MPN T3-868M; LCSC C381193
AE1: PCB NFC LOOP - TUNE ON V1; NFC_Loop_35x27mm_4T_TUNE
C101: 4.7nF 1kV; C_0805_2012Metric; MPN C0805C472KDRAC7800; LCSC C5565742
C102, C106, C107, C118, C120, C121, C122, C203, C301, C304, C305, C401, C510, C601, C603, C604, C605, C606, C701, C702, C703, C704, C705, C706, C707: 100nF; C_0402_1005Metric; MPN CL05B104KO5NNNC; LCSC C1525
C103, C105: 4.7uF 10V; C_0603_1608Metric; MPN CL10A475KO8NNNC; LCSC C19666
C104: 22uF 10V; C_0805_2012Metric; MPN TCC0805X5R226K100FT; LCSC C380336
C108, C114, C117, C119: 10uF; C_0805_2012Metric; MPN CL21A106KAYNNNE; LCSC C15850
C109: 10uF DNP - populate only after VSYS stability test; C_0805_2012Metric; MPN CL21A106KAYNNNE; LCSC C15850; not fitted
C110, C111, C112, C115, C116: 22uF; C_0805_2012Metric; MPN TCC0805X5R226K100FT; LCSC C380336
C113, C308, C309: 220pF C0G; C_0603_1608Metric; MPN CL10C221JB8NNNC; LCSC C27675
C123, C124: 10uF 25V X5R HF; C_0805_2012Metric; MPN CL21A106KAYNNNE; LCSC C15850
C201: 1uF; C_0402_1005Metric; MPN CL05A105KA5NQNC; LCSC C52923
C202, C511: 10uF; C_0603_1608Metric; MPN CL10A106KP8NNNC; LCSC C19702
C302: 100nF AVDD; C_0402_1005Metric; MPN CL05B104KO5NNNC; LCSC C1525
C303: 4.7uF VBAT bulk; C_0603_1608Metric; MPN CL10A475KO8NNNC; LCSC C19666
C306, C307: 22pF C0G; C_0603_1608Metric; MPN CL10C220JB8NNNC; LCSC C1653
C310, C311, C312: DNP MATCH; C_0603_1608Metric; not fitted
C313: 10uF DVDD bulk; C_0603_1608Metric; MPN CL10A106KP8NNNC; LCSC C19702
C314: 100nF TVDD; C_0402_1005Metric; MPN CL05B104KO5NNNC; LCSC C1525
C315: 4.7uF TVDD bulk; C_0603_1608Metric; MPN CL10A475KO8NNNC; LCSC C19666
C316: 100nF PVDD; C_0402_1005Metric; MPN CL05B104KO5NNNC; LCSC C1525
C317: 100nF VBAT; C_0402_1005Metric; MPN CL05B104KO5NNNC; LCSC C1525
C318: 1nF C0G RX COUPLING; C_0603_1608Metric; MPN CL10C102JB8NNNC; LCSC C163508
C402, C602: 4.7uF; C_0603_1608Metric; MPN CL10A475KO8NNNC; LCSC C19666
C403, C404: DNP SUBGHZ MATCH; C_0603_1608Metric; not fitted
C501: 100nF HTRC supply; C_0402_1005Metric; MPN CL05B104KO5NNNC; LCSC C1525
C502: 10uF HTRC pulse reservoir; C_0805_2012Metric; MPN CL21A106KAYNNNE; LCSC C15850
C503: 100nF CEXT; C_0402_1005Metric; MPN CL05B104KO5NNNC; LCSC C1525
C504: 100nF QGND; C_0402_1005Metric; MPN CL05B104KO5NNNC; LCSC C1525
C505: 100nF C0G COIL ISOLATION; C_1206_3216Metric; MPN 1206CG104J500NT; LCSC C46348
C506: 3.9nF C0G LF RESONANCE; C_0805_2012Metric; MPN CL21C392JBFNNNE; LCSC C307553
C507: 100pF C0G DNP LF TUNE; C_0603_1608Metric; MPN CL10C101JB8NNNC; LCSC C14858; not fitted
C508: 220pF C0G DNP LF TUNE; C_0603_1608Metric; MPN CL10C221JB8NNNC; LCSC C27675; not fitted
C509: 10pF C0G DNP RX EMI; C_0603_1608Metric; MPN CL10C100JB8NNNC; LCSC C1634; not fitted
C512: 47uF 6.3V LOW-ESR; C_1206_3216Metric; MPN CC1206MKX5R5BB476; LCSC C110047
C513: 100nF OSC supply; C_0402_1005Metric; MPN CL05B104KO5NNNC; LCSC C1525
C515: 100nF LV-AT supply; C_0402_1005Metric; MPN CL05B104KO5NNNC; LCSC C1525
C516: 100nF LVC supply; C_0402_1005Metric; MPN CL05B104KO5NNNC; LCSC C1525
C517: 100nF secure element; C_0402_1005Metric; MPN CL05B104KO5NNNC; LCSC C1525
C607, C617: 22uF 10V X5R IR BUFFER; C_1206_3216Metric; MPN TCC1206X5R226K100HT; LCSC C7393980
C608: 100nF IR HF; C_0402_1005Metric; MPN CL05B104KO5NNNC; LCSC C1525
C609: 100nF X7R; C_0402_1005Metric; MPN CL05B104KO5NNNC; LCSC C1525
D1, D2, D3: VSMY14940 940nm side-view; LED_Vishay_VSMY14940_SideView; MPN VSMY14940; LCSC C511069
D101: SMF5.0A; D_SOD-123F; MPN SMF5.0A; LCSC C151296
F1: Littelfuse 1206L075/13.2; Fuse_1206_3216Metric; MPN 1206L075/13.2WR; LCSC C207036
J1: USB-C DATA/POWER; USB_C_Receptacle_HRO_TYPE-C-31-M-12; MPN TYPE-C-31-M-12; LCSC C165948
J2: microSD; microSD_HC_Molex_104031-0811; MPN 104031-0811; LCSC C585350
J3: EXTERNAL 400uH LF COIL; PinHeader_1x02_P2.54mm_Vertical
J4: PROTECTED 1S LiPo 3.7V; JST_PH_S2B-PH-SM4-TB_1x02-1MP_P2.00mm_Horizontal; MPN S2B-PH-SM4-TB(LF)(SN); LCSC C295747
J5: 30-PIN 2.54mm DUPONT GRID; Dupont_Grid_6x5_P2.54mm
L6: 1.5uH 5.2A SMHT4020; ShunXiangNuo_SMHT4020; MPN SMHT4020-1R5MT; LCSC C46469583
L7: 1uH 4.15A SLW4030S; Sunltech_SLW4030S; MPN SLW4030S1R0NST; LCSC C206354
L301, L302: 560nH C0G/Q; L_0805_2012Metric; MPN FHW0805UFR56JST; LCSC C304279
LED1, LED2, LED3, LED4: WS2812B-2020; LED_WS2812B-2020_PLCC4_2.0x2.0mm; MPN WS2812B-2020; LCSC C965555
Q1: AO3400A IR DRIVER; SOT-23; MPN AO3400A; LCSC C20917
Q2: CSD16406Q3 DISCHARGE; CSD16406Q3_VSON-8_3.3x3.3mm_P0.65mm_JLC; MPN CSD16406Q3; LCSC C2861720
Q3: CSD16406Q3 CHARGE; CSD16406Q3_VSON-8_3.3x3.3mm_P0.65mm_JLC; MPN CSD16406Q3; LCSC C2861720
R101, R102: 5.1k 1%; R_0402_1005Metric; MPN 0402WGF5101TCE; LCSC C25905
R103: 1M; R_0402_1005Metric; MPN 0402WGF1004TCE; LCSC C26083
R104: 330R; R_0402_1005Metric; MPN 0402WGF3300TCE; LCSC C25104
R105: 2.2k; R_0805_2012Metric; MPN 0805W8F2201T5E; LCSC C17520
R106, R107: 5.1M; R_0402_1005Metric; MPN 0402WGF5104TCE; LCSC C270595
R108: 10k TS fixed; R_0805_2012Metric; MPN 0805W8F1002T5E; LCSC C17414
R109, R110, R115, R122, R124, R126, R127, R128, R603: 100k; R_0402_1005Metric; MPN 0402WGF1003TCE; LCSC C25741
R111: 3.48k 1%; R_0402_1005Metric; MPN 0402WGF3481TCE; LCSC C22065
R112: 3.01k 1%; R_0402_1005Metric; MPN 0402WGF3011TCE; LCSC C25889
R113: 1.78k 1%; R_0402_1005Metric; MPN 0402WGF1781TCE; LCSC C113478
R114: 68.1k 1%; R_0402_1005Metric; MPN 0402WGF6812TCE; LCSC C11537
R116, R125, R203, R204, R301, R519, R607, R608, R609, R703: 10k; R_0402_1005Metric; MPN 0402WGF1002TCE; LCSC C25744
R117: 470k 1%; R_0402_1005Metric; MPN 0402WGF4703TCE; LCSC C25790
R118: 150k 1%; R_0402_1005Metric; MPN 0402WGF1503TCE; LCSC C25755
R119: 10k; R_0805_2012Metric; MPN 0805W8F1002T5E; LCSC C17414
R120: 732k 1%; R_0402_1005Metric; MPN 0402WGF7323TCE; LCSC C27016
R121: 100k 1%; R_0402_1005Metric; MPN 0402WGF1003TCE; LCSC C25741
R123: 60.4k 1%; R_0402_1005Metric; MPN 0402WGF6042TCE; LCSC C25911
R129: 0R SPI CROSSOVER; R_0805_2012Metric; MPN 0805W8F0000T5E; LCSC C17477
R201, R202: 22R; R_0805_2012Metric; MPN 0805W8F220JT5E; LCSC C17561
R302: 10k RESET default asserted; R_0402_1005Metric; MPN 0402WGF1002TCE; LCSC C25744
R303, R304: 0R MATCH; R_0603_1608Metric; MPN 0603WAF0000T5E; LCSC C21189
R305: 2.7k RX TAP; R_0603_1608Metric; MPN 0603WAF2701T5E; LCSC C13167
R306: 1k VMID BIAS; R_0603_1608Metric; MPN 0603WAF1001T5E; LCSC C21190
R401, R402, R403, R404, R510, R511, R512, R513: 22R; R_0402_1005Metric; MPN 0402WGF220JTCE; LCSC C25092
R405: 0R SUBGHZ MATCH; R_0603_1608Metric; MPN 0603WAF0000T5E; LCSC C21189
R406: 100k CS SAFE-HIGH; R_0402_1005Metric; MPN 0402WGF1003TCE; LCSC C25741
R501: 100R QOD discharge; R_0402_1005Metric; MPN 0402WGF1000TCE; LCSC C25076
R502: 47R 0.5W ANTENNA CURRENT LIMIT; R_1210_3225Metric; MPN 1210W2F470JT5E; LCSC C474213
R503: 1k LF EMI RETURN; R_0402_1005Metric; MPN 0402WGF1001TCE; LCSC C11702
R504: 150k 1% RX DIVIDER; R_0402_1005Metric; MPN 0402WGF1503TCE; LCSC C25755
R506: 100k SAFE-OFF; R_0402_1005Metric; MPN 0402WGF1003TCE; LCSC C25741
R509: 10k PAIR pull-up; R_0402_1005Metric; MPN 0402WGF1002TCE; LCSC C25744
R514, R515, R516, R517, R518: 47k; R_0402_1005Metric; MPN 0402WGF4702TCE; LCSC C25792
R601, R610, R611: 68R 0.25W anti-surge; R_0603_1608Metric; MPN AS03W4J0680T5E; LCSC C966162
R602, R604, R710, R711, R712, R713, R715, R716, R717, R718, R719, R720, R721, R730, R731, R732, R733, R734: 100R; R_0402_1005Metric; MPN 0402WGF1000TCE; LCSC C25076
R605: 68R; R_0402_1005Metric; MPN 0402WGF680JTCE; LCSC C25131
R606: 100R PAIR GPIO PROTECTION; R_0402_1005Metric; MPN 0402WGF1000TCE; LCSC C25076
R701: 3.3k; R_0805_2012Metric; MPN 0805W8F3301T5E; LCSC C26010
R702: 3.3k; R_0402_1005Metric; MPN 0402WGF3301TCE; LCSC C25890
R714: 100R BOARD TEMP PROBE; R_0402_1005Metric; MPN 0402WGF1000TCE; LCSC C25076
R722, R723, R724, R725, R726, R727, R728, R729: 220R EXPANSION PROTECTION; R_0402_1005Metric; MPN 0402WGF2200TCE; LCSC C25091
R735: 100k EN pull-down; R_0805_2012Metric; MPN 0805W8F1003T5E; LCSC C149504
R736: 10k 1% BOARD TEMP BIAS; R_0402_1005Metric; MPN 0402WGF1002TCE; LCSC C25744
RT701: 10k NTC B3950 1%; R_0603_1608Metric; MPN KNTC0603/10KF3950; LCSC C2892547
SJ1: TS FIXED / CUT FOR EXT NTC; SolderJumper-2_P1.3mm_Bridged_RoundedPad1.0x1.5mm
SW1: RESET; SW_HYP_1TS015A_3.0x2.0mm; MPN 1TS015A-1600-0600-CT; LCSC C256104
SW2: BOOT; SW_HYP_1TS015A_3.0x2.0mm; MPN 1TS015A-1600-0600-CT; LCSC C256104
SW3: UP; SW_HYP_1TS015A_3.0x2.0mm; MPN 1TS015A-1600-0600-CT; LCSC C256104
SW4: DOWN; SW_HYP_1TS015A_3.0x2.0mm; MPN 1TS015A-1600-0600-CT; LCSC C256104
SW5: MAIN POWER OFF / ON; SW_SPDT_Shouhan_MSK12C02; MPN MSK12C02; LCSC C431540
SW6: PAIR; SW_HYP_1TS015A_3.0x2.0mm; MPN 1TS015A-1600-0600-CT; LCSC C256104
SW7: SELECT; SW_HYP_1TS015A_3.0x2.0mm; MPN 1TS015A-1600-0600-CT; LCSC C256104
SW8: AUX CONFIG; SW_SPST_CK_KXT3; MPN KXT311LHS
TP101: BATTERY CELL_POS; TestPoint_Pad_D1.0mm
TP102: BATTERY CELL_NEG; TestPoint_Pad_D1.0mm
TP103: BATTERY BAT_FET_MID; TestPoint_Pad_D1.0mm
TP104: BATTERY GND; TestPoint_Pad_D1.0mm
TP105: POWER VBUS_USB; TestPoint_Pad_D1.0mm
TP106: POWER VBUS_FUSED; TestPoint_Pad_D1.0mm
TP107: POWER VSYS; TestPoint_Pad_D1.0mm
TP108: POWER +3V3; TestPoint_Pad_D1.0mm
TP109: POWER +5V_RAW; TestPoint_Pad_D1.0mm
TP110: POWER +5V_AUX; TestPoint_Pad_D1.0mm
TP201: JTAG_STRAP_TP; TestPoint_Pad_D1.0mm
TP202: STRAP_BOOT_TP; TestPoint_Pad_D1.0mm
TP203: STRAP_VDD_SPI_TP; TestPoint_Pad_D1.0mm
TP301: NFC_LOADMOD TEST; TestPoint_Pad_D1.0mm
TP502: LF ANTENNA TAP - HIGH VOLTAGE; TestPoint_Pad_D1.0mm
U1: ESP32-S3-WROOM-1-N8R2; ESP32-S3-WROOM-1_PhysicalCourtyard; MPN ESP32-S3-WROOM-1-N8R2; LCSC C2913204
U2: PN5321A3HN/C106; HVQFN-40-1EP_6x6mm_P0.5mm_EP4.1x4.1mm; MPN PN5321A3HN/C106; LCSC C880904
U3: E07-900MM10S 855-925MHz; E07-900MM10S; MPN E07-900MM10S; LCSC C5844212
U4: HTRC11001T/03EE,11 125kHz; SO-14_3.9x8.65mm_P1.27mm; MPN HTRC11001T/03EE,11; LCSC C501317
U5: BQ24074RGTR; VQFN-16-1EP_3x3mm_P0.5mm_EP1.6x1.6mm_ThermalVias; MPN BQ24074RGTR; LCSC C54313
U6: TPS63070RNMR 3V3; TPS63070_RNM0015A; MPN TPS63070RNMR; LCSC C109322
U7: TPS61023DRLR 5V BOOST; SOT-563; MPN TPS61023DRLR; LCSC C919459
U8: MAX17048G+T10; TDFN-8-1EP_2x2mm_P0.5mm_EP0.8x1.2mm; MPN MAX17048G+T10; LCSC C2682616
U9: TCA9535PWR; TSSOP-24_4.4x7.8mm_P0.65mm; MPN TCA9535PWR; LCSC C130204
U10: BMI270 (FULL OPTION); Bosch_LGA-14_3x2.5mm_P0.5mm; MPN BMI270; LCSC C2836813
U11: BMP390 (FULL OPTION); BMP390_LGA-10_2x2mm; MPN BMP390; LCSC C5124834
U12: PCF8563T; SOIC-8_3.9x4.9mm_P1.27mm; MPN PCF8563T/5,518; LCSC C7440
U13: TSOP75338WTR 38kHz; TSOP75338WTR_HeimdallW_SideView; MPN TSOP75338WTR; LCSC C7365598
U14: BQ29700DSE; WSON-6_1.5x1.5mm_P0.5mm; MPN BQ29700DSER; LCSC C183096
U15: TPS2553DBVR 500mA LIMIT; SOT-23-6; MPN TPS2553DBVR; LCSC C55266
U16: USBLC6-4SC6Y; SOT-23-6; MPN USBLC6-4SC6Y; LCSC C435848
U17: TPS22919DCKR LF 5V LOAD SWITCH; SOT-363_SC-70-6; MPN TPS22919DCKR; LCSC C2149796
U18: TCA9534PWR INTERNAL CONTROL; TSSOP-16_4.4x5mm_P0.65mm; MPN TCA9534PWR; LCSC C783615
U19: SRV05-4MR6T1G SD ESD; SOT-23-6; MPN SRV05-4MR6T1G; LCSC C604719
U20: SN74AHCT1G126DBVR RGB LEVEL SHIFT; SOT-23-5; MPN SN74AHCT1G126DBVR; LCSC C163712
U21: SN74LV125ATPWR LF/SPI 3V3-TO-5V IOFF; TSSOP-14_4.4x5mm_P0.65mm; MPN SN74LV125ATPWR; LCSC C2675655
U22: SN74LVC1G126DBVR LF 5V-TO-3V3 TRI-STATE; SOT-23-5; MPN SN74LVC1G126DBVR; LCSC C7834
U23: ATECC608C-SSHDA-T; SOIC-8_3.9x4.9mm_P1.27mm; MPN ATECC608C-SSHDA-T; LCSC C28975195
U24: SRV05-4MR6T1G J5 BUS ESD; SOT-23-6; MPN SRV05-4MR6T1G; LCSC C604719
U25: SRV05-4MR6T1G J5 SPI ESD; SOT-23-6; MPN SRV05-4MR6T1G; LCSC C604719
Y301: 27.12MHz crystal (pins 2/4 shield); Crystal_SMD_3225-4Pin_3.2x2.5mm; MPN XXDBBCNANF-27.12M; LCSC C124317
Y501: 4MHz 5V CMOS OSCILLATOR; Oscillator_SMD_EuroQuartz_XO32-4Pin_3.2x2.5mm_RotB; MPN OH2EL89CFI-111YLC-4M; LCSC C42448900
Y701: 32.768kHz CL=7pF; Crystal_SMD_3215-2Pin_3.2x1.5mm; MPN ABS07-32.768KHZ-7-T; LCSC C276424

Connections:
/+3V3: C110.1, C111.1, C112.1, C124.1, C202.1, C203.1, C303.1, C316.1, C317.1, C401.1, C402.1, C510.1, C511.1, C512.1, C516.1, C517.1, C701.1, C702.1, C703.1, C704.1, C705.1, C706.1, C707.1, J2.4 (VDD), J5.1, R109.2, R110.2, R117.1, R119.2, R124.2, R125.2, R203.2, R204.2, R406.2, R509.2, R514.2, R515.2, R516.2, R517.2, R518.2, R519.2, R604.1, R607.2, R608.2, R609.2, R701.2, R702.2, R703.2, R736.1, TP108.1, U1.2 (3V3), U2.23 (PVDD), U2.40 (VBAT), U3.1, U6.7, U6.8, U9.24 (VCC), U10.5, U10.8, U10.12, U11.1, U11.6, U11.10, U12.8 (VDD), U18.1 (A0), U18.16 (VDD), U19.5 (VP), U22.5 (VCC), U23.8 (VCC), U24.5 (VP), U25.5 (VP); also elsewhere on the board
/+5V_AUX: C118.1, C119.1, J5.29, TP110.1, U15.6
/+5V_RAW: C113.1, C115.1, C116.1, C117.1, C603.1, C604.1, C605.1, C606.1, C607.1, C608.1, C609.1, C617.1, LED1.1 (VDD), LED2.1 (VDD), LED3.1 (VDD), LED4.1 (VDD), R120.1, R601.1, R610.1, R611.1, TP109.1, U7.6, U15.1, U17.1, U20.5 (VCC)
/AUX5_EN: R127.1, U15.3, U18.6 (P2)
/AUX5_FAULT_N: R124.1, U9.7 (P03), U15.4
/BAT_COUT: Q3.4, R107.1, U14.2 (Cout)
/BAT_DOUT: Q2.4, R106.1, U14.3 (Dout)
/BAT_FET_MID: Q2.5, Q3.5, TP103.1
/BAT_SENSE: C102.1, R104.2, U14.5 (BAT)
/BAT_VMINUS: R105.1, U14.6 (V-)
/BMI_INT1: U9.9 (P05), U10.4
/BMI_INT2: U9.10 (P06), U10.9
/BOARD_TEMP_ADC: R714.1, R736.2, RT701.1, U1.17 (IO9)
/BOARD_TEMP_HDR: J5.7, R714.2
/BOOST5_EN: R122.1, U7.2, U18.10 (P5), U20.1
/BOOT_N: R204.1, SW2.1, U1.27 (IO0)
/BQ_EN1: R115.1, U5.6 (EN1), U18.4 (P0)
/BQ_EN2: R128.1, U5.5 (EN2)
/CELL_NEG: C102.2, J4.2, Q2.1, Q2.2, Q2.3, R106.2, TP102.1, U14.4 (VSS)
/CELL_POS: C104.1, C120.1, C121.1, J4.1, R104.1, TP101.1, U5.2 (BAT), U5.3 (BAT), U8.3
/CHARGER_CHG_N: R110.1, U5.9 (~CHG), U9.5 (P01)
/CHARGER_PGOOD_N: R109.1, U5.7 (~PGOOD), U9.6 (P02)
/CHG_DISABLE: R126.1, U5.4 (~CE), U18.5 (P1)
/CHG_ILIM: R111.1, U5.12 (ILIM)
/CHG_ISET: R113.1, U5.16 (ISET)
/CHG_ITERM: R112.1, U5.15 (ITERM)
/CHG_TMR: R114.1, U5.14 (TMR)
/CHG_TS: J5.28, SJ1.1 (A), U5.1 (TS)
/CHG_TS_FIXED: R108.1, SJ1.2 (B)
/ESP_EN: C201.1, R203.1, SW1.1, U1.3 (EN); also elsewhere on the board
/EX0: J5.15, R722.2
/EX0_INT: R722.1, U9.13 (P10)
/EX1: J5.16, R723.2
/EX1_INT: R723.1, U9.14 (P11)
/EX2: J5.17, R724.2
/EX2_INT: R724.1, U9.15 (P12)
/EX3: J5.18, R725.2
/EX3_INT: R725.1, U9.16 (P13)
/EX4: J5.19, R726.2
/EX4_INT: R726.1, U9.17 (P14)
/EX5: J5.20, R727.2
/EX5_INT: R727.1, U9.18 (P15)
/EX6: J5.21, R728.2
/EX6_INT: R728.1, U9.19 (P16)
/EX7: J5.22, R729.2
/EX7_INT: R729.1, U9.20 (P17)
/FG_ALERT_N: R125.1, U8.5, U9.8 (P04)
/GND: C101.2, C103.2, C104.2, C105.2, C106.2, C107.2, C108.2, C109.2, C110.2, C111.2, C112.2, C114.2, C115.2, C116.2, C117.2, C118.2, C119.2, C120.2, C121.2, C122.2, C123.2, C124.2, C201.2, C202.2, C203.2, C301.2, C302.2, C303.2, C304.2, C305.2, C306.2, C307.2, C308.2, C309.2, C311.2, C312.2, C313.2, C314.2, C315.2, C316.2, C317.2, C401.2, C402.2, C403.2, C404.2, C501.2, C502.2, C503.2, C504.2, C510.2, C511.2, C512.2, C513.2, C515.2, C516.2, C517.2, C601.2, C602.2, C603.2, C604.2, C605.2, C606.2, C607.2, C608.2, C609.2, C617.2, C701.2, C702.2, C703.2, C704.2, C705.2, C706.2, C707.2, D101.2 (A), J1.A1 (GND), J1.A12 (GND), J1.B1 (GND), J1.B12 (GND), J2.6 (VSS), J2.9 (DET_B), J2.SH (SHIELD), J5.2, J5.30, LED1.3 (VSS), LED2.3 (VSS), LED3.3 (VSS), LED4.3 (VSS), Q1.2 (S), Q3.1, Q3.2, Q3.3, R101.2, R102.2, R103.2, R105.2, R107.2, R108.2, R111.2, R112.2, R113.2, R114.2, R115.2, R118.2, R121.2, R122.2, R123.2, R126.2, R127.2, R128.2, R302.2, R503.2, R506.2, R603.2, R735.2, RT701.2, SW1.2, SW2.2, SW3.2, SW4.2, SW5.1 (A), SW6.2, SW7.2, SW8.2, TP104.1, U1.1 (GND), U1.40 (GND), U1.41 (GND), U2.1 (DVSS), U2.3 (TVSS1), U2.7 (TVSS2), U2.11 (AVSS), U2.17 (I1), U2.18 (TESTEN), U2.41 (AVSS), U3.2, U3.7, U3.16, U4.1 (VSS), U4.5 (MODE), U5.8 (VSS), U5.17 (VSS), U6.4, U6.10, U6.15, U7.4, U8.1, U8.4, U8.6, U8.9, U9.2 (A1), U9.3 (A2), U9.12 (GND), U9.21 (A0), U10.1, U10.6, U10.7, U11.3, U11.5, U11.8, U11.9, U12.4 (VSS), U13.1, U13.4, U15.2, U16.2 (GND), U17.2, U18.2 (A1), U18.3 (A2), U18.8 (GND), U19.2 (VN), U20.3 (GND), U21.1, U21.2, U21.4, U21.7, U21.9, U21.10, U21.13, U22.3 (GND), U23.4 (GND), U24.2 (VN), U25.2 (VN), Y301.2, Y301.4, Y501.2; also elsewhere on the board
/GPIO1: J5.3, R710.2
/GPIO1_MCU: R710.1, U1.39 (IO1)
/GPIO2: J5.4, R711.2
/GPIO2_MCU: R711.1, U1.38 (IO2)
/GPIO4: J5.5, R712.2
/GPIO4_MCU: R712.1, U1.4 (IO4)
/GPIO8: J5.6, R713.2
/GPIO8_MCU: R713.1, U1.12 (IO8)
/GPIO38_MCU: R606.1, U1.31 (IO38)
/GPIO40: J5.8, R715.2
/GPIO40_MCU: R715.1, U1.33 (IO40)
/GPIO41: J5.9, R716.2
/GPIO41_MCU: R716.1, U1.34 (IO41)
/GPIO42: J5.10, R717.2
/GPIO42_MCU: R717.1, U1.35 (IO42)
/GPIO43: J5.11, R718.2
/GPIO43_MCU: R718.1, U1.37 (TXD0)
/GPIO44: J5.12, R719.2
/GPIO44_MCU: R719.1, U1.36 (RXD0)
/GPIO47: J5.13, R720.2
/GPIO47_MCU: R720.1, U1.24 (IO47)
/GPIO48: J5.14, R721.2
/GPIO48_MCU: R721.1, U1.25 (IO48)
/I2C_SCL: R702.1, R731.1, U1.6 (IO6), U2.27 (NSS/P50_SCL/HSU_RX), U8.7, U9.22 (SCL), U10.13, U11.2, U12.6 (SCL), U18.14 (SCL), U23.6 (SCL); also elsewhere on the board
/I2C_SCL_HDR: J5.24, R731.2, U24.3 (IO2)
/I2C_SDA: R701.1, R730.1, U1.5 (IO5), U2.28 (MOSI/SDA/HSU_TX), U8.8, U9.23 (SDA), U10.14, U11.4, U12.5 (SDA), U18.15 (SDA), U23.5 (SDA); also elsewhere on the board
/I2C_SDA_HDR: J5.23, R730.2, U24.1 (IO1)
/IOEXP_INT_N: R703.1, U1.32 (IO39), U9.1 (~INT), U18.13 (~INT)
/IR_GATE: Q1.1 (G), R602.2, R603.1
/IR_LED_A1: D1.2 (A), R601.2
/IR_LED_A2: D2.2 (A), R610.2
/IR_LED_A3: D3.2 (A), R611.2
/IR_LED_K: D1.1 (K), D2.1 (K), D3.1 (K), Q1.3 (D)
/IR_RX: U1.30 (IO37), U13.3
/IR_RX_VS: C601.1, C602.1, R604.2, U13.2
/IR_TX: R602.1, U1.29 (IO36)
/JTAG_STRAP_TP: TP201.1, U1.15 (IO3)
/LF_5V: C501.1, C502.1, C513.1, C515.1, R501.2, U4.3 (VDD), U17.6, U21.14, Y501.1, Y501.4
/LF_ANT_A: C505.2, J3.1, R503.1
/LF_ANT_B: J3.2, R502.1
/LF_CEXT: C503.1, U4.12 (CEXT)
/LF_CLK_4M: U4.6 (XTAL1), Y501.3
/LF_DIN_5V: U4.9 (DIN), U21.11
/LF_DOUT_5V: U4.10 (DOUT), U22.2
/LF_QGND: C504.1, C509.2, U4.13 (QGND)
/LF_QOD: R501.1, U17.5
/LF_RFID_EN: R506.1, U17.3, U18.9 (P4), U22.1
/LF_RX: C509.1, R504.2, U4.14 (RX)
/LF_SCLK_5V: U4.8 (SCLK), U21.6
/LF_TAP: C506.1, C507.1, C508.1, R502.2, R504.1, TP502.1
/LF_TX1: C505.1, U4.4 (TX1)
/LF_TX2: C506.2, C507.2, C508.2, U4.2 (TX2)
/NFC_DVDD: C302.1, C304.1, C313.1, C314.1, C315.1, R301.2, U2.5 (TVDD), U2.8 (AVDD), U2.39 (DVDD)
/NFC_I0: R301.1, U2.16 (I0)
/NFC_IRQ_N: U1.7 (IO7), U2.25 (P70_IRQ)
/NFC_LOADMOD: TP301.1, U2.2 (LOADMOD)
/NFC_LOOP_A: AE1.1, C310.1, C311.1, R303.2, R305.1
/NFC_LOOP_B: AE1.2, C310.2, C312.1, R304.2
/NFC_OSCIN: C306.1, U2.14 (OSCIN), Y301.1
/NFC_OSCOUT: C307.1, U2.15 (OSCOUT), Y301.3
/NFC_RESET_N: R302.1, U2.38 (~RSTPD), U18.7 (P3)
/NFC_RX: C318.2, R306.2, U2.10 (RX)
/NFC_RX_AC: C318.1, R305.2
/NFC_SVDD: C305.1, U2.37 (SVDD)
/NFC_TX1: L301.1, U2.4 (TX1)
/NFC_TX1_F: C308.1, L301.2, R303.1
/NFC_TX2: L302.1, U2.6 (TX2)
/NFC_TX2_F: C309.1, L302.2, R304.1
/NFC_VMID: C301.1, R306.1, U2.9 (VMID)
/PAIR_N: R509.1, R606.2, SW6.1
/PWR_3V3_PG: R119.1, U6.2
/PWR_SW_ON: R116.2, SW5.3 (C)
/RGB_BUF_5V: R605.1, U20.4
/RGB_D1_2: LED1.2 (DOUT), LED2.4 (DIN)
/RGB_D2_3: LED2.2 (DOUT), LED3.4 (DIN)
/RGB_D3_4: LED3.2 (DOUT), LED4.4 (DIN)
/RGB_DATA: U1.18 (IO10), U20.2
/RGB_DIN1: LED1.4 (DIN), R605.2
/RTC_OSCI: U12.1 (OSCI), Y701.1
/RTC_OSCO: U12.2 (OSCO), Y701.2
/SD_CS_DEV: J2.2 (DAT3/CD), R510.2, R515.1, U19.1 (IO1)
/SD_CS_N: R510.1, U1.10 (IO17)
/SD_DAT1: J2.8 (DAT1), R518.1
/SD_DAT2: J2.1 (DAT2), R514.1
/SD_DETECT_N: J2.10 (DET_A), R519.1, U9.4 (P00)
/SD_MISO: J2.7 (DAT0), R513.2, R517.1, U19.6 (IO4)
/SD_MOSI: J2.3 (CMD), R511.2, R516.1, U19.3 (IO2)
/SD_SCK: J2.5 (CLK), R512.2, U19.4 (IO3)
/SPI_MISO: R403.1, R513.1, R734.1, U1.21 (IO13), U22.4
/SPI_MISO_HDR: J5.27, R734.2, U25.1 (IO1)
/SPI_MOSI: R129.2, R511.1, R733.1, U1.19 (IO11), U21.12
/SPI_MOSI_HDR: J5.26, R733.2, U25.3 (IO2)
/SPI_MOSI_JMP: R129.1, R402.1
/SPI_SCK: R401.1, R512.1, R732.1, U1.20 (IO12), U21.5
/SPI_SCK_HDR: J5.25, R732.2, U25.4 (IO3)
/STRAP_BOOT_TP: TP202.1, U1.16 (IO46)
/STRAP_VDD_SPI_TP: TP203.1, U1.26 (IO45)
/SUBGHZ_CS_N: R404.1, U1.22 (IO14)
/SUBGHZ_GDO0: U1.8 (IO15), U3.18
/SUBGHZ_GDO2: U1.9 (IO16), U3.20
/SUBGHZ_RF_ANT: A1.1, C404.1, R405.2
/SUBGHZ_RF_MOD: C403.1, R405.1, U3.6
/SUB_CS_N: R404.2, R406.1, U3.14
/SUB_MISO: R403.2, U3.12
/SUB_MOSI: R402.2, U3.13
/SUB_SCK: R401.2, U3.15
/U6_FB: R117.2, R118.1, U6.5
/U6_L1: L6.1, U6.11
/U6_L2: L6.2, U6.9
/U6_PS_SYNC: R735.1, SW5.2 (B), U6.1, U6.14
/U6_VAUX: C107.1, U6.3
/U7_FB: C113.2, R120.2, R121.1, U7.1
/U7_SW: L7.2, U7.5
/U15_ILIM: R123.1, U15.5
/USB_CC1: J1.A5 (CC1), R101.1, U16.4 (I/O3)
/USB_CC2: J1.B5 (CC2), R102.1, U16.6 (I/O4)
/USB_CONN_N: J1.A7 (D-), J1.B7 (D-), R201.1, U16.3 (I/O2)
/USB_CONN_P: J1.A6 (D+), J1.B6 (D+), R202.1, U16.1 (I/O1)
/USB_D_N: R201.2, U1.13 (USB_D-)
/USB_D_P: R202.2, U1.14 (USB_D+)
/USB_SHIELD: C101.1, J1.SH (SHIELD), R103.1
/USER_BUTTON_A_N: R608.1, SW3.1, U18.11 (P6)
/USER_BUTTON_B_N: R609.1, SW4.1, U18.12 (P7)
/USER_BUTTON_SELECT_N: R607.1, SW7.1, U9.11 (P07)
/VBUS_FUSED: C103.1, C106.1, D101.1 (K), F1.2, TP106.1, U5.13 (IN), U16.5 (VBUS)
/VBUS_USB: F1.1, J1.A4 (VBUS), J1.A9 (VBUS), J1.B4 (VBUS), J1.B9 (VBUS), TP105.1
/VSYS: C105.1, C108.1, C109.1, C114.1, C122.1, C123.1, L7.1, R116.1, TP107.1, U5.10 (OUT), U5.11 (OUT), U6.12, U6.13, U7.3
unnamed: SW8.1, U1.23 (IO21)

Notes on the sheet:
01 USB / BATTERY / POWER
02 ESP32-S3 MCU / USB
03 PN532 NFC / TUNABLE LOOP
04 E07 CC1101 SUB-GHZ
05 LF RFID / SECURITY / MICROSD
06 IR / RGB / BUTTONS
07 SENSORS / RTC / IO EXPANSION

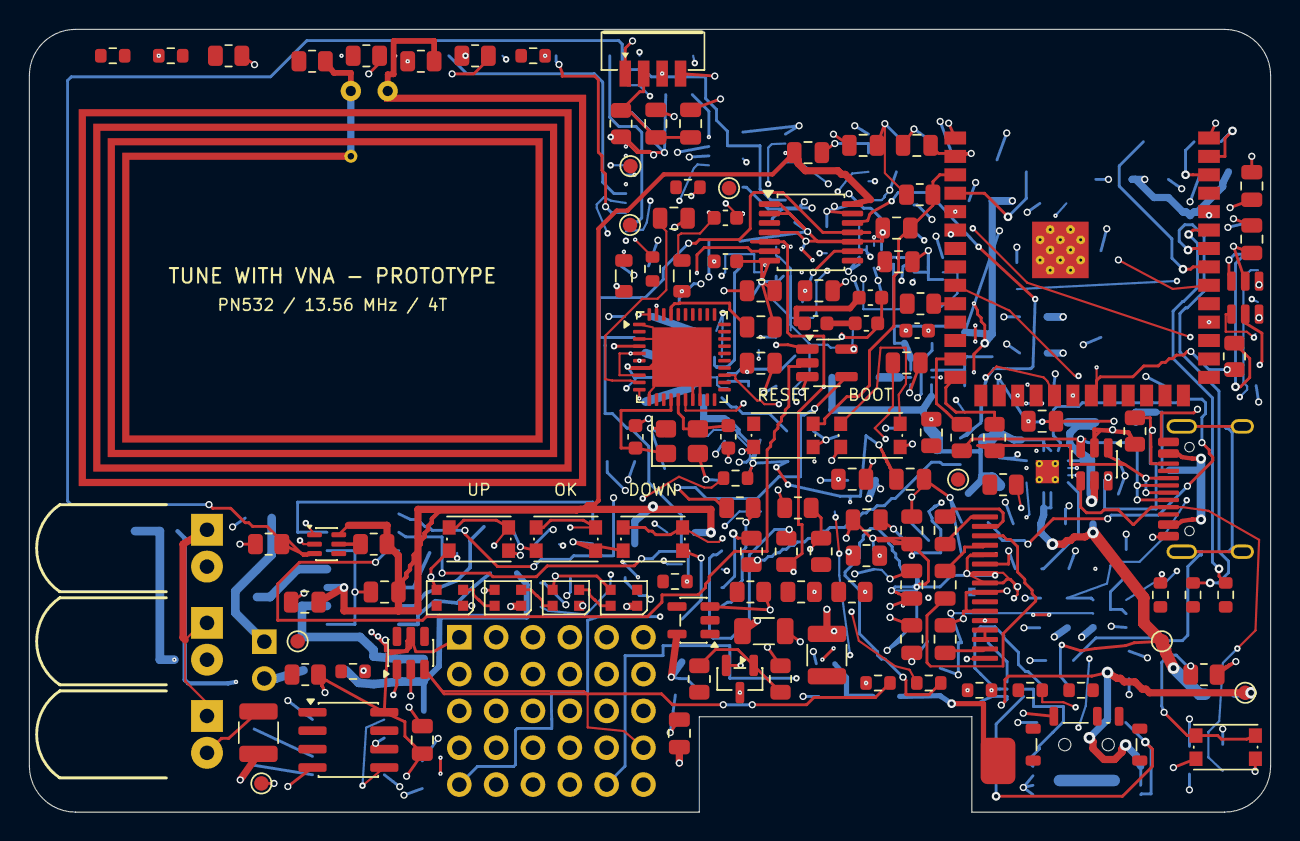
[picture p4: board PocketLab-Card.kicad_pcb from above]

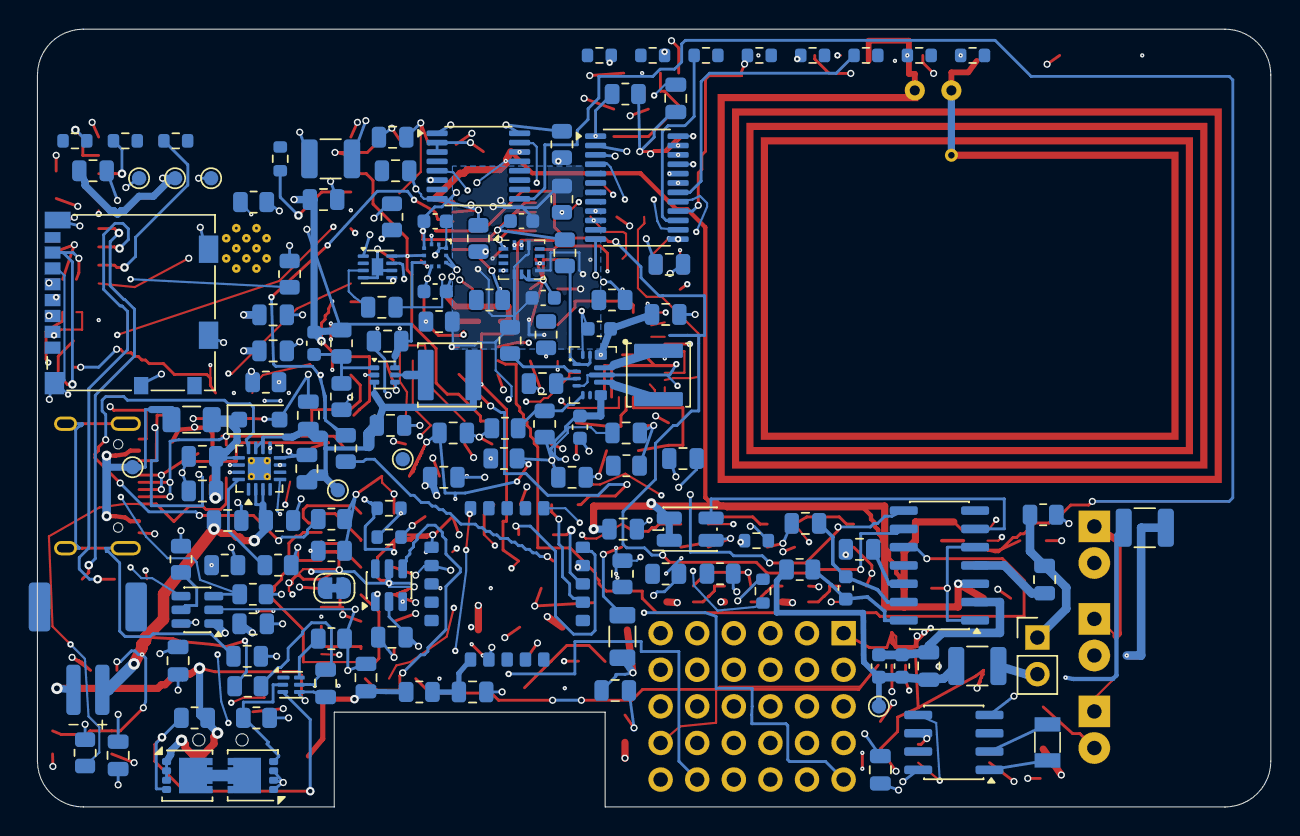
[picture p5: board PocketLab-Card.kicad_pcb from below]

Board: 4 copper layers, 85.6 x 54.0 mm, 267 parts (140 on the bottom side), 181 nets.

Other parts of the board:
C610, C611: 1uF X7R; C_0805_2012Metric
C612, C616: 100nF X7R; C_0805_2012Metric
C613, C615: 4.7uF X5R; C_0805_2012Metric
C614: 2.2uF X7R; C_0805_2012Metric
J8: ER-OLED0.42-1W 72x40 SSD1306B; EastRising_ER-OLED0.42-1W_SolderFPC

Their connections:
/+3V3: C612.1, C613.1, J8.5, J8.7, J8.8; also elsewhere on the board
/ESP_EN: J8.10; also elsewhere on the board
/GND: C612.2, C613.2, C614.2, C615.2, C616.2, J8.6, J8.9, J8.11; also elsewhere on the board
/I2C_SCL: J8.12; also elsewhere on the board
/I2C_SDA: J8.13, J8.14; also elsewhere on the board
/OLED_C1N: C611.2, J8.4
/OLED_C1P: C611.1, J8.3
/OLED_C2N: C610.2, J8.2
/OLED_C2P: C610.1, J8.1
/OLED_VCC: C615.1, C616.1, J8.16
/OLED_VCOMH: C614.1, J8.15

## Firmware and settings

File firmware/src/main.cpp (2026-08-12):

#include <Arduino.h>

#include "firmware_config.h"
#include "hardware_manager.h"
#include "storage_manager.h"
#include "web_portal.h"

namespace {

pocketlab::HardwareManager hardware;
pocketlab::StorageManager storage;
pocketlab::WebPortal web(hardware, storage);

}  // namespace

void setup() {
  Serial.begin(115200);
  const uint32_t serialWaitStarted = millis();
  while (!Serial && millis() - serialWaitStarted < 1500) delay(10);

  Serial.println();
  Serial.printf("%s firmware %s (HW rev %d)\n", pocketlab::config::FIRMWARE_NAME,
                pocketlab::config::FIRMWARE_VERSION, POCKETLAB_CARD_HW_REV);
  Serial.println(F("Initializing outputs in safe state..."));

  hardware.begin();
  const bool sdMounted = storage.begin();
  const bool webStarted = web.begin();

  Serial.printf("microSD: %s\n", sdMounted ? "mounted" : "not detected");
  Serial.printf("Web portal: %s\n", webStarted ? "ready" : "failed");
  if (webStarted) {
    Serial.printf("Wi-Fi SSID: %s\n", web.ssid().c_str());
    Serial.printf("Wi-Fi password: %s\n", web.password().c_str());
    Serial.println(F("Open http://192.168.4.1/ after connecting."));
  }
  Serial.printf("TX policy: Sub-GHz=%s IR=%s GPIO-output=%s\n",
                pocketlab::config::SUBGHZ_TX_COMPILED ? "compiled" : "locked",
                pocketlab::config::IR_TX_COMPILED ? "compiled" : "locked",
                pocketlab::config::GPIO_OUTPUT_COMPILED ? "compiled" : "locked");
}

void loop() {
  hardware.poll();
  web.poll();
  delay(1);
}

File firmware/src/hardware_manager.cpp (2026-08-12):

#include "hardware_manager.h"

#include <cmath>

#include "board_pins.h"
#include "firmware_config.h"
#include "json_util.h"

namespace pocketlab {
namespace {

constexpr uint8_t TCA9535_INPUT_PORT_0 = 0x00;
constexpr uint8_t TCA9535_INPUT_PORT_1 = 0x01;
constexpr uint8_t TCA9535_OUTPUT_PORT_0 = 0x02;
constexpr uint8_t TCA9535_OUTPUT_PORT_1 = 0x03;
constexpr uint8_t TCA9535_POLARITY_PORT_0 = 0x04;
constexpr uint8_t TCA9535_POLARITY_PORT_1 = 0x05;
constexpr uint8_t TCA9535_CONFIG_PORT_0 = 0x06;
constexpr uint8_t TCA9535_CONFIG_PORT_1 = 0x07;

constexpr uint8_t TCA9534_INPUT_PORT = 0x00;
constexpr uint8_t TCA9534_OUTPUT_PORT = 0x01;
constexpr uint8_t TCA9534_POLARITY_PORT = 0x02;
constexpr uint8_t TCA9534_CONFIG_PORT = 0x03;
constexpr uint8_t TCA9534_CONTROL_INPUT_MASK = 0xC0;

constexpr uint8_t CC1101_PARTNUM = 0x30;
constexpr uint8_t CC1101_VERSION = 0x31;
constexpr uint8_t CC1101_READ_BURST = 0xC0;

bool isDirectExpansionPin(uint8_t gpio) {
  for (const uint8_t candidate : pins::DIRECT_EXPANSION) {
    if (candidate == gpio) return true;
  }
  return false;
}

}  // namespace

void HardwareManager::setSafeOutput(uint8_t pin, uint8_t level) {
  digitalWrite(pin, level);
  pinMode(pin, OUTPUT);
}

void HardwareManager::begin() {
  // Inactive levels are established before switching the pads to outputs.
  setSafeOutput(pins::SUBGHZ_CS_N, HIGH);
  setSafeOutput(pins::SD_CS_N, HIGH);
  setSafeOutput(pins::IR_TX, LOW);
  setSafeOutput(pins::RGB_DATA, LOW);
  setSafeOutput(pins::LF_SCLK, HIGH);
  setSafeOutput(pins::LF_DIN, LOW);

  pinMode(pins::NFC_IRQ_N, INPUT_PULLUP);
  pinMode(pins::SUBGHZ_GDO0, INPUT);
  pinMode(pins::SUBGHZ_GDO2, INPUT);
  pinMode(pins::LF_DOUT, INPUT);
  pinMode(pins::PAIR_N, INPUT_PULLUP);
  pinMode(pins::IR_RX, INPUT_PULLUP);
  pinMode(pins::IOEXP_INT_N, INPUT_PULLUP);
  pinMode(pins::BOARD_TEMP_ADC, INPUT);
  analogReadResolution(12);
  analogSetPinAttenuation(pins::BOARD_TEMP_ADC, ADC_11db);

  // Expansion pins never become outputs unless a future, separately audited
  // firmware build explicitly enables that capability.
  for (const uint8_t gpio : pins::DIRECT_EXPANSION) {
    pinMode(gpio, INPUT);
  }

  Wire.begin(pins::I2C_SDA, pins::I2C_SCL, config::I2C_FREQUENCY_HZ);
  SPI.begin(pins::SPI_SCK, pins::SPI_MISO, pins::SPI_MOSI);

  status_.statusExpanderPresent = configureStatusExpander();
  status_.controlExpanderPresent = configureControlExpander();
  if (status_.controlExpanderPresent) {
    // U18 is configured with every controlled rail disabled and PN532 held in
    // reset. Releasing reset here only boots PN532; no RF command is issued.
    delay(10);
    if (setControlOutput(static_cast<uint8_t>(pins::ControlExpanderPin::NfcResetN), true)) {
      delay(20);
      updateControlExpanderInputs();
    }
  }
  if (status_.statusExpanderPresent) updateStatusExpanderInputs();

  status_.nfcResponding = probeI2cAddress(config::PN532_I2C_ADDRESS);
  status_.secureElementPresent = probeSecureElement();
  status_.pairButtonPressed = digitalRead(pins::PAIR_N) == LOW;
  updateBoardTemperature();
  probeSubGhz();
  lastPollMs_ = millis();
}

void HardwareManager::poll() {
  const uint32_t now = millis();
  if (now - lastPollMs_ < 2000) return;
  lastPollMs_ = now;

  if (status_.statusExpanderPresent) updateStatusExpanderInputs();
  if (status_.controlExpanderPresent) updateControlExpanderInputs();
  status_.nfcResponding = probeI2cAddress(config::PN532_I2C_ADDRESS);
  status_.pairButtonPressed = digitalRead(pins::PAIR_N) == LOW;
  updateBoardTemperature();
  status_.pairingWindowOpen = pairingWindowUntilMs_ != 0 &&
                              static_cast<int32_t>(pairingWindowUntilMs_ - now) > 0;
  if (!status_.pairingWindowOpen) pairingWindowUntilMs_ = 0;
}

bool HardwareManager::probeI2cAddress(uint8_t address) {
  Wire.beginTransmission(address);
  return Wire.endTransmission(true) == 0;
}

bool HardwareManager::configureStatusExpander() {
  if (!probeI2cAddress(config::TCA9535_STATUS_ADDRESS)) return false;

  // U9 is strictly input-only: eight internal status lines and EX0..EX7.
  // Explicit polarity and output-latch values make later diagnostics
  // deterministic without ever changing a pin to output mode.
  if (!writeI2cRegister(config::TCA9535_STATUS_ADDRESS, TCA9535_OUTPUT_PORT_0, 0x00)) {
    return false;
  }
  if (!writeI2cRegister(config::TCA9535_STATUS_ADDRESS, TCA9535_OUTPUT_PORT_1, 0x00)) {
    return false;
  }
  if (!writeI2cRegister(config::TCA9535_STATUS_ADDRESS, TCA9535_POLARITY_PORT_0, 0x00)) {
    return false;
  }
  if (!writeI2cRegister(config::TCA9535_STATUS_ADDRESS, TCA9535_POLARITY_PORT_1, 0x00)) {
    return false;
  }
  if (!writeI2cRegister(config::TCA9535_STATUS_ADDRESS, TCA9535_CONFIG_PORT_0, 0xFF)) {
    return false;
  }
  if (!writeI2cRegister(config::TCA9535_STATUS_ADDRESS, TCA9535_CONFIG_PORT_1, 0xFF)) {
    return false;
  }
  return true;
}
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

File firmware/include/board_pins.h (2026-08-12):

#pragma once

#include <stdint.h>

namespace pocketlab::pins {

// Boot and shared buses
inline constexpr uint8_t BOOT_N = 0;
inline constexpr uint8_t I2C_SDA = 5;
inline constexpr uint8_t I2C_SCL = 6;
inline constexpr uint8_t SPI_MOSI = 11;
inline constexpr uint8_t SPI_SCK = 12;
inline constexpr uint8_t SPI_MISO = 13;

// NFC
inline constexpr uint8_t NFC_IRQ_N = 7;

// LEDs
inline constexpr uint8_t RGB_DATA = 10;

// Sub-GHz
inline constexpr uint8_t SUBGHZ_CS_N = 14;
inline constexpr uint8_t SUBGHZ_GDO0 = 15;
inline constexpr uint8_t SUBGHZ_GDO2 = 16;

// Storage
inline constexpr uint8_t SD_CS_N = 17;

// 125-kHz LF RFID (HTRC110 through 3.3-V/5-V level translators)
inline constexpr uint8_t LF_SCLK = 18;
inline constexpr uint8_t LF_DOUT = 21;
inline constexpr uint8_t LF_DIN = 35;

// Dedicated physical app-pairing button
inline constexpr uint8_t PAIR_N = 38;

// Native USB
inline constexpr uint8_t USB_D_N = 19;
inline constexpr uint8_t USB_D_P = 20;

// I/O expander interrupt
inline constexpr uint8_t IOEXP_INT_N = 39;

// Infrared
inline constexpr uint8_t IR_TX = 36;
inline constexpr uint8_t IR_RX = 37;

// Internal 10-k NTC divider. J5 pin 7 is only a protected, high-impedance
// probe point for this node; GPIO9 must never be driven.
inline constexpr uint8_t BOARD_TEMP_ADC = 9;

// Direct expansion GPIOs
inline constexpr uint8_t DIRECT_EXPANSION[] = {
    1, 2, 4, 8, 40, 41, 42, 43, 44, 47, 48,
};

// U9 / TCA9535 at 0x20. Both ports remain inputs; P10-P17 are EX0-EX7.
enum class StatusExpanderPin : uint8_t {
  SdDetectN = 0,
  ChargerN = 1,
  ChargerPowerGoodN = 2,
  Aux5FaultN = 3,
  FuelGaugeAlertN = 4,
  BmiInt1 = 5,
  BmiInt2 = 6,
  BmpInt = 7,
  Ex0 = 8,
  Ex1 = 9,
  Ex2 = 10,
  Ex3 = 11,
  Ex4 = 12,
  Ex5 = 13,
  Ex6 = 14,
  Ex7 = 15,
};

// U18 / TCA9534 at 0x21. P0-P5 are outputs and P6-P7 are inputs.
enum class ControlExpanderPin : uint8_t {
  ChargerUsbModeEn1 = 0,
  ChargerDisable = 1,
  Aux5Enable = 2,
  NfcResetN = 3,
  LfRfidPowerEnable = 4,
  Boost5Enable = 5,
  UserButtonAN = 6,
  UserButtonBN = 7,
};

}  // namespace pocketlab::pins

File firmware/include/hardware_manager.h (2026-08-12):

#pragma once

#include <Arduino.h>
#include <SPI.h>
#include <Wire.h>

namespace pocketlab {

struct HardwareStatus {
  bool statusExpanderPresent = false;
  bool controlExpanderPresent = false;
  bool nfcResponding = false;
  bool subGhzResponding = false;
  bool nfcResetReleased = false;
  bool chargerUsb100Mode = true;
  bool chargerDisabled = false;
  bool aux5Enabled = false;
  bool lfRfidPowerEnabled = false;
  bool lfRfidTransportOk = false;
  bool lfAntennaFail = true;
  bool secureElementPresent = false;
  bool pairButtonPressed = false;
  bool pairingWindowOpen = false;
  uint8_t lfPhase = 0xFF;
  uint8_t lfSamplingTime = 0xFF;
  bool boost5Enabled = false;
  bool sdDetected = false;
  bool chargerActive = false;
  bool externalPowerGood = false;
  bool aux5FaultActive = false;
  bool fuelGaugeAlertActive = false;
  bool bmiInt1 = false;
  bool bmiInt2 = false;
  bool bmpInt = false;
  bool userButtonAPressed = false;
  bool userButtonBPressed = false;
  bool boardTemperatureValid = false;
  bool boardOverTemperature = false;
  float boardTemperatureC = 0.0F;
  uint8_t cc1101PartNumber = 0xFF;
  uint8_t cc1101Version = 0xFF;
  uint8_t statusInputs0 = 0xFF;
  uint8_t expansionInputs = 0xFF;
  uint8_t controlInputs = 0xFF;
};

class HardwareManager {
 public:
  void begin();
  void poll();

  bool setLfRfidPower(bool enabled);
  bool diagnoseLfRfid();
  bool armPairingWindow();
  bool setBoost5(bool enabled);
  bool sendIrNec(uint8_t address, uint8_t command, uint8_t repeats = 0);
  bool readDirectGpio(uint8_t gpio, bool &level) const;

  const HardwareStatus &status() const { return status_; }
  String statusJson() const;

 private:
  static void setSafeOutput(uint8_t pin, uint8_t level);
  bool probeI2cAddress(uint8_t address);
  bool configureStatusExpander();
  bool configureControlExpander();
  bool writeI2cRegister(uint8_t address, uint8_t reg, uint8_t value);
  bool readI2cRegister(uint8_t address, uint8_t reg, uint8_t &value);
  bool setControlOutput(uint8_t bit, bool high);
  bool probeSecureElement();
  void htrcInitializeInterface();
  void htrcWriteBits(uint8_t value, uint8_t count);
  uint8_t htrcCommandWithResponse(uint8_t command);
  void htrcCommand(uint8_t command);
  bool configureHtrc110();
  uint8_t readCc1101StatusRegister(uint8_t address);
  void probeSubGhz();
  void updateStatusExpanderInputs();
  void updateControlExpanderInputs();
  void updateBoardTemperature();
  void enforceThermalShutdown();
  static void sendIrMark(uint32_t durationUs);
  static void sendIrSpace(uint32_t durationUs);
  static void sendIrByteLsb(uint8_t value);

  HardwareStatus status_;
  uint8_t controlOutputs_ = 0;
  uint32_t lastPollMs_ = 0;
  uint32_t lastIrTxMs_ = 0;
  uint32_t pairingWindowUntilMs_ = 0;
  bool lfOwnsBoost_ = false;
};

}  // namespace pocketlab

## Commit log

2026-08-08 Initial PocketLab Card architecture
    [preliminary-bom.csv]
2026-08-08 Add hand-assembly hardware baseline
    [01_USB_POWER.kicad_sch, 02_MCU.kicad_sch, 03_NFC.kicad_sch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]
2026-08-08 Add physical component placement draft
    [PocketLab-Card-mechanical.kicad_pcb, PocketLab-Card.kicad_pcb]
2026-08-09 Save complete schematic and firmware checkpoint
    [PocketLab-Card.kicad_sch]
2026-08-12 Publish current PocketLab Card hardware checkpoint
    Publishes the current hardware and documentation checkpoint while removing obsolete renders, empty placeholder sheets, generated PCB/autorouter intermediates, and duplicate staging reports. Generated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
    [01_USB_POWER.kicad_sch, 02_MCU.kicad_sch, 03_NFC.kicad_sch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]
2026-08-12 Route LF RFID analog island
    [PocketLab-Card.kicad_pcb]
2026-08-12 Save shared-SPI LF and plane-fanout checkpoint
    [PocketLab-Card.kicad_pcb, PocketLab-Card.kicad_sch]
2026-08-16 Save PCBA routing optimization checkpoint
    [PocketLab-Card-pcba-routing-wip.kicad_pcb, PocketLab-Card.kicad_pcb, PocketLab-Card.kicad_sch]
2026-08-16 Archive large-component PCB checkpoint
    [PocketLab-Card-large-components.kicad_pcb]
2026-08-17 Advance reviewed PCB routing checkpoint
    [PocketLab-Card.kicad_pcb]
2026-08-20 Route protected GPIO43 to expansion header
    [PocketLab-Card.kicad_pcb]
2026-08-20 Route protected SPI MISO header branch
    [PocketLab-Card.kicad_pcb]
2026-08-20 Route PN532 TX1 driver branch
    [PocketLab-Card.kicad_pcb]
2026-08-20 Route OLED VCC supply branch
    [PocketLab-Card.kicad_pcb]
2026-08-20 Route CELL_POS sense branch
    [PocketLab-Card.kicad_pcb]
2026-08-21 Place CELL_NEG test point on routed trunk
    [PocketLab-Card.kicad_pcb]
2026-08-21 Place CELL_POS test point on routed trunk
    [PocketLab-Card.kicad_pcb]
2026-08-21 Place VBUS_USB test point on back trunk
    [PocketLab-Card.kicad_pcb]
2026-08-21 Checkpoint active PCB routing and tooling
    [PocketLab-Card.kicad_pcb]
2026-08-28 Checkpoint zero-open routing and cleanup tooling
    [PocketLab-Card-routing-working.kicad_pcb, PocketLab-Card.kicad_pcb, PocketLab-Card.kicad_sch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]
2026-08-28 Remove copper sliver and GPIO8 edge faults
    [PocketLab-Card-routing-working.kicad_pcb]
2026-08-28 Make USB connector P join via-free
    [PocketLab-Card-routing-working.kicad_pcb]
2026-08-29 Save conventional via cleanup checkpoint
    [PocketLab-Card-routing-working.kicad_pcb]
2026-08-29 Improve routed inner-layer conflict profile
    [PocketLab-Card-routing-working.kicad_pcb]
2026-08-29 Reroute user button conflict corridor
    [PocketLab-Card-routing-working.kicad_pcb]
2026-08-29 Refine congested routing corridors
    [PocketLab-Card-routing-working.kicad_pcb]
2026-08-29 Reroute EX5 outside restricted copper
    [PocketLab-Card-routing-working.kicad_pcb]
